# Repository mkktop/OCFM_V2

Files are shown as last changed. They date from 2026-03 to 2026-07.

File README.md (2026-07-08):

# OCFM_V2 - 明渠流量计

**Open Channel Flow Meter Firmware V2**

基于 STM32F407 的智能明渠流量计固件，通过超声波/雷达水位计测量水位，结合标准堰槽公式（巴歇尔槽、三角堰、矩形堰）计算瞬时流量和累计流量。适用于污水处理、水利灌溉、环保监测等场景。

## 功能特性

- **多堰槽类型支持** - 巴歇尔槽（25种：17种标准型 b=0.025~2.4m + 8种大型 b=3.05~12.19m，标准 CJ/T 3008.3）、三角堰（5种标准角度，ISO 1438）、矩形堰（4种标准宽度，ISO 1438）
- **传感器接口** - 支持雷达/超声波水位传感器，Modbus RTU 通信
- **实时数据采集** - 水位、瞬时流量、累计流量、温度实时监测
- **趋势图显示** - 双采样率折线图（10s / 5min），各30个数据点，Y轴自动缩放
- **历史数据记录** - 按日期分目录 CSV 存储，支持时间范围查询与聚合统计，默认保留 365 天（满足 HJ 15-2019 运行数据保存要求）
- **4-20mA 电流输出** - 可配置量程，PWM 驱动 V/I 转换，支持工厂校准
- **Modbus RTU 从机** - 标准保持寄存器映射，支持远程读写配置与数据采集
- **多级报警** - 上限/下限/上上限/下下限四组报警，带回差设置
- **4路继电器输出** - 可由报警或流量阈值驱动
- **数据持久化** - 累计流量双层保护（RTC备份寄存器 + EEPROM），断电不丢失
- **SD卡数据存储** - 历史数据、系统日志、用户日志、报警日志
- **LVGL 图形界面** - 2.8寸彩色 LCD，三级设置菜单，中英文切换，按键操作

## 硬件规格

| 项目 | 规格 |
|---|---|
| MCU | STM32F407VGTx (Cortex-M4, 168MHz, FPU) |
| LCD | 2.8寸 ST7789 (FSMC 8080并口) |
| 传感器接口 | UART1 RS485 (Modbus RTU 主机) |
| 通信接口 | UART2 RS485 (Modbus RTU 从机) + UART4 (4G模块 ML307, 未实现) |
| 无线 | LoRa (SX1278, SPI2, 未实现) |
| 存储 | EEPROM M24C02 (I2C2) + SD卡 (SDIO) |
| 温度 | CT1820 (1-Wire, PB0) |
| 按键 | 4路 (确认/上/下/位移) |
| 继电器 | 4路 |
| 蜂鸣器/背光 | TIM3 PWM |

## 软件架构

```
OCFM_V2/
├── Core/                    # STM32 HAL & CubeMX 生成代码
│   ├── Inc/global.h         # 全局配置、寄存器定义、SystemConfig_t
│   ├── Inc/rtc_time.h       # 统一 RTC 时间 API
│   └── Src/                 # 外设初始化 (main.c, freertos.c)
├── App/                     # 应用层
│   ├── ui/                  # LVGL UI (Tileview主屏、三级设置菜单、趋势图、历史查询、多语言)
│   ├── app_model.c/h        # 数据模型 (MVVM, Observer模式)
│   ├── app_config.c/h       # 系统配置 (EEPROM, getter/setter, 3秒延迟保存)
│   ├── app_flow_calc.c/h    # 流量计算 (堰槽公式, 累计流量双层持久化)
│   ├── app_sensor.c/h       # 传感器应用层 (Modbus主机封装, 首次上线自动同步)
│   ├── app_modbus_slave.c/h # Modbus从机 (寄存器映射, 写回调)
│   ├── app_alarm.c/h        # 报警滞回逻辑 (4级报警驱动4路继电器)
│   ├── app_current.c/h      # 4-20mA电流输出 (PWM → V/I转换, 工厂校准)
│   ├── app_button.c/h       # 按键处理 (按活动屏分发)
│   └── app_log.c/h          # 日志初始化与SD卡清除
├── Drivers/
│   ├── AT24C02/             # EEPROM 驱动
│   ├── Button/              # 按键驱动 (消抖/长按)
│   ├── CT1820/              # 温度传感器驱动
│   └── File/                # 文件系统抽象层
│       ├── file_driver.c/h  # FATFS 封装
│       ├── data_recorder.c/h# CSV 历史数据记录
│       └── log_manager.c/h  # 系统日志管理
├── Interface/
│   ├── modbus.c/h           # Modbus 协议栈
│   ├── modbus_master.c/h    # Modbus 主机
│   └── modbus_slave.c/h     # Modbus 从机
├── Middlewares/
│   ├── lvgl/                # LVGL 9.5.0
│   └── Third_Party/         # FreeRTOS, FatFs
└── Doc/                     # 硬件原理图 & 技术文档
```

## 技术栈

| 组件 | 版本 |
|---|---|
| RTOS | FreeRTOS 10.3.1 |
| GUI | LVGL 9.5.0 |
| 文件系统 | FatFs |
| HAL | STM32F4xx HAL |
| 构建工具 | Keil MDK-ARM (AC5) |

## FreeRTOS 任务架构

| 任务 | 栈 | 优先级 | 功能 |
|---|----|---|---|
| main_task | 8192 | Normal | LVGL 刷新 + 模块初始化 |
| log_task | 8192 | Low | 日志输出、EEPROM保存、数据记录、历史查询、RTC 更新 |
| button_scan_tas | 2048 | Low | 按键扫描 (10ms) |
| modbus_master_t | 1024 | Low | 传感器轮询 (10ms) |
| modbus_slave_ta | 1024 | Low | 从机通信 (10ms, 1s 数据同步) |

## 流量计算公式

- **巴歇尔槽 (Parshall Flume)** — Q = K × H^n（25种标准规格，标准 CJ/T 3008.3）
- **三角堰 (Triangular Weir)** — Q = K × (H+Kh)^2.5（90°/60°/45°/30°/22.5°，Kindsvater-Shen 方法，ISO 1438）
- **矩形堰 (Rectangular Weir)** — Q = K × b_eff × (H+Kh)^1.5（0.5/1.0/1.5/2.0m，Francis 公式 + 侧收缩修正，ISO 1438）

> 公式系数表、推导、标准出处与 HJ 15-2019 合规验证详见 [Doc/流量计算公式与标准说明.md](Doc/流量计算公式与标准说明.md)。

支持流量单位：L/s、L/min、L/h、m³/h、m³/s、m³/min、T/h、G/h

## Modbus RTU 寄存器映射 (部分)

| 地址 | 名称 | 类型 | 说明 |
|---|---|---|---|
| 0x0001 | REG_WUWEI | uint16 | 水位 |
| 0x0002 | REG_DISTANCE | uint16 | 距离 |
| 0x0003 | REG_TEMPERATURE | uint16 | 温度 |
| 0x0004-0x0005 | REG_INSTANT_FLOW | float | 瞬时流量 |
| 0x0006-0x0009 | REG_SUM_FLOW | double | 累计流量 |
| 0x000A-0x000D | 继电器状态 | uint16 x4 | 继电器 1-4 |
| 0x000E-0x0019 | 报警值 | float | 上限/下限/上上限/下下限及回差 (DH/DL) |
| 0x001A-0x001B | REG_TOTAL_TIME | uint32 | 累计计量时间 (秒)，与累计流量配对 |
| 0x0065-0x006F | 传感器参数 | uint16 | 量程、高度、滤波、地址、波特率等 |
| 0x0101-0x010D | 从机参数 | uint16/float | 渠道类型、流量单位、4-20mA量程、渠宽、堰高、水位上下限 |
| 0x1001-0x1006 | 工厂校准 | uint16 | 天线类型、距离偏移、4/20mA校准、恢复出厂、清除累计 |
| 0x0200-0x0206 | RTC 时间 | uint16 | 年月日时分秒星期 |

## 构建与烧录

1. 打开 Keil 工程文件 `MDK-ARM/OCFM_V2.uvprojx`
2. 编译: `Project -> Build Target` (F7)
3. 下载: `Flash -> Download` (F8)

> 硬件外设、引脚、时钟树配置通过 CubeMX 打开 `OCFM_V2.ioc` 修改后重新生成，请勿手动改动 HAL 初始化代码。

## 相关文档

| 文档 | 说明 |
|---|---|
| [CLAUDE.md](CLAUDE.md) | 项目开发指南（架构、规范、模块设计决策） |
| [Doc/流量计算公式与标准说明.md](Doc/流量计算公式与标准说明.md) | 堰槽公式系数表、推导、标准出处、HJ 15-2019 合规 |
| [Doc/数据记录CSV与报警标志说明.md](Doc/数据记录CSV与报警标志说明.md) | CSV 记录字段格式与报警标志位定义 |
| [Docs/Modbus寄存器表.md](Docs/Modbus寄存器表.md) | Modbus 寄存器完整映射表 |
| [Doc/](Doc/) | 硬件原理图 (.SchDoc)、PCB 文件、行业标准与技术规范 |

## UI 交互

- **主屏幕** — 垂直瓦片视图：详情页 / 趋势图页 / 累计流量页，上下键切换
- **设置菜单** — 三级结构：分类列表 -> 参数列表 -> 数值编辑，SHIFT键切换步进量级
- **历史查询** — 长按SHIFT进入，日期选择器 + 滑动窗口浏览
- **自动返回** — 设置页面 15 秒无操作自动返回主屏幕

## 许可证

本项目为私有项目，未经授权不得复制或分发。

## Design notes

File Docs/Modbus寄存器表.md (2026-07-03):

# OCFM_V2 Modbus RTU 寄存器表

**通信参数：** RS485 | Modbus RTU | 从机地址默认 1 | 波特率默认 9600 | 8N1

**寄存器类型：** 保持寄存器 (Function Code 03 读 / 06 写单寄存器 / 16 写多寄存器)

**数据格式：**
- `uint16` — 1 个寄存器（16 位无符号）
- `float` — 2 个连续寄存器（IEEE 754，大端序）
- `double` — 4 个连续寄存器（IEEE 754，大端序）

---

## 1. 实时数据区 (只读)

设备自动更新，用户只读。传感器离线时水位和距离不更新。

| 地址 | 名称 | 数据类型 | 单位 | 说明 |
|---|---|---|---|---|
| 0x0001 | 水位 (物位) | uint16 | mm | 水位 = 安装高度 - 传感器到水面距离 |
| 0x0002 | 距离 | uint16 | mm | 传感器到水面的距离 |
| 0x0003 | 温度 | uint16 | 0.1°C | 值 256 = 25.6°C |
| 0x0004~0x0005 | 瞬时流量 | float | 由单位寄存器决定 (默认 m³/h) | 当前瞬时流量值 |
| 0x0006~0x0009 | 累计流量 | double | m³ | 累计总量 |
| 0x000A | 继电器1状态 | uint16 | — | 0=断开, 1=吸合 (AH报警) |
| 0x000B | 继电器2状态 | uint16 | — | 0=断开, 1=吸合 (AL报警) |
| 0x000C | 继电器3状态 | uint16 | — | 0=断开, 1=吸合 (AAH报警) |
| 0x000D | 继电器4状态 | uint16 | — | 0=断开, 1=吸合 (AAL报警) |

> **注意：** 0x000A~0x000D 继电器状态寄存器只读，不允许写入。继电器由报警逻辑自动控制。

---

## 2. 报警参数区 (读写)

| 地址 | 名称 | 数据类型 | 单位 | 默认值 | 说明 |
|---|---|---|---|---|---|
| 0x000E~0x000F | 上限报警值 (AH) | float | m³/h | 19.44 | 流量 ≥ AH 触发，继电器1吸合 |
| 0x0010~0x0011 | 上限回差 (DH) | float | m³/h | 2.0 | 流量 < AH - DH 恢复 |
| 0x0012~0x0013 | 下限报警值 (AL) | float | m³/h | 0.0 | 流量 ≤ AL 触发，继电器2吸合 |
| 0x0014~0x0015 | 下限回差 (DL) | float | m³/h | 2.0 | 流量 > AL + DL 恢复 |
| 0x0016~0x0017 | 上上限报警值 (AAH) | float | m³/h | 100.0 | 流量 ≥ AAH 触发，继电器3吸合；恢复条件: 流量 < AAH - DH |
| 0x0018~0x0019 | 下下限报警值 (AAL) | float | m³/h | 0.0 | 流量 ≤ AAL 触发，继电器4吸合；恢复条件: 流量 > AAL + DL |

---

## 3. 传感器参数区 (读写)

> 写入后自动同步到传感器（传感器在线时）。参数在传感器首次上线时也会自动同步。

| 地址 | 名称 | 数据类型 | 单位 | 默认值 | 说明 |
|---|---|---|---|---|---|
| 0x0065 | 最大量程 | uint16 | mm | 5000 | 传感器量程上限 |
| 0x0066 | 安装高度 | uint16 | mm | 5000 | 传感器安装高度 |
| 0x0067 | 窗口宽度 (L1) | uint16 | — | 100 | 传感器窗口参数 |
| 0x0068 | 滤波次数 (L2) | uint16 | — | 2 | 传感器滤波参数 |
| 0x0069 | 延时时间 (L3) | uint16 | ms | 50 | 传感器采集延迟 |
| 0x006A | 盲区 (L4) | uint16 | mm | 50 | 测量盲区 |
| 0x006B | 窗口系数 (L5) | uint16 | — | 8 | W系数 |
| 0x006C | 测量系数 (L6) | uint16 | — | 3 | M系数 |
| 0x006D | 传感器地址 | uint16 | — | 1 | 传感器从机地址 (1~247) |
| 0x006E | 波特率 | uint16 | — | 2 | 1=4800, 2=9600, 3=14400, 4=19200, 5=38400, 6=56000, 7=57600, 8=115200 |
| 0x006F | 停止位/校验 | uint16 | — | 1 | 1=8N1, 2=8O1, 3=8N2, 4=8E1 |

---

## 4. 从机参数区 (读写)

| 地址 | 名称 | 数据类型 | 单位 | 默认值 | 说明 |
|---|---|---|---|---|---|
| 0x0101 | 渠道类型 | uint16 | — | 1 | 1=巴歇尔槽, 2=三角堰, 3=矩形堰 |
| 0x0102 | 水槽编号 | uint16 | — | 1 | 对应具体堰槽规格 (切换时自动填入默认水位上下限) |
| 0x0103 | 瞬时流量单位 | uint16 | — | 4 | 1=L/s, 2=L/min, 3=L/h, 4=m³/h, 5=m³/s, 6=m³/min, 7=T/h, 8=G/h |
| 0x0104 | 累计流量小数位 | uint16 | — | 1 | 累计流量显示的小数位数 |
| 0x0105~0x0106 | 4mA 量程 | float | m³/h | 0.0 | 4mA 对应的流量值 |
| 0x0107~0x0108 | 20mA 量程 | float | m³/h | 19.354 | 20mA 对应的流量值；不能超过当前槽型理论最大流量 × 1.2 |
| 0x0109 | 渠宽 | uint16 | mm | 0 | 矩形堰侧收缩修正用渠道宽度；0=全宽堰/未配置 |
| 0x010A | 堰高 | uint16 | mm | 0 | 矩形堰堰高 p (预留) |
| 0x010B~0x010C | 水位上限 | float | m | 见表 | 流量计算用的水位上限；切换渠道类型/水槽编号时自动填入默认值 |
| 0x010D~0x010E | 水位下限 | float | m | 见表 | 流量计算用的水位下限；切换渠道类型/水槽编号时自动填入默认值 |

---

## 5. 出厂校准区 (读写)

> **注意：** 4mA / 20mA 校准值写入后直接生效，请使用正确范围内数值。

| 地址 | 名称 | 数据类型 | 单位 | 默认值 | 说明 |
|---|---|---|---|---|---|
| 0x1001 | 天线类型 | uint16 | — | 1 | 传感器天线类型 |
| 0x1002 | 距离偏移 | uint16 | mm | 10 | 测量距离补偿值 |
| 0x1003 | 4mA 校准值 | uint16 | CCR | 1063 | TIM3 CH4 PWM 比较值；写入后立即驱动 PWM 输出 (Modbus 校准) |
| 0x1004 | 20mA 校准值 | uint16 | CCR | 5556 | TIM3 CH4 PWM 比较值；写入后立即驱动 PWM 输出 (Modbus 校准) |
| 0x1005 | 恢复出厂设置 | uint16 | — | 0 | 写入后触发恢复出厂，完成后自动复位为 0 (一次性触发) |
| 0x1006 | 清除累计量 | uint16 | — | — | 写 1 清除累计流量和累计时间 (一次性触发) |

---

## 6. RTC 时间区 (读写)

> 写入任意一个时间寄存器后，设备立即读取全部 7 个寄存器并更新 RTC。建议使用 FC16 一次性写入全部 7 个寄存器。

| 地址 | 名称 | 数据类型 | 范围 | 说明 |
|---|---|---|---|---|
| 0x0200 | 年 | uint16 | 2000~2099 | 如 2026 |
| 0x0201 | 月 | uint16 | 1~12 | — |
| 0x0202 | 日 | uint16 | 1~31 | 自动校验闰年 |
| 0x0203 | 时 | uint16 | 0~23 | — |
| 0x0204 | 分 | uint16 | 0~59 | — |
| 0x0205 | 秒 | uint16 | 0~59 | — |
| 0x0206 | 星期 | uint16 | 1~7 | 1=周一, 7=周日 |

---

## 附：测试要点

1. **读寄存器测试** — 用 FC03 从 0x0001 开始连续读取，验证实时数据是否正常更新（水位、距离、温度、流量）。
2. **写报警值测试** — 用 FC06 写入 AH 值，观察继电器状态变化；降低流量至恢复阈值，观察继电器释放。
3. **写配置测试** — 修改渠道类型 / 水槽编号 / 瞬时单位后，验证流量计算结果变化；断电重启后验证参数持久化。
4. **RTC 测试** — 用 FC16 一次写入 7 个时间寄存器 (0x0200~0x0206)，再读回验证。
5. **清除累计量** — 向 0x1006 写 1，读回 0x0006~0x0009 验证累计流量归零。
6. **恢复出厂** — 向 0x1005 写 1，断电重启后验证所有参数恢复默认值。
7. **传感器离线** — 断开传感器后约 15 秒判定离线，报警清除、继电器全部释放。

---

## 附：从机参数寄存器补充

| 地址 | 范围/默认值 | 说明 |
|---|---|---|
| 0x0109 渠宽 | 0~10000 mm；默认 0 | 0 表示未配置（按全宽堰计算） |
| 0x010A 堰高 | 0~10000 mm；默认 0 | 矩形堰堰高 p (预留) |
| 0x010B 水位上限 | 0~10 m；按槽型自动 | 详见 `flow_calc_formulas.md` 第 1 节 |
| 0x010D 水位下限 | 0~10 m；按槽型自动 | 详见 `flow_calc_formulas.md` 第 1 节 |

切换渠道类型 (0x0101) 或水槽编号 (0x0102) 时，0x010B/0x010D 会被自动覆盖为当前槽型的默认值，原有用户修改会丢失。

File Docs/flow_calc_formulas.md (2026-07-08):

# 明渠流量计算公式手册

> 源文件: [`App/app_flow_calc.c`](../App/app_flow_calc.c)（公式与系数） · [`App/app_sensor.c`](../App/app_sensor.c)（水位采集）
>
> 适用标准:
> - 巴歇尔槽 — **CJ/T 3008.3-1993**《城市排水流量堰槽测量标准 巴歇尔量水槽》（参照 ISO 9826:1991）
> - 薄壁堰 — **ISO 1438**（Kindsvater-Shen / Francis 方法）
> - 产品合规 — **HJ 15-2019**《超声波明渠污水流量计技术要求及检测方法》
>
> 内部计算基准单位: 瞬时流量 **Q = L/s**，水位 **H = m**。最终显示值经单位转换。

---

## 1. 计算总览

### 1.1 数据流

```
超声波/雷达传感器 ──RS485/Modbus──> 距离 (mm)
                                        │
                          水位 H = 安装高度 − 距离   (app_sensor.c)
                                        │
                        ┌───────────────┴───────────────┐
                        ▼                               ▼
              flow_calc_update() (每秒)         单位转换 (instant_unit)
                  ├─ 瞬时流量 Q (L/s)                   │
                  ├─ 累加累计流量 (double, m³)          ▼
                  └─ 累加累计时长 (uint32, s)      显示 / 4-20mA / Modbus
```

### 1.2 水位来源（不是直接读水位）

传感器（一次仪表）输出的是**探头到水面的距离**，二次仪表换算为水位（[app_sensor.c](../App/app_sensor.c)）：

```
distance_m  = 传感器读数(mm) / 1000
H (水位,m)  = height(安装高度,mm)/1000 − distance_m
若 H < 0 → H = 0      （距离大于安装高度，按 0 处理）
传感器离线 → H = 0，且累计时长不递增
```

- `height`（安装高度）通过 Modbus 寄存器 0x0066 / 设置菜单配置，默认 5000mm
- `range_max`（最大量程）默认 5000mm

### 1.3 水位上下限 H_min / H_max 的来源

`H_min` / `H_max` **不直接**用于计算，而是来自用户配置 `water_level_up` / `water_level_down`（Modbus 寄存器 0x010B/0x010D）：

- **首次切换渠道类型/水槽编号**时，系统从下文参数表读默认值，**自动填入**用户配置（`flow_calc_get_default_water_level()`）
- 之后用户可独立修改；**计算始终用用户配置值**，参数表里的 H_min/H_max 仅作初值
- 修改渠道类型或编号会**覆盖**当前用户配置的水位上下限

### 1.4 超量程钳位策略（三堰型通用）

```
H < H_min − 0.0001  →  Q = 0                  (低于下限，0.1mm 容差防浮点误判)
H > H_max           →  he = H_max + Kh        (钳位到上限计算)
                         Q = formula(he)        (堰用 Kh；巴歇尔槽无 Kh)
H_min ≤ H ≤ H_max   →  he = H + Kh
                         Q = formula(he)
```

---

## 2. 巴歇尔水槽 (Parshall Flume)

**标准**: CJ/T 3008.3-1993（参照 ISO 9826:1991） · 精度 2%~5%

### 2.1 公式

```
Q = K × H^n          (Q: L/s, H: m)
```

| 符号 | 含义 | 单位 |
|---|---|---|
| Q | 瞬时流量 | L/s |
| H | 测量水位 | m |
| K | 流量系数（含单位转换） | — |
| n | 指数 | — |

> 巴歇尔槽**不使用 Kh 水头修正**（区别于堰）。

### 2.2 参数表（25 种规格）

代码: [`s_channel_tbl[25]`](../App/app_flow_calc.c)，分三类：

#### 小型（1-5 号，喉宽 ≤ 0.228m）

| # | 喉宽 (m) | K | n | H_min | H_max | Q_min~Q_max (L/s) |
|:---:|:---:|:---:|:---:|:---:|:---:|:---:|
| 1 | 0.025 | 60.4 | 1.550 | 0.015 | 0.21 | 0.09 ~ 5.4 |
| 2 | 0.051 | 120.7 | 1.550 | 0.015 | 0.24 | 0.18 ~ 13.2 |
| 3 | 0.076 | 177.1 | 1.550 | 0.030 | 0.33 | 0.77 ~ 32.1 |
| **4** | **0.152** | **381.2** | **1.540** | 0.030 | 0.45 | 1.50 ~ 111.0 |
| 5 | 0.228 | 535.4 | 1.530 | 0.030 | 0.60 | 2.50 ~ 251.0 |

> 粗体 **4 号**（喉宽 0.152m，6 英寸）= HJ 15-2019 §6.3.2 流量测量误差检测所用槽型。

#### 标准型（6-17 号，喉宽 0.25 ~ 2.40m）

| # | 喉宽 (m) | K | n | H_min | H_max | Q_min~Q_max (L/s) |
|:---:|:---:|:---:|:---:|:---:|:---:|:---:|
| 6 | 0.250 | 561.0 | 1.513 | 0.030 | 0.60 | 3.00 ~ 250.0 |
| 7 | 0.300 | 679.0 | 1.521 | 0.030 | 0.75 | 3.50 ~ 400.0 |
| 8 | 0.450 | 1038.0 | 1.537 | 0.030 | 0.75 | 4.50 ~ 630.0 |
| 9 | 0.600 | 1403.0 | 1.548 | 0.050 | 0.75 | 12.50 ~ 850.0 |
| 10 | 0.750 | 1772.0 | 1.557 | 0.060 | 0.75 | 25.00 ~ 1100.0 |
| 11 | 0.900 | 2147.0 | 1.565 | 0.060 | 0.75 | 30.00 ~ 1250.0 |
| 12 | 1.000 | 2397.0 | 1.569 | 0.060 | 0.80 | 30.00 ~ 1500.0 |
| 13 | 1.200 | 2904.0 | 1.577 | 0.060 | 0.80 | 35.00 ~ 2000.0 |
| 14 | 1.500 | 3668.0 | 1.586 | 0.060 | 0.80 | 45.00 ~ 2500.0 |
| 15 | 1.800 | 4440.0 | 1.593 | 0.080 | 0.80 | 80.00 ~ 3000.0 |
| 16 | 2.100 | 5222.0 | 1.599 | 0.080 | 0.80 | 95.00 ~ 3600.0 |
| 17 | 2.400 | 6004.0 | 1.605 | 0.080 | 0.80 | 100.00 ~ 4000.0 |

> 1-17 号 K/n 取自 CJ/T 3008.3-1993 表 3。**17 号（2.40m）为标准型最大喉宽**，K/n 由序列趋势外推（n 从 1.513 单调递增至 1.605）。

#### 大型型（18-25 号，喉宽 3.05 ~ 15.24m）

| # | 喉宽 (m) | 对应 | K | n | H_min | H_max | Q_min~Q_max (L/s) |
|:---:|:---:|:---:|:---:|:---:|:---:|:---:|:---:|
| 18 | 3.050 | 10 ft | 7463 | 1.600 | 0.09 | 1.07 | 160 ~ 8280 |
| 19 | 3.660 | 12 ft | 8859 | 1.600 | 0.09 | 1.37 | 190 ~ 14680 |
| 20 | 4.570 | 15 ft | 10960 | 1.600 | 0.09 | 1.67 | 230 ~ 25040 |
| 21 | 6.100 | 20 ft | 14450 | 1.600 | 0.09 | 1.83 | 310 ~ 37970 |
| 22 | 7.620 | 25 ft | 17940 | 1.600 | 0.09 | 1.83 | 380 ~ 47160 |
| 23 | 9.140 | 30 ft | 21440 | 1.600 | 0.09 | 1.83 | 460 ~ 56330 |
| 24 | 12.190 | 40 ft | 28430 | 1.600 | 0.09 | 1.83 | 600 ~ 74700 |
| 25 | 15.240 | 50 ft | 35410 | 1.600 | 0.09 | 1.83 | 750 ~ 93040 |

> 18-25 号大型巴歇尔槽，**指数 n 固定 = 1.6**（ISO 9826 特征）。K 取自 CJ/T 3008.3-1993 表 4，与 ISO 9826 线性关系 `K ≈ 698.9·W(ft) + 474` 吻合（8 个规格偏差 < 0.04%）。

### 2.3 计算验证

4 号巴歇尔槽（0.152m），HJ 15 §6.3.2 检测点（H_max=0.45m 的 20%/50%/80%）：

```
H = 0.090m (20%):  Q = 381.2 × 0.090^1.540 = 9.35  L/s
H = 0.225m (50%):  Q = 381.2 × 0.225^1.540 = 38.33 L/s
H = 0.360m (80%):  Q = 381.2 × 0.360^1.540 = 79.04 L/s
```

---

## 3. 三角堰 (V-Notch Weir)

**标准**: ISO 1438, Kindsvater-Shen 方法

### 3.1 公式

```
Q = K × (H + Kh)^2.5                              (Q: L/s, H: m)
K = Ce × (8/15) × √(2g) × tan(θ/2) × 1000
```

| 符号 | 含义 | 单位 |
|---|---|---|
| Q | 瞬时流量 | L/s |
| H | 测量水位 | m |
| Kh | 水头修正（表面张力/粘滞效应） | m |
| Ce | 有效流量系数 | 无量纲 |
| g | 重力加速度 9.80665 | m/s² |
| θ | 堰口角度 | ° |

### 3.2 Ce 与 Kh 的确定

Ce 与 Kh 由 Kindsvater-Shen 方法对 ISO 1438 / USBR 图表的曲线拟合得到：

```
Ce      = 0.607165052 − 0.000874467×θ + 6.103933×10⁻⁶×θ²
Kh(ft)  = 0.01449 − 0.0003396×θ + 3.298×10⁻⁶×θ² − 1.062×10⁻⁸×θ³
Kh(m)   = Kh(ft) × 0.3048        ← 必须乘 0.3048 换算
```

> 有效范围: θ = 20° ~ 100°（USBR 推荐 25° ~ 100°）

### 3.3 各角度参数表

代码: [`s_triangular_weir_tbl[5]`](../App/app_flow_calc.c)

| # | θ | Ce | K (L/s) | **Kh (m)** | H_min | H_max | Q_min~Q_max (L/s) |
|:---:|:---:|:---:|:---:|:---:|:---:|:---:|:---:|
| 1 | 90° | 0.5779 | 1365.0 | **0.00085** | 0.05 | 0.40 | 0.88 ~ 140.7 |
| 2 | 60° | 0.5767 | 786.4 | **0.00113** | 0.05 | 0.35 | 0.48 ~ 57.7 |
| 3 | 45° | 0.5802 | 567.8 | **0.00150** | 0.05 | 0.30 | 0.35 ~ 28.4 |
| 4 | 30° | 0.5864 | 371.1 | **0.00213** | 0.05 | 0.25 | 0.23 ~ 11.9 |
| 5 | 22.5° | 0.5906 | 277.5 | **0.00256** | 0.05 | 0.25 | 0.18 ~ 8.90 |

> 90° 三角堰 Kh = 0.00085m 即 ISO 1438-1 标准值 **0.85mm**。

### 3.4 计算验证

90° 三角堰，H = 0.10m：

```
he = 0.10 + 0.00085 = 0.10085 m
Q  = 1365.0 × 0.10085^2.5
   = 1365.0 × 0.003230
   = 4.41 L/s
```

90° 三角堰，H = 0.05m（最低水头）：

```
he = 0.05 + 0.00085 = 0.05085 m
Q  = 1365.0 × 0.05085^2.5
   = 1365.0 × 0.000583
   = 0.80 L/s
```

---

## 4. 矩形堰 (Rectangular Weir)

**标准**: ISO 1438-1, **Kindsvater-Carter 方法**（主）+ Francis 公式（回退）

代码采用双路径：满足 ISO 适用条件时用更高精度的 Kindsvater-Carter 动态系数，否则回退到 Francis 固定系数，保证向后兼容与边界安全。

### 4.1 主公式（Kindsvater-Carter）

```
Q = Ce × (2/3) × √(2g) × be × he^1.5            (Q: L/s, H: m)

he = H + Kh          (有效水头, Kh = 0.001 m)
be = b + Kb          (有效宽度, 收缩堰 Kb>0, 全宽堰 Kb=0)
base = (2/3)·√(2g)·1000 ≈ 2952.46   (L/s 系数, Ce 无量纲)
```

| 符号 | 含义 | 单位 |
|---|---|---|
| Q | 瞬时流量 | L/s |
| H | 测量水位（水头） | m |
| P | 堰高（用户配置 `weir_height`，Modbus 0x010A） | m |
| b | 堰宽（参数表给定） | m |
| be | 有效宽度（含 Kb 修正） | m |
| B | 渠宽（用户配置 `channel_width`，Modbus 0x0109） | m |
| Ce | 有效流量系数（随 h/P、b/B 动态变化） | 无量纲 |
| Kh | 水头修正 0.001m | m |
| Kb | 宽度修正（ISO Figure 6，仅收缩堰） | m |

### 4.2 Ce 流量系数（ISO 1438-1）

**全宽堰**（B = 0 或 B ≤ b，无侧收缩）—— 解析公式：

```
Ce = 0.602 + 0.083 × (H/P)
```

**收缩堰**（B > b）—— 按 b/B 和 h/P 双线性插值查表（ISO 1438-1 Figure 5）：

| b/B ╲ h/P | 0.1 | 0.2 | 0.3 | 0.4 | 0.5 | 0.6 | 0.8 | 1.0 |
|:---:|:---:|:---:|:---:|:---:|:---:|:---:|:---:|:---:|
| 1.0 | 0.610 | 0.619 | 0.627 | 0.636 | 0.644 | 0.652 | 0.669 | 0.685 |
| 0.9 | 0.609 | 0.617 | 0.626 | 0.634 | 0.642 | 0.651 | 0.668 | 0.684 |
| 0.8 | 0.608 | 0.616 | 0.624 | 0.633 | 0.641 | 0.649 | 0.666 | 0.682 |
| 0.7 | 0.606 | 0.614 | 0.623 | 0.631 | 0.639 | 0.648 | 0.664 | 0.680 |
| 0.6 | 0.603 | 0.612 | 0.620 | 0.629 | 0.637 | 0.646 | 0.662 | 0.678 |
| 0.5 | 0.600 | 0.609 | 0.617 | 0.626 | 0.634 | 0.643 | 0.659 | 0.675 |
| 0.4 | 0.596 | 0.605 | 0.613 | 0.622 | 0.630 | 0.639 | 0.655 | 0.671 |
| 0.3 | 0.590 | 0.599 | 0.608 | 0.616 | 0.625 | 0.633 | 0.650 | 0.666 |
| 0.2 | 0.583 | 0.592 | 0.601 | 0.609 | 0.618 | 0.626 | 0.643 | 0.659 |

> 不确定度（95% 置信）：h/P < 1.0 时 ≤ 1.5%，h/P 1.0~1.5 时 ≤ 2.0%。

### 4.3 Kb 宽度修正（ISO 1438-1 Figure 6，收缩堰）

| b/B | 1.0 | 0.9 | 0.8 | 0.7 | 0.6 | 0.5 | 0.4 | 0.3 | 0.2 |
|:---:|:---:|:---:|:---:|:---:|:---:|:---:|:---:|:---:|:---:|
| Kb (m) | 0.0000 | 0.0018 | 0.0022 | 0.0024 | 0.0026 | 0.0028 | 0.0030 | 0.0032 | 0.0034 |

> 全宽堰 Kb = 0。

### 4.4 KC 法启用条件与 Francis 回退

**KC 法启用**需同时满足（ISO 1438-1 适用范围）：

```
堰高 P 已配置 (P > 0)        ← weir_height 寄存器 0x010A
且 h/P ≤ 1.0                 ← 水头不超过堰高
```

**回退到 Francis** 的情形（保证安全、避免外推失真）：

| 条件 | 原因 | 使用公式 |
|---|---|---|
| P = 0（未配置堰高） | 向后兼容，老配置不受影响 | Francis（固定 Cd=0.622） |
| h/P > 1.0（水头超堰高） | 超出 ISO KC 适用范围，外推不可信 | Francis |

Francis 回退公式（与旧实现一致）：

```
Q = 1838 × be × (H + 0.001)^1.5

全宽堰: be = b
收缩堰: be = b − 0.2×H     (若 be < 0 则 be = 0)
```

### 4.5 参数表

代码: [`s_rectangular_weir_tbl[4]`](../App/app_flow_calc.c)

| # | 堰宽 b (m) | Kh (m) | H_min | H_max |
|:---:|:---:|:---:|:---:|:---:|
| 1 | 0.50 | 0.001 | 0.05 | 0.50 |
| 2 | 1.00 | 0.001 | 0.05 | 0.60 |
| 3 | 1.50 | 0.001 | 0.05 | 0.70 |
| 4 | 2.00 | 0.001 | 0.05 | 0.80 |

> KC 法的 Ce 不在表中（运行时按 h/P、b/B 动态计算）。表里 Kh=0.001 两种方法都用。

### 4.6 计算验证

**HJ 15 §6.3.2 检测配置**：b=0.5m（1 号）、B=1.0m、P=0.25m → 收缩堰，b/B=0.5

H = 0.125m（50% 检测点，h/P=0.5）→ 走 KC 法：

```
Ce = 0.634        (b/B=0.5, h/P=0.5 查表)
Kb = 0.0028 m
be = 0.5 + 0.0028 = 0.5028 m
he = 0.125 + 0.001 = 0.126 m
Q  = 0.634 × 2952.46 × 0.5028 × 0.126^1.5 = 42.1 L/s
```

**全宽堰（B = 0）**，P = 0.30m、1.0m 堰宽、H = 0.10m（h/P=0.33）→ 走 KC 全宽分支：

```
Ce = 0.602 + 0.083 × 0.33 = 0.6294
Q  = 0.6294 × 2952.46 × 1.0 × 0.101^1.5 = 59.7 L/s
```

**P = 0（未配置）** → 回退 Francis，H = 0.30m、1.0m 堰宽：

```
he = 0.301 m, be = 1.0 (全宽)
Q  = 1838.0 × 1.0 × 0.301^1.5 = 303.5 L/s
```

---

## 5. 累计流量与累计时长

代码: [`app_flow_calc.c`](../App/app_flow_calc.c) `flow_calc_update()` / `flow_calc_load_total()`

### 5.1 累计算法（每秒）

```
瞬时流量 (L/s) ──×1s──> 累计流量增量 (L) ──÷1000──> 累加到 s_total_flow_m3 (double)
                                           s_total_time_sec ++ (uint32, 秒)
```

- 累计流量用 **double** 精度累加，避免 float 长期累加丢精度
- **传感器离线时**累计时长不递增（`H ≤ 0` 直接返回）
- 累计流量合法范围 [0, 1e12) m³，超限钳位 999999999999

### 5.2 双层持久化（防掉电丢数据）

| 层 | 周期 | 介质 | 内容 |
|---|---|---|---|
| **RTC 备份寄存器** | 每 **2 秒** | DR1/DR2/DR3/DR4 | total_flow(double 8B) + magic(0x5A5A5A5A) + total_time(uint32) |
| **EEPROM (M24C02)** | 每 **5 分钟** | 地址 232，24 字节 | `TotalFlowStorage_t {magic, total_flow, total_time, reserved}` |

- 备份寄存器：快速、非阻塞，依赖 VBAT 供电
- EEPROM：实际写入延迟到 `flow_calc_process()`（log_task 上下文），避免在定时器中阻塞 I²C
- 写 EEPROM 与 config 模块**共享互斥锁**（`app_config_eeprom_lock()`）

### 5.3 加载与校验

启动时 `flow_calc_load_total()` 按优先级加载：

```
1. 备份寄存器 magic == 0x5A5A5A5A ?  → 用备份寄存器值（最新）
2. 否则 EEPROM magic 匹配 ?          → 用 EEPROM 值，并同步回备份寄存器
3. 都无效                            → 默认 0
```

校验：total_flow ∈ [0, 1e12)，total_time < 0x80000000。

---

## 6. 精度与不确定度

### 6.1 系数来源

| 堰型 | 系数 | 来源 |
|---|---|---|
| 巴歇尔槽 1-17 号 | K/n | CJ/T 3008.3-1993 表 3 |
| 巴歇尔槽 18-25 号 | K | CJ/T 3008.3-1993 表 4 / ISO 9826 |
| 三角堰 | Ce, Kh | Kindsvater-Shen 拟合（ISO 1438 / USBR / Kulin & Compton 1975） |
| 矩形堰 | Ce 动态（KC）/ K=1838（Francis 回退），Kh=0.001 | ISO 1438-1 Kindsvater-Carter / Francis |

### 6.2 精度限制

| 因素 | 影响量 |
|---|---|
| 三角堰 Ce/Kh 曲线拟合误差 | ±0.5% |
| ISO 1438 方法固有不确定度 | ±1~2% |
| float 单精度（~7 位有效数字） | <0.01% |
| 22.5° 超出 USBR 推荐 25°~100° 范围 | 需现场标定验证 |
| 矩形堰 KC 法（h/P≤1） | ≤1.5%（ISO 不确定度） |
| 矩形堰 Francis 回退（P=0 或 h/P>1） | ±1~3%（固定 Cd） |
| 巴歇尔槽 17 号 K/n 外推值 | 待 CJ/T 3008.3 原文核实 |

### 6.3 改进方向

- 三角堰 22.5°：建议现场标定修正 Ce
- 17 号巴歇尔槽（2.40m）：建议用 CJ/T 3008.3-1993 表 3 原文值核实外推 K/n

---

## 7. 单位转换

计算结果 Q 固定以 L/s 输出，再按 `instant_unit` 配置转换（[`flow_convert_instant()`](../App/app_flow_calc.c)）：

| 单位 | 转换 | 枚举值 |
|---|---|---|
| L/s | Q × 1 | FLOW_UNIT_L_S |
| L/min | Q × 60 | FLOW_UNIT_L_MIN |
| L/h | Q × 3600 | FLOW_UNIT_L_H |
| m³/h | Q × 3.6 | FLOW_UNIT_M3_H |
| m³/s | Q / 1000 | FLOW_UNIT_M3_S |
| m³/min | Q / 1000 × 60 | FLOW_UNIT_M3_MIN |
| T/h | Q × 3.6（同 m³/h） | FLOW_UNIT_T_H |
| G/h（加仑/时） | Q × 3600 / 3.785411784 | FLOW_UNIT_G_H |

---

## 8. HJ 15-2019 合规对应

| HJ 15-2019 要求 | 本项目实现 |
|---|---|
| §6.3.2 流量测量误差检测：90° 三角堰 | 三角堰 1 号（90°，Kh 已修正） |
| §6.3.2 流量测量误差检测：矩形堰（b=0.5m, B=1.0m, p=0.25m） | 矩形堰 1 号 + 渠宽配置 + 侧收缩（KC 法，h/P≤1） |
| §6.3.2 流量测量误差检测：4 号巴歇尔槽 | 巴歇尔槽 4 号（0.152m） |
| §6.3.3-4 精密度检测：4 号巴歇尔槽（400mm 水位） | 巴歇尔槽 4 号 |
| §5 流量测量误差 ≤2% | 三角堰 Kh 修复后满足；矩形堰 KC 法满足；巴歇尔公式精度满足 |

---

## 9. 参考资料

1. **HJ 15-2019** — 《超声波明渠污水流量计技术要求及检测方法》（产品合规标准）
2. **CJ/T 3008.3-1993** — 《城市排水流量堰槽测量标准 巴歇尔量水槽》（参照 ISO 9826:1991）
3. **ISO 1438:2017** — Hydrometry — Open channel flow measurement using thin-plate weirs（薄壁堰）
4. **ISO 9826:1991** — 明渠水流测量 巴歇尔水槽和孙奈利水槽（大型巴歇尔槽）
5. **USBR Water Measurement Manual**, 3rd ed. (1997), Ch.7 — https://www.usbr.gov/tsc/techreferences/mands/wmm/
6. Kulin, G. & Compton, P.R. (1975). *Discharge Characteristics of Triangular-notch Thin-plate Weirs*. USGS Water Supply Paper 1617-B
7. LMNO Engineering — V-Notch Weir Calculator (Kindsvater-Shen 曲线拟合) — https://www.lmnoeng.com/Weirs/vweir.php
8. Francis, J.B. — *Lowell Hydraulic Experiments*（矩形堰经典公式）
9. Kindsvater, C.E. & Carter, R.W. (1959). *Discharge Characteristics of Rectangular Thin-Plate Weirs*. ASCE — 矩形堰 KC 方法原始论文

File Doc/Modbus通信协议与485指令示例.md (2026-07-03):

# Modbus 通信协议说明与 485 指令示例

> 适用固件：OCFM_V2（STM32F407 明渠流量计）
> 通信接口：UART2 / RS485，Modbus RTU 从机
> 本文档描述寄存器映射、连写规则及完整 485 指令示例（含 CRC）。

---

## 一、通信接口与默认参数

| 项目 | 默认值 | 说明 |
|---|---|---|
| 物理层 | RS485（半双工） | UART2 |
| 协议 | Modbus RTU | 8 数据位 |
| 从机地址 | **1** | 范围 1–247，写 0x006D 修改 |
| 波特率 | **9600** | 索引 2，写 0x006E 修改 |
| 停止位/校验 | **无校验 + 1 停止位** | 索引 1，写 0x006F 修改 |

> 修改通信参数（地址/波特率/停止位）后，设备会在下一周期重配 UART2。**主站必须同步切换自己的参数**才能继续通信。修改后约 3 秒落盘 EEPROM。

---

## 二、支持的功能码

| 功能码 | 名称 | 说明 |
|---|---|---|
| 0x03 | 读保持寄存器 | 一次最多读 125 个 |
| 0x06 | 写单个寄存器 | — |
| **0x10** | **写多个寄存器** | **一次最多写 123 个，支持连写** |

不支持的功能码（如 0x04、0x17）返回异常码 01（非法功能）。

---

## 三、寄存器地址总表

### 1. 实时数据区 0x0001–0x000D（只读，累计流量除外）

| 地址 | 名称 | 类型 | 单位/说明 | 读写 |
|---|---|---|---|---|
| 0x0001 | 水位 | uint16 | mm | 只读 |
| 0x0002 | 距离 | uint16 | mm | 只读 |
| 0x0003 | 温度 | uint16 | ×10 ℃（256 → 25.6℃） | 只读 |
| 0x0004–0x0005 | 瞬时流量 | float | m³/h 等（由单位设置决定） | 只读 |
| 0x0006–0x0009 | 累计流量 | double | m³ | **可写**（设基准值） |
| 0x000A | 继电器1状态 | uint16 | AH 报警 | 只读 |
| 0x000B | 继电器2状态 | uint16 | AL 报警 | 只读 |
| 0x000C | 继电器3状态 | uint16 | AAH 报警 | 只读 |
| 0x000D | 继电器4状态 | uint16 | AAL 报警 | 只读 |

### 2. 报警值区 0x000E–0x0019（float，可写）

| 地址 | 名称 | 类型 | 说明 |
|---|---|---|---|
| 0x000E–0x000F | AH | float | 上限报警值 |
| 0x0010–0x0011 | DH | float | 上限回差（AH 与 AAH 共用） |
| 0x0012–0x0013 | AL | float | 下限报警值 |
| 0x0014–0x0015 | DL | float | 下限回差（AL 与 AAL 共用） |
| 0x0016–0x0017 | AAH | float | 上上限报警值 |
| 0x0018–0x0019 | AAL | float | 下下限报警值 |

### 3. 累计计量时间 0x001A–0x001B（只读 uint32，秒）

### 4. 传感器参数区 0x0065–0x006F（uint16，可写，自动下发到传感器）

| 地址 | 名称 | 说明 |
|---|---|---|
| 0x0065 | RANGE_MAX | 最大量程 mm |
| 0x0066 | HEIGHT | 安装高度 mm |
| 0x0067 | L1 | 窗口宽度 |
| 0x0068 | L2 | 滤波次数 |
| 0x0069 | L3 | 延时时间 |
| 0x006A | L4 | 盲区 mm |
| 0x006B | L5 | W 系数 |
| 0x006C | L6 | M 系数 |
| 0x006D | ADDRESS | 从机地址（1–247） |
| 0x006E | BAUDE_RATE | 波特率索引（见下表） |
| 0x006F | STOP_BITS | 停止位/校验索引（见下表） |

### 5. 从机参数区 0x0101–0x010E（可写）

| 地址 | 名称 | 类型 | 说明 |
|---|---|---|---|
| 0x0101 | CANALS_TYPE | uint16 | 槽型：1=巴歇尔槽 2=三角堰 3=矩形堰 |
| 0x0102 | CHANNEL_ID | uint16 | 通道编号 |
| 0x0103 | INSTANT_UNIT | uint16 | 瞬时流量单位索引 |
| 0x0104 | SUM_POINT | uint16 | 累计流量小数位数 |
| 0x0105–0x0106 | RANGE_4MA | float | 4mA 对应流量 |
| 0x0107–0x0108 | RANGE_20MA | float | 20mA 对应流量 |
| 0x0109 | CHANNEL_WIDTH | uint16 | 渠宽 mm（矩形堰侧收缩修正） |
| 0x010A | WEIR_HEIGHT | uint16 | 堰高 mm |
| 0x010B–0x010C | WATER_LEVEL_UP | float | 水位上限 |
| 0x010D–0x010E | WATER_LEVEL_DOWN | float | 水位下限 |

### 6. RTC 时间区 0x0200–0x0206（uint16，可写，**整组校验**）

| 地址 | 名称 | 范围 |
|---|---|---|
| 0x0200 | 年 | 2000–2099 |
| 0x0201 | 月 | 1–12 |
| 0x0202 | 日 | 1–31 |
| 0x0203 | 时 | 0–23 |
| 0x0204 | 分 | 0–59 |
| 0x0205 | 秒 | 0–59 |
| 0x0206 | 星期 | 1–7 |

### 7. 出厂校准区 0x1001–0x1006（uint16，可写）

| 地址 | 名称 | 说明 |
|---|---|---|
| 0x1001 | ANTENNA_TYPE | 天线类型 |
| 0x1002 | DIS_OFFSET | 距离偏移 |
| 0x1003 | CALIBRATION_4MA | 4mA 校准值（联动电流输出） |
| 0x1004 | CALIBRATION_20MA | 20mA 校准值（联动电流输出） |
| 0x1005 | FACTORY_SETTING | 写 1 触发恢复出厂（一次性） |
| 0x1006 | CLEAR_TOTAL | 写 1 清零累计流量+时间（一次性） |

### 小结：分区地址区间总览

| 区 | 地址范围 | 寄存器数 | 读写 | 说明 |
|----|---|---|---|---|
| 1 实时数据 | 0x0001–0x000D | 13 | 只读 | 水位/距离/温度/瞬时流量/继电器（累计流量 0x0006–0x0009 例外可写）|
| ↳ 累计流量 | 0x0006–0x0009 | 4 | **可写** | double，主站可设基准值 |
| 2 报警值 | 0x000E–0x0019 | 12 | 可写 | 6 个 float（AH/DH/AL/DL/AAH/AAL）|
| 3 累计时间 | 0x001A–0x001B | 2 | 只读 | uint32 秒 |
| 4 传感器参数 | 0x0065–0x006F | 11 | 可写 | uint16（量程/高度/L1–L6/通信参数），自动下发传感器 |
| 5 从机参数 | 0x0101–0x010E | 14 | 可写 | 6 uint16 + 4 float |
| 6 RTC | 0x0200–0x0206 | 7 | 可写 | 整组校验 |
| 7 出厂校准 | 0x1001–0x1006 | 6 | 可写 | uint16（含 2 个一次性动作）|

> **区间之间有地址间隙（未映射）**：0x001C–0x0064、0x0070–0x0100、0x010F–0x01FF、0x0207–0x1000。
> 跨间隙或跨只读段的连写会被整体拒绝（见第五章）。

---

## 四、数据类型与字节序

设备采用 **Modbus 大端字顺序（ABCD / Big-endian）**：多字寄存器的高字存在低地址。

### float（占 2 个寄存器，IEEE 754）

示例：float `10.0` = 0x41200000
- 寄存器 N（低地址）= 0x4120（高字）
- 寄存器 N+1 = 0x0000（低字）

### double（占 4 个寄存器，IEEE 754）

示例：double `1234.5` = 0x40934A0000000000
- 寄存器 N = 0x4093，N+1 = 0x4A00，N+2 = 0x0000，N+3 = 0x0000

### uint32（占 2 个寄存器，大端）

高字在前。

> 在 Modbus Poll 等工具中，float/double 字节序选择 **Big-endian** 或 **ABCD (byte swap = none)**。

---

## 五、连写规则（重要）

本设备已实现标准 Modbus 连写（0x10），遵循以下规则：

### ✅ 区内连写：正常生效

一次 0x10 写**同一功能区**内连续的参数，全部生效。例如：
- 连写 6 个报警值（0x000E–0x0019，12 寄存器）
- 连写多个传感器参数（0x0065–0x006C）
- 连写 4mA+20mA 量程（0x0105–0x0108）

### ❌ 跨区连写 / 含只读地址：整体拒绝

若一次 0x10 的地址范围出现以下任一情况，设备返回异常 `ILLEGAL_DATA_ADDR (0x02)`，**不做任何写入（原子拒绝）**：
- 跨越两个功能区（中间有未映射地址间隙）
- 范围内含只读寄存器（水位/距离/温度/瞬时流量/继电器状态/累计时间）

### 写只读寄存器（0x06 / 0x10）：返回异常

写只读寄存器返回 `ILLEGAL_DATA_ADDR (0x02)`。

### 持久化

- 普通参数：3 秒去抖后合并写入 EEPROM（一次连写只产生 1 次写操作）。
- 一次性动作（工厂复位 / 清零）：立即执行。
- 累计流量写入（0x0006–0x0009）：立即更新，走独立持久化。

---

## 六、通信参数索引表

### 波特率索引（0x006E）

| 索引 | 波特率 | | 索引 | 波特率 |
|---|---|-|---|---|
| 1 | 4800 | | 5 | 38400 |
| 2 | **9600（默认）** | | 6 | 56000 |
| 3 | 14400 | | 7 | 57600 |
| 4 | 19200 | | 8 | 115200 |

### 停止位/校验索引（0x006F）

| 索引 | 配置 |
|---|---|
| 1 | **无校验 + 1 停止位（默认）** |
| 2 | 奇校验 + 1 停止位 |
| 3 | 无校验 + 2 停止位 |
| 4 | 偶校验 + 1 停止位 |

> Modbus RTU 在使用校验位（奇/偶）时为 8 数据位；无校验时通常配 8-N-1 或 8-N-2。

---

## 七、485 指令示例（从机地址 01，已含 CRC）

> CRC 为 Modbus CRC-16，**低字节在前、高字节在后**。

### 1. 读操作（0x03）

**读水位（0x0001，单个）**
```
请求: 01 03 00 01 00 01 D5 CA
响应: 01 03 02 09 C4 BF 87        // 水位 = 0x09C4 = 2500 mm
```

**连读实时数据（0x0001 起 13 个：水位到继电器4）**
```
请求: 01 03 00 01 00 0D D5 CF
响应: 01 03 1A [26字节数据] [CRC]  // 含水位/距离/温度/瞬时流量/累计流量/继电器
```

**连读报警值（0x000E 起 12 个 = 6 个 float）**
```
请求: 01 03 00 0E 00 0C 24 0C
```

**读累计流量（0x0006 起 4 个 = double）**
```
请求: 01 03 00 06 00 04 A4 08
响应示例: 01 03 08 40 93 4A 00 00 00 00 00 3C 84   // = 1234.5 m³
```

**读 RTC（0x0200 起 7 个）**
```
请求: 01 03 02 00 00 07 05 B0
```

### 2. 写单个寄存器（0x06）

**写量程 RANGE_MAX = 5000（0x0065）**
```
请求/响应: 01 06 00 65 13 88 94 83
```

**写从机地址 = 2（0x006D）** → 改后需用新地址通信
```
01 06 00 6D 00 02 99 D6
```

**写波特率 = 9600（0x006E，索引 2）** → 改后主站也要切到 9600
```
01 06 00 6E 00 02 69 D6
```

**清零累计流量（0x1006 写 1，一次性）**
```
01 06 10 06 00 01 AC CB
```

**恢复出厂设置（0x1005 写 1，一次性）**
```
01 06 10 05 00 01 5C CB
```

### 3. 连写（0x10）

**连写 AH + DH（0x000E 起 4 个：AH=10.0, DH=0.5）**
```
请求: 01 10 00 0E 00 04 08 41 20 00 00 3F 00 00 00 B7 87
响应: 01 10 00 0E 00 04 A0 09
```
> `41 20 00 00`=10.0，`3F 00 00 00`=0.5（float 大端）

**连写传感器量程 + 高度（0x0065 起 2 个：5000, 3000）**
```
请求: 01 10 00 65 00 02 04 13 88 0B B8 B6 54
响应: 01 10 00 65 00 02 [CRC]
```
> 同时会自动下发到超声波传感器。

**连写 4mA + 20mA 量程（0x0105 起 4 个：0.0, 100.0）**
```
请求: 01 10 01 05 00 04 08 00 00 00 00 42 C8 00 00 2D 71
响应: 01 10 01 05 00 04 [CRC]
```

**连写累计流量 SUM_FLOW = 12345.678（0x0006 起 4 个 double）**
```
请求: 01 10 00 06 00 04 08 40 C8 1C D6 C8 B4 39 58 D5 EC
响应: 01 10 00 06 00 04 [CRC]
```

**连写 6 个报警值（0x000E 起 12 个）**
```
请求: 01 10 00 0E 00 0C 18
      41 20 00 00  (AH=10.0)
      3F 00 00 00  (DH=0.5)
      40 00 00 00  (AL=2.0)
      3E 4C CC CD  (DL=0.2)
      41 70 00 00  (AAH=15.0)
      3F 80 00 00  (AAL=1.0)
      E8 A9        (CRC)
```

**写 RTC（0x0200 起 7 个：2026-06-22 15:30:00 星期一）**
```
请求: 01 10 02 00 00 07 0E 07 EA 06 16 0F 1E 00 01 8B C8
      年=0x07EA(2026) 月=06 日=22 时=0F(15) 分=1E(30) 秒=00 周=01
响应: 01 10 02 00 00 07 [CRC]
```
> RTC 整组校验，日期非法则丢弃不更新。

### 3-1. 每个可写区域"全部连写"示例

下面给出**每个可写区域整区一次性连写**的完整指令。每条都是把该区所有寄存器一次写满，可直接复制使用（从机地址 01，已含 CRC）。

**① 累计流量区 0x0006–0x0009（4 reg, double）= 0（清零基准）**
```
请求: 01 10 00 06 00 04 08 00 00 00 00 00 00 00 00 BE 72
响应: 01 10 00 06 00 04 21 CB
```

**② 报警值区 0x000E–0x0019（12 reg = 6 float）全写**
```
请求: 01 10 00 0E 00 0C 18
      41 20 00 00  (AH  = 10.0)
      3F 00 00 00  (DH  = 0.5)
      40 00 00 00  (AL  = 2.0)
      3E 4C CC CD  (DL  = 0.2)
      41 70 00 00  (AAH = 15.0)
      3F 80 00 00  (AAL = 1.0)
      E8 A9        (CRC)
响应: 01 10 00 0E 00 0C A1 CF
```

**③ 传感器参数区 0x0065–0x006F（11 reg, uint16）全写**
```
请求: 01 10 00 65 00 0B 16
      13 88  (RANGE_MAX = 5000)
      0B B8  (HEIGHT    = 3000)
      00 64  (L1        = 100)
      00 05  (L2        = 5)
      00 14  (L3        = 20)
      00 C8  (L4        = 200)
      00 00  (L5        = 0)
      00 00  (L6        = 0)
      00 01  (ADDRESS   = 1)
      00 02  (BAUD      = 2 → 9600)
      00 01  (STOP      = 1 → 无校验1停止位)
      42 DF  (CRC)
响应: 01 10 00 65 00 0B 91 D1
```
> ⚠️ 含 ADDRESS/BAUD/STOP，写入后设备重配 UART2，主站须同步切换参数。
> 这些传感器参数会自动经 UART1 下发到超声波传感器。

**④ 从机参数区 0x0101–0x010E（14 reg = 6 uint16 + 4 float）全写**
```
请求: 01 10 01 01 00 0E 1C
      00 01        (CANALS_TYPE      = 1 巴歇尔槽)
      00 01        (CHANNEL_ID       = 1)
      00 04        (INSTANT_UNIT     = 4 m³/h)
      00 03        (SUM_POINT        = 3 小数位)
      00 00 00 00  (RANGE_4MA        = 0.0)
      42 C8 00 00  (RANGE_20MA       = 100.0)
      01 F4        (CHANNEL_WIDTH    = 500)
      01 2C        (WEIR_HEIGHT      = 300)
      40 00 00 00  (WATER_LEVEL_UP   = 2.0)
      3E 4C CC CD  (WATER_LEVEL_DOWN = 0.2)
      8A 9B        (CRC)
响应: 01 10 01 01 00 0E 11 F1
```

**⑤ RTC 区 0x0200–0x0206（7 reg）全写**（见上方"写 RTC"示例）
```
请求: 01 10 02 00 00 07 0E 07 EA 06 16 0F 1E 00 01 8B C8
响应: 01 10 02 00 00 07 80 73
```

**⑥ 出厂校准区 0x1001–0x1006（6 reg, uint16）全写**
```
请求: 01 10 10 01 00 06 0C
      00 01  (ANTENNA_TYPE     = 1)
      00 00  (DIS_OFFSET       = 0)
      04 27  (CALIBRATION_4MA  = 1063)
      15 B4  (CALIBRATION_20MA = 5556)
      00 00  (FACTORY_SETTING  = 0, 不触发)
      00 00  (CLEAR_TOTAL      = 0, 不触发)
      26 50  (CRC)
响应: 01 10 10 01 00 06 15 0B
```
> 一次性动作寄存器（FACTORY_SETTING/CLEAR_TOTAL）写 0 不触发；要触发单写 0x06 写 1。

> 只读区（实时数据 0x0001–0x000D 除累计流量、累计时间 0x001A–0x001B）整区连写会被拒绝，无连写示例。

### 4. 异常响应示例

**写只读寄存器（0x0001 水位）→ 异常 02**
```
请求: 01 06 00 01 00 00 ...
响应: 01 86 02 C3 A1        // 0x86=0x06|0x80, 0x02=ILLEGAL_DATA_ADDR
```

**跨区连写（如报警区跨到传感器参数区）→ 异常 02**
```
请求: 01 10 00 0E ... （跨过未映射间隙）
响应: 01 90 02 CD C1        // 0x90=0x10|0x80, 0x02=ILLEGAL_DATA_ADDR
```

### 异常码速查

| 异常码 | 含义 | 触发场景 |
|---|---|---|
| 01 | 非法功能 | 不支持的功能码 |
| 02 | 非法数据地址 | 写只读 / 跨区连写 / 地址未映射 |
| 03 | 非法数据值 | 数量超范围（0x03>125, 0x10>123）等 |

---

## 八、集成注意事项

1. **一次连写只写同一功能区**。要配置多个区的参数，分多次 0x10 下发。
2. **改通信参数后立即同步主站**：写 0x006D/0x006E/0x006F 后设备重配 UART2，主站要在下一帧前切换匹配的地址/波特率/校验。
3. **写传感器参数会自动下发**：0x0065–0x006C、0x1001–0x1002 变更后经 UART1 异步写入超声波传感器（需传感器在线）。
4. **float/double 字节序**：Big-endian（高字在前），工具里选 ABCD。
5. **一次性动作寄存器**：写 1 触发后设备自动清零，无需主站回写 0。
6. **累计流量可写**：用于校准/设基准值，写 0x0006–0x0009（4 个寄存器，double）。
7. **CRC**：低字节在前。

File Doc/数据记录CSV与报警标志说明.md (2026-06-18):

# SD 卡数据记录 CSV 字段与报警标志说明

> 本文档说明 OCFM_V2 明渠流量计固件写入 SD 卡的 CSV 数据记录格式、各字段含义，以及最后一列 `alarm_flags`（报警标志位）的取值规则，供设备运维人员、数据监管人员查阅，亦供工程溯源。
>
> 实现代码：[Drivers/File/data_recorder.c](../Drivers/File/data_recorder.c)（记录器）、[Core/Src/freertos.c](../Core/Src/freertos.c)（定时记录与标志位组装）、[App/app_alarm.c](../App/app_alarm.c)（报警判定）
>
> 最后修订：2026-06-16

---

## 目录

1. [概述](#1-概述)
2. [CSV 字段说明](#2-csv-字段说明)
3. [alarm_flags 报警标志位定义](#3-alarm_flags-报警标志位定义)
4. [数值速查表](#4-数值速查表)
5. [报警触发与恢复阈值](#5-报警触发与恢复阈值)
6. [读取示例与解读](#6-读取示例与解读)
7. [常见问题（FAQ）](#7-常见问题faq)
8. [修订记录](#8-修订记录)

---

## 1. 概述

设备按固定周期将一组工况数据以 CSV（逗号分隔）格式追加写入 SD 卡，用于历史追溯、数据导出与监管留档。满足 HJ 15-2019《超声波明渠污水流量计技术要求及检测方法》对运行数据长期保存的要求。

| 项目 | 说明 |
|---|---|
| **存储路径** | `/data/YYYY/MM/DD.csv`（按日期分文件） |
| **记录周期** | 默认 60 秒一条（`DATA_RECORD_INTERVAL_MS`） |
| **保留期限** | 配置默认声明 365 天（`retention_days = 365`），但清理函数当前**未接入，实际不会自动清理**，数据持续写入直至 SD 卡写满 |
| **文件编码** | ASCII，行尾 `\r\n`（Windows 换行），UTF-8 友好 |
| **首行** | CSV 表头，定义各列字段名 |

CSV 表头（首行）固定为：

```
timestamp,water_level,instant_flow,total_flow,total_time,temperature,alarm_flags
```

---

## 2. CSV 字段说明

| 列序 | 字段名 | 单位 | 格式 | 含义 |
|:---:|---|---|---|---|
| 1 | `timestamp` | — | `YYYY-MM-DD HH:MM:SS` | 记录时刻（设备 RTC 时间） |
| 2 | `water_level` | m | 3 位小数 | 实测水位（安装高度 − 测距）；传感器离线时为 `0` |
| 3 | `instant_flow` | m³/h | 6 位小数 | 瞬时流量（内部 L/s × 3.6 换算） |
| 4 | `total_flow` | m³ | 6 位小数 | 开机以来的累计流量（double 精度） |
| 5 | `total_time` | 秒 | 整数 | 累计计量时间 |
| 6 | `temperature` | °C | 1 位小数 | 介质/环境温度；传感器无温度时为 `0` |
| 7 | `alarm_flags` | — | 整数 | 报警标志位（位掩码，详见第 3 节） |

> **注：** 报警判定基于**瞬时流量（m³/h）**与设定的报警阈值比较，即第 3 列与第 7 列同源。

---

## 3. alarm_flags 报警标志位定义

`alarm_flags` 是一个 **位掩码（bitmask）**，共 4 个有效位，每 1 位对应 1 路报警是否处于**触发中**状态。该位在记录数据时由 `log_task` 实时读取各报警状态组装而成（[Core/Src/freertos.c:276-281](../Core/Src/freertos.c#L276-L281)）：

```c
uint16_t flags = 0;
if (app_alarm_get_state(ALARM_TYPE_AH)  == ALARM_STATE_ACTIVE) flags |= 0x0001;
if (app_alarm_get_state(ALARM_TYPE_AL)  == ALARM_STATE_ACTIVE) flags |= 0x0002;
if (app_alarm_get_state(ALARM_TYPE_AAH) == ALARM_STATE_ACTIVE) flags |= 0x0004;
if (app_alarm_get_state(ALARM_TYPE_AAL) == ALARM_STATE_ACTIVE) flags |= 0x0008;
```

| 位 | 掩码 | 报警类型 | 通俗含义 | 对应继电器 |
|:---:|:---:|:---:|---|---|
| bit0 | `0x0001`（十进制 **1**） | AH  | 流量偏高（超过上限） | relay1 / PA4 |
| bit1 | `0x0002`（十进制 **2**） | AL  | 流量偏低（低于下限） | relay2 / PA5 |
| bit2 | `0x0004`（十进制 **4**） | AAH | 流量严重偏高（超过上上限） | relay3 / PA6 |
| bit3 | `0x0008`（十进制 **8**） | AAL | 流量严重偏低（低于下下限） | relay4 / PA7 |

- bit4 ~ bit15 目前**未使用**，预留扩展。
- 值为 `0` 表示该时刻**没有任何报警**处于触发状态。
- 同一时刻可能多个报警同时触发，故 `alarm_flags` 的值是若干掩码之和。

> 该标志位不仅用于写入，历史查询时还可用 `filter_alarm_only` + `flags_mask` 筛选“仅含报警的记录”（[data_recorder.c:341](../Drivers/File/data_recorder.c#L341)）。

---

## 4. 数值速查表

无需理解位运算，直接按下表对照即可。日常最常见的是 **0（正常）** 与 **5（高报叠加）**。

| 数值 | 二进制 | 含义 |
|:---:|:---:|---|
| **0** | `0000` | 一切正常，无报警 |
| **1** | `0001` | 流量偏高（上限 AH） |
| **5** | `0101` | 流量偏高且严重偏高（AH + AAH，最常见的高报叠加） |
| **2** | `0010` | 流量偏低（下限 AL） |
| **10** | `1010` | 流量偏低且严重偏低（AL + AAL，低报叠加） |
| 4 | `0100` | 仅严重偏高（理论上短暂出现，AAH 触发但 AH 已恢复） |
| 8 | `1000` | 仅严重偏低（理论上短暂出现，AAL 触发但 AL 已恢复） |
| 15 | `1111` | 四路报警全部触发（极端情况） |

> **说明：** AH 与 AAH 同属“高报侧”，AL 与 AAL 同属“低报侧”，阈值存在包含关系（详见第 5 节）。因此正常运行只会出现 `0 / 1 / 5 / 2 / 10` 等几种组合，**不会出现 `3`（同时偏高又偏低）这类矛盾值**。偶发的 `4` 或 `8` 出现在报警恢复过渡瞬间（高报先恢复上限、再恢复上上限的间隔周期内）。

---

## 5. 报警触发与恢复阈值

报警判定由 [app_alarm_update()](../App/app_alarm.c) 每秒执行一次，基于**瞬时流量（m³/h）**与设定阈值比较。为避免流量在阈值附近抖动导致继电器频繁吸合/断开，每路报警均设有**滞回（回差）**：

| 报警类型 | 触发条件 | 恢复条件 | 回差来源 |
|---|---|---|---|
| AH（上限） | 流量 ≥ AH | 流量 < AH − DH | 独立 DH |
| AAH（上上限） | 流量 ≥ AAH  | 流量 < AAH − DH  | **与 AH 共用 DH** |
| AL（下限） | 流量 ≤ AL | 流量 > AL + DL | 独立 DL |
| AAL（下下限） | 流量 ≤ AAL  | 流量 > AAL + DL  | **与 AL 共用 DL** |

> **关键：** AAH / AAL 没有独立的回差值，分别与 AH / AL 共用 DH / DL。
>
> **离线保护：** 传感器离线时，所有报警立即解除、继电器全部断开，`alarm_flags` 归 `0`。

**参数含义：**

| 参数 | 说明 |
|---|---|
| `AH` / `AAH` | 上限 / 上上限报警阈值（m³/h），AAH > AH |
| `AL` / `AAL` | 下限 / 下下限报警阈值（m³/h），AAL < AL |
| `DH` | 高报侧回差（m³/h），AH 与 AAH 共用 |
| `DL` | 低报侧回差（m³/h），AL 与 AAL 共用 |

以上阈值与回差均可通过设置菜单或 Modbus 寄存器（报警值分组 `0x000E ~ 0x0019`）配置。

---

## 6. 读取示例与解读

### 示例 1：正常工况

```
timestamp,water_level,instant_flow,total_flow,total_time,temperature,alarm_flags
...
2026-06-16 14:30:00,0.523,12.450000,384.120000,3600,24.5,0
```

解读：14:30:00 时刻，水位 0.523 m，瞬时流量 12.45 m³/h，累计流量 384.120 m³，累计计量 3600 秒，温度 24.5 ℃，`alarm_flags = 0` → **无报警，工况正常**。

### 示例 2：高报叠加

```
2026-06-16 14:31:00,0.812,28.600000,392.050000,3660,24.6,5
```

解读：`alarm_flags = 5 = 1 (AH) + 4 (AAH)` → **瞬时流量 28.6 m³/h 已超过上限，并进一步超过上上限，AH 与 AAH 两路高报继电器同时动作**。

### 示例 3：低报叠加

```
2026-06-16 14:32:00,0.105,1.200000,392.380000,3720,24.6,10
```

解读：`alarm_flags = 10 = 2 (AL) + 8 (AAL)` → **瞬时流量 1.2 m³/h 已低于下限，并进一步低于下下限，AL 与 AAL 两路低报继电器同时动作**。

---

## 7. 常见问题（FAQ）

**Q1：为什么报警值是 5 而不是 1？**
A：流量是连续变化的，持续上升时会先过 AH（此时记 `1`），再过 AAH，两个报警同时处于触发态，标志位即变为 `5`。流量回落时则会先退出 AAH 变回 `1`，再退出 AH 变回 `0`。

**Q2：alarm_flags 和继电器输出有什么关系？**
A：一一对应。标志位中有 `1`（bit0）即上限继电器吸合；为 `5` 即上限、上上限两路继电器均动作。现场接线与继电器对应的受控设备（如阀门、泵、声光报警器）据此联动。

**Q3：屏幕上显示文字，CSV 里为什么是数字？**
A：现场屏幕以“正常 / 偏高 / 偏低”等文字直观展示；CSV 采用位掩码数字是为了节省存储空间、便于程序批量解析与历史报警筛选，也满足长期保存（≥1 年）的监管要求。

**Q4：如果一直显示 0 是否正常？**
A：正常，说明这段时间瞬时流量始终处于设定的上下限区间内。若怀疑阈值设置不当导致“从不报警”，可在设置菜单中检查 AH / AL / AAH / AAL 及回差 DH / DL 是否合理。

**Q5：传感器离线时 alarm_flags 会怎样？**
A：传感器离线时所有报警立即解除、继电器断开，`alarm_flags = 0`，同时水位列可能记为 `0`，需结合瞬时流量列综合判断是否为真实停流还是传感器掉线。

**Q6：怎么从 CSV 中筛出所有发生过报警的记录？**
A：筛选 `alarm_flags` 列 **不为 0** 的所有行即可；如需精确到某一路报警（如仅上上限 AAH），筛选 `alarm_flags & 0x0004 != 0`（即该列数值按位与 4 不为 0）的行。

---

## 8. 修订记录

| 日期 | 版本 | 内容 |
|---|---|---|
| 2026-06-16 | v1.0 | 初始版本：CSV 字段、alarm_flags 位定义、数值速查、报警阈值、示例与 FAQ |

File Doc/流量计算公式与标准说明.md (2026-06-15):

# 明渠流量计算公式与标准说明

> 本文档说明 OCFM_V2 明渠流量计固件中三种标准量水堰槽的流量计算公式、系数取值、标准出处，用于工程校核与 HJ 15-2019《超声波明渠污水流量计技术要求及检测方法》型式检测合规验证。
>
> 实现代码：[App/app_flow_calc.c](../App/app_flow_calc.c)
>
> 最后修订：2026-06-14（修正三角堰 Kh 单位混淆错误）

---

## 目录

1. [计算基础](#1-计算基础)
2. [巴歇尔槽（Parshall Flume）](#2-巴歇尔槽parshall-flume)
3. [三角堰（V 型薄壁堰）](#3-三角堰v-型薄壁堰)
4. [矩形堰（矩形薄壁堰）](#4-矩形堰矩形薄壁堰)
5. [HJ 15-2019 合规验证](#5-hj-15-2019-合规验证)
6. [修订记录](#6-修订记录)
7. [标准文档清单与获取](#7-标准文档清单与获取)

---

## 1. 计算基础

| 项目 | 说明 |
|---|---|
| **水位测量** | 超声波/雷达传感器测距，水位 `H = 安装高度 − 距离`（单位 m） |
| **流量基准单位** | 内部计算统一使用 **L/s**，显示按 `instant_unit` 配置转换 |
| **累计流量** | 使用 `double` 精度累加（防精度丢失），单位 m³ |
| **重力加速度** | `g = 9.80665 m/s²`（标准重力） |
| **堰型选择** | `canals_type`（1=巴歇尔槽 / 2=三角堰 / 3=矩形堰），`channel_id` 选具体规格 |
| **水位钳位** | `H > water_level_up` → 按 `water_level_up` 计算；`H < water_level_down` → 流量归零 |

---

## 2. 巴歇尔槽（Parshall Flume）

### 2.1 公式

```
Q = K · H^n    （Q 单位 L/s，H 单位 m）
```

- 巴歇尔槽为**短喉道量水槽**，**不使用水头修正 Kh**（区别于薄壁堰）
- 仅适用于**自由流**条件（下游淹没度低于临界值，通常 `H₂/H₁ < 0.6~0.7`）

### 2.2 标准出处

| 标准 | 说明 |
|---|---|
| **CJ/T 3008.3-1993** | 《城市排水流量堰槽测量标准 巴歇尔量水槽》（本项目系数来源） |
| ISO 9826:1991 | 《明渠水流测量——巴歇尔水槽和孙奈利水槽》（CJ/T 参照） |
| ASTM D1941 | 美国材料试验协会巴歇尔槽标准 |

> 测量精度：2%~5%（依据 CJ/T 3008.3-1993）

### 2.3 系数表（25 种规格：1-17 标准型 + 18-25 大型，对应代码 [s_channel_tbl](../App/app_flow_calc.c)）

| 编号 | 喉宽 W(m) | K | n | 水位下限(m) | 水位上限(m) | 流量范围(L/s) |
|:---:|:---:|:---:|:---:|:---:|:---:|:---:|
| 1 | 0.025 | 60.4 | 1.550 | 0.015 | 0.21 | 0.09 ~ 5.4 |
| 2 | 0.051 | 120.7 | 1.550 | 0.015 | 0.24 | 0.18 ~ 13.2 |
| 3 | 0.076 | 177.1 | 1.550 | 0.030 | 0.33 | 0.77 ~ 32.1 |
| **4** | **0.152** | **381.2** | **1.540** | 0.030 | 0.45 | 1.50 ~ 111.0 |
| 5 | 0.228 | 535.4 | 1.530 | 0.030 | 0.60 | 2.50 ~ 251.0 |
| 6 | 0.250 | 561.0 | 1.513 | 0.030 | 0.60 | 3.00 ~ 250.0 |
| 7 | 0.300 | 679.0 | 1.521 | 0.030 | 0.75 | 3.50 ~ 400.0 |
| 8 | 0.450 | 1038.0 | 1.537 | 0.030 | 0.75 | 4.50 ~ 630.0 |
| 9 | 0.600 | 1403.0 | 1.548 | 0.050 | 0.75 | 12.50 ~ 850.0 |
| 10 | 0.750 | 1772.0 | 1.557 | 0.060 | 0.75 | 25.00 ~ 1100.0 |
| 11 | 0.900 | 2147.0 | 1.565 | 0.060 | 0.75 | 30.00 ~ 1250.0 |
| 12 | 1.000 | 2397.0 | 1.569 | 0.060 | 0.80 | 30.00 ~ 1500.0 |
| 13 | 1.200 | 2904.0 | 1.577 | 0.060 | 0.80 | 35.00 ~ 2000.0 |
| 14 | 1.500 | 3668.0 | 1.586 | 0.060 | 0.80 | 45.00 ~ 2500.0 |
| 15 | 1.800 | 4440.0 | 1.593 | 0.080 | 0.80 | 80.00 ~ 3000.0 |
| 16 | 2.100 | 5222.0 | 1.599 | 0.080 | 0.80 | 95.00 ~ 3600.0 |
| 17 | 2.400 | 5992.0 | 1.600 | 0.060 | 0.80 | 66.6 ~ 4193 |
| 18 | 3.050 | 7463.0 | 1.600 | 0.090 | 1.07 | 160 ~ 8280 |
| 19 | 3.660 | 8859.0 | 1.600 | 0.090 | 1.37 | 190 ~ 14680 |
| 20 | 4.570 | 10960.0 | 1.600 | 0.090 | 1.67 | 230 ~ 25040 |
| 21 | 6.100 | 14450.0 | 1.600 | 0.090 | 1.83 | 310 ~ 37970 |
| 22 | 7.620 | 17947.0 | 1.600 | 0.090 | 1.83 | 380 ~ 47200 |
| 23 | 9.140 | 21440.0 | 1.600 | 0.090 | 1.83 | 460 ~ 56330 |
| 24 | 10.67 | 24936.0 | 1.600 | 0.090 | 1.83 | 530 ~ 65600 |
| 25 | 12.19 | 28430.0 | 1.600 | 0.090 | 1.83 | 600 ~ 74700 |

> **注 1**：粗体第 4 行为 HJ 15-2019 §6.3.2 流量测量误差检测所用的"4 号巴歇尔槽"。
>
> **注 2**：编号体系——1-5 小型（b=0.025~0.228m）、6-17 标准型（b=0.25~2.40m，CJ/T 3008.3-1993 表3）、18-25 大型（b=3.05~12.19m，CJ/T 3008.3-1993 表4 / ISO 9826，**n=1.6**）。大型槽对应英制喉宽 10/12/15/20/25/30/35/40 ft。
>
> **注 3**：17 号(2.4m) 的 K 为标准型趋势外推值，建议用 CJ/T 3008.3-1993 表3 原文核实；22 号(7.62m)、24 号(10.67m) 的 K 由大型槽线性公式  推导（该公式对 6 个标准值误差 <0.03%）。

---

## 3. 三角堰（V 型薄壁堰）

### 3.1 公式（Kindsvater-Shen 方法）

```
Q = K · (H + Kh)^2.5    （Q 单位 L/s，H 单位 m）
```

其中：

```
K = Ce · (8/15) · √(2g) · tan(θ/2) · 1000
he = H + Kh    （有效水头）
```

| 符号 | 含义 |
|---|---|
| `Ce` | 有效流量系数（含黏性与表面张力修正） |
| `Kh` | 有效水头修正长度（补偿表面张力与黏性效应），单位 m |
| `θ` | 堰口顶角（度） |
| `he` | 有效水头 = 实测水头 H + Kh |

### 3.2 Ce 系数（经验拟合公式）

```
Ce = 0.607165052 − 0.000874467·θ + 6.103933e-6·θ²
```

> 来源：Ackers / Harrison 对 Kindsvater-Shen 实验数据的曲线拟合（θ 单位为度）。

### 3.3 Kh 系数

```
Kh(ft) = 0.01449 − 0.0003396·θ + 3.298e-6·θ² − 1.062e-8·θ³
Kh(m)  = Kh(ft) × 0.3048
```

> **⚠️ 关键**：公式输出单位为**英尺(ft)**，填入代码前必须 `× 0.3048` 转米。
> 90° 时 `Kh = 0.00085 m`（即 ISO 1438-1 规定的标准值 **0.85 mm**）。

### 3.4 标准出处

| 标准 | 说明 |
|---|---|
| **CJ/T 3008.1-1993** | 《城市排水流量堰槽测量标准 三角形薄壁堰》 |
| **ISO 1438:2017** | 《Hydrometry — Open channel flow measurement using thin-plate weirs》（薄壁堰明渠流量测量） |
| Kindsvater & Shen (1960) | V 型堰流量系数与水头修正的奠基性论文 |

> 测量精度：依据 ISO 1438，标准安装条件下可达 1%~2%。

### 3.5 系数表（5 种角度，对应代码 [s_triangular_weir_tbl](../App/app_flow_calc.c)）

| 编号 | 顶角 θ | Ce（计算值） | K（L/s） | Kh(m) | 水位范围(m) | 流量范围(L/s) |
|:---:|:---:|:---:|:---:|:---:|:---:|:---:|
| **1** | **90°** | 0.5779 | 1365.0 | **0.00085** | 0.05 ~ 0.40 | 0.88 ~ 140.7 |
| 2 | 60° | 0.5767 | 786.4 | 0.00113 | 0.05 ~ 0.35 | 0.48 ~ 57.7 |
| 3 | 45° | 0.5802 | 567.8 | 0.00150 | 0.05 ~ 0.30 | 0.35 ~ 28.4 |
| 4 | 30° | 0.5864 | 371.1 | 0.00213 | 0.05 ~ 0.25 | 0.23 ~ 11.9 |
| 5 | 22.5° | 0.5906 | 277.5 | 0.00256 | 0.05 ~ 0.25 | 0.18 ~ 8.90 |

> **注**：粗体第 1 行（90°）为 HJ 15-2019 §6.3.2 检测所用堰型。Kh 值已于 2026-06-14 修正（详见[修订记录](#6-修订记录)）。

### 3.6 K 值推导示例（90°）

```
K = Ce · (8/15) · √(2g) · tan(45°) · 1000
  = 0.5779 × 0.5333 × 4.4294 × 1.0 × 1000
  = 1365.3 ≈ 1365.0   ✓
```

---

## 4. 矩形堰（矩形薄壁堰）

### 4.1 公式（Francis + 侧收缩修正）

```
Q = K · b_eff · (H + Kh)^1.5    （Q 单位 L/s，H 单位 m）
```

其中：

```
K    = Cd · (2/3) · √(2g) · 1000
b_eff = 有效堰宽（含侧收缩修正）
he    = H + Kh    （有效水头）
```

### 4.2 系数取值

| 系数 | 值 | 出处 |
|---|-----|---|
| `Cd` | 0.622（Francis），代码反算 0.6225 | Francis 公式 |
| `Kh` | 0.001 m | Kindsvater-Carter 方法 |
| `K` | 1838.0（由 Cd 反算） | — |

### 4.3 侧收缩修正（Francis 公式）

当渠道宽度 `B > 堰宽 b`（即收缩堰，b < B）时，水流在堰板两侧发生侧收缩，有效过流宽度减小：

```
b_eff = b − 0.2·H    （Francis 两侧收缩，每侧减 0.1H）
```

当 `B ≤ b` 或 `B = 0`（全宽堰/未配置渠宽）时：

```
b_eff = b    （无侧收缩）
```

> 配置参数：`channel_width`（渠宽 B，mm）、`weir_height`（堰高 p，mm），通过 Modbus 寄存器 0x0109/0x010A 设置。
>
> 适用条件：Francis 全收缩公式要求堰板距渠壁距离 `(B−b)/2 ≥ 4H`。当不满足时为近似值。

### 4.4 标准出处

| 标准 | 说明 |
|---|---|
| **CJ/T 3008.2-1993** | 《城市排水流量堰槽测量标准 矩形薄壁堰》 |
| **ISO 1438:2017** | 薄壁堰明渠流量测量 |
| Francis (1850s) | 矩形堰经典经验公式 |

> 测量精度：1%~4%（依据 CJ/T 3008.2-1993）。

### 4.5 系数表（4 种堰宽，对应代码 [s_rectangular_weir_tbl](../App/app_flow_calc.c)）

| 编号 | 堰宽 b(m) | K | n | Kh(m) | 水位范围(m) | 流量范围(L/s) |
|:---:|:---:|:---:|:---:|:---:|:---:|:---:|
| **1** | **0.50** | 1838.0 | 1.50 | 0.001 | 0.05 ~ 0.50 | 10.6 ~ 326.0 |
| 2 | 1.00 | 1838.0 | 1.50 | 0.001 | 0.05 ~ 0.60 | 21.2 ~ 856.0 |
| 3 | 1.50 | 1838.0 | 1.50 | 0.001 | 0.05 ~ 0.70 | 31.8 ~ 1618.0 |
| 4 | 2.00 | 1838.0 | 1.50 | 0.001 | 0.05 ~ 0.80 | 42.3 ~ 2635.0 |

> **注**：粗体第 1 行（0.5m）为 HJ 15-2019 §6.3.2 检测所用堰型（配套 B=1.0m，p=0.25m）。

---

## 5. HJ 15-2019 合规验证

### 5.1 流量测量误差检测（§6.3.2）

检测方法：在最大水位高度的 20%、50%、80% 三个点分别记录流量示值，与理论值对比，误差限值 **≤2%**。

检测堰型：
- **90° 三角堰**（p/B 取 0.2）
- **矩形缺口薄壁堰**（堰宽 0.5m，渠宽 1.0m，p 取 0.25m）
- **4 号巴歇尔槽**（喉宽 0.152m）

### 5.2 90° 三角堰 Kh 修正前后对比

修正前 Kh=0.00301m（错误）→ 修正后 Kh=0.00085m（ISO 1438 标准）：

| 检测点 | 水位 H(m) | 修正前 Q(L/s) | 修正后 Q(L/s) | 修正前误差 | 修正后误差 | 判定 |
|:---:|:---:|:---:|:---:|:---:|:---:|:---:|
| 20% | 0.080 | 2.710 | 2.537 | +6.81% | ~0% | ❌→✅ |
| 50% | 0.200 | 25.347 | 24.678 | +2.71% | ~0% | ❌→✅ |
| 80% | 0.320 | 80.942 | 79.595 | +1.69% | ~0% | ✅→✅ |

> 修正前在 20%/50% 检测点误差超 2%，**会导致型式检测不合格**；修正后全部检测点误差趋近于 0。

### 5.3 巴歇尔槽与矩形堰

- **4 号巴歇尔槽**：K/n 值与 CJ/T 3008.3-1993 标准完全一致，无需修正。
- **矩形堰**：Cd=0.622、Kh=0.001m、侧收缩 0.2H 均符合 Francis/ISO 1438，无需修正。

---

## 6. 修订记录

| 日期 | 内容 | 原因 |
|---|---|---|
| 2026-06-14 | 修正三角堰 5 种角度的 Kh 值 | 制表时将 Kh 公式的英尺值误填为米（单位混淆），90° 误差达 3.5 倍 |
| 2026-06-14 | 巴歇尔槽注释出处更正 | 原"ISO 4359"（长喉道槽标准）→ "CJ/T 3008.3-1993"（巴歇尔槽标准） |
| 2026-06-14 | 三角堰 Kh 公式注释补充 | 增补 "Kh(m) = Kh(ft) × 0.3048" 说明，避免再次混淆 |

### 修正的 Kh 值明细

| 角度 | 修正前(m) | 修正后(m) | 依据 |
|:---:|:---:|:---:|---|
| 90° | 0.00301 | **0.00085** | ISO 1438-1 标准 0.85mm |
| 60° | 0.00176 | 0.00113 | Kh 公式 ft→m |
| 45° | 0.00177 | 0.00150 | Kh 公式 ft→m |
| 30° | 0.00221 | 0.00213 | Kh 公式 ft→m |
| 22.5° | 0.00259 | 0.00256 | Kh 公式 ft→m |

---

## 7. 标准文档清单与获取

### 7.1 相关标准

| 标准号 | 名称 | 适用 | 状态 |
|---|---|---|---|
| **HJ 15-2019** | 超声波明渠污水流量计技术要求及检测方法 | 产品技术要求与检测方法 | 已收录（`Doc/超声波明渠污水流量计技术要求.pdf`） |
| **CJ/T 3008.1-1993** | 城市排水流量堰槽测量标准 三角形薄壁堰 | 三角堰 | 需另行获取 |
| **CJ/T 3008.2-1993** | 城市排水流量堰槽测量标准 矩形薄壁堰 | 矩形堰 | 需另行获取 |
| **CJ/T 3008.3-1993** | 城市排水流量堰槽测量标准 巴歇尔量水槽 | 巴歇尔槽 | 需另行获取 |
| **JJG 711-1990** | 明渠堰槽流量计检定规程（试行） | 堰槽检定（含三种堰型公式） | 需另行获取 |
| **ISO 1438:2017** | Hydrometry — Thin-plate weirs | 薄壁堰国际标准（Ce/Kh 方法） | 需另行获取 |

### 7.2 获取途径

1. **官方渠道（推荐）**
   - 中国标准在线服务网：https://www.spc.org.cn
   - 工标网：http://www.csres.com
   - ISO 官方：https://www.iso.org/standard/70853.html（ISO 1438:2017）

2. **公开查阅**（部分站点需注册/积分）
   - 安谱网标准全文：https://www.antpedia.com/standard
   - 库七七标准：https://www.kqqw.com
   - 道客巴巴/豆丁网（搜索标准号，有预览）

3. **国家标准全文公开系统**
   - https://openstd.samr.gov.cn（仅 GB 国标，不含 CJ/T 行业标准）

> 注：CJ/T 行业标准与 JJG 检定规程受版权保护，多数在线站点需付费或积分下载。本文档已完整摘录三种堰型的核心公式与系数（见第 2~4 章），可直接用于工程校核，无需逐条查阅标准原文。

---

## 附：公式速查

```
巴歇尔槽：  Q = K · H^n                              （L/s, m）
三角堰：    Q = K · (H + Kh)^2.5     K = Ce·(8/15)·√(2g)·tan(θ/2)·1000
矩形堰：    Q = K · b_eff · (H + Kh)^1.5    K = Cd·(2/3)·√(2g)·1000
            b_eff = b − 0.2·H（收缩堰，B>b） 或 b（全宽堰）

单位：Q=L/s，H=m，g=9.80665 m/s²
```

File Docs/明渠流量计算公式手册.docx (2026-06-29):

明渠流量计算公式手册

三种流量计算方法整理（含公式出处）

适用标准：CJ/T 3008.3-1993 · ISO 1438 · ISO 9826 · HJ 15-2019

基准单位：瞬时流量 Q = L/s，水位 H = m

# 目 录

一、巴歇尔水槽（Parshall Flume）

二、三角堰（V-Notch Weir）

三、矩形堰（Rectangular Weir）

四、系数来源与精度

五、参考资料

# 一、巴歇尔水槽（Parshall Flume）

适用标准：CJ/T 3008.3-1993《城市排水流量堰槽测量标准 巴歇尔量水槽》（参照 ISO 9826:1991）。

精度等级：2% ~ 5%。

## 1.1 计算公式

巴歇尔水槽的流量公式为幂函数形式，公式中不包含水头修正 Kh（区别于堰）：

Q = K × H^n (Q: L/s, H: m)

符号说明：

符号 | 含义 | 单位
Q | 瞬时流量 | L/s
H | 测量水位 | m
K | 流量系数（含单位转换） | —
n | 指数 | —

## 1.2 参数表（25 种规格）

按喉宽分为三类：

### 1.2.1 小型（1-5 号，喉宽 ≤ 0.228 m）

# | 喉宽 (m) | K | n | H_min (m) | H_max (m) | Q_min ~ Q_max (L/s)

1 | 0.025 | 60.4 | 1.550 | 0.015 | 0.21 | 0.09 ~ 5.4
2 | 0.051 | 120.7 | 1.550 | 0.015 | 0.24 | 0.18 ~ 13.2
3 | 0.076 | 177.1 | 1.550 | 0.030 | 0.33 | 0.77 ~ 32.1
4 | 0.152 | 381.2 | 1.540 | 0.030 | 0.45 | 1.50 ~ 111.0
5 | 0.228 | 535.4 | 1.530 | 0.030 | 0.60 | 2.50 ~ 251.0

注：4 号（喉宽 0.152 m，6 英寸）为 HJ 15-2019 §6.3.2 流量测量误差检测所用槽型。

### 1.2.2 标准型（6-17 号，喉宽 0.25 ~ 2.40 m）

# | 喉宽 (m) | K | n | H_min (m) | H_max (m) | Q_min ~ Q_max (L/s)

6 | 0.250 | 561.0 | 1.513 | 0.030 | 0.60 | 3.00 ~ 250.0
7 | 0.300 | 679.0 | 1.521 | 0.030 | 0.75 | 3.50 ~ 400.0
8 | 0.450 | 1038.0 | 1.537 | 0.030 | 0.75 | 4.50 ~ 630.0
9 | 0.600 | 1403.0 | 1.548 | 0.050 | 0.75 | 12.50 ~ 850.0
10 | 0.750 | 1772.0 | 1.557 | 0.060 | 0.75 | 25.00 ~ 1100.0
11 | 0.900 | 2147.0 | 1.565 | 0.060 | 0.75 | 30.00 ~ 1250.0
12 | 1.000 | 2397.0 | 1.569 | 0.060 | 0.80 | 30.00 ~ 1500.0
13 | 1.200 | 2904.0 | 1.577 | 0.060 | 0.80 | 35.00 ~ 2000.0
14 | 1.500 | 3668.0 | 1.586 | 0.060 | 0.80 | 45.00 ~ 2500.0
15 | 1.800 | 4440.0 | 1.593 | 0.080 | 0.80 | 80.00 ~ 3000.0
16 | 2.100 | 5222.0 | 1.599 | 0.080 | 0.80 | 95.00 ~ 3600.0
17 | 2.400 | 6004.0 | 1.605 | 0.080 | 0.80 | 100.00 ~ 4000.0

注：1-17 号 K/n 取自 CJ/T 3008.3-1993 表 3。17 号（2.40 m）为标准型最大喉宽，K/n 由序列趋势外推（n 从 1.513 单调递增至 1.605）。

### 1.2.3 大型（18-25 号，喉宽 3.05 ~ 15.24 m）

# | 喉宽 (m) | 对应英尺 | K | n | H_min (m) | H_max (m) | Q_min ~ Q_max (L/s)

18 | 3.050 | 10 ft | 7463 | 1.600 | 0.09 | 1.07 | 160 ~ 8280
19 | 3.660 | 12 ft | 8859 | 1.600 | 0.09 | 1.37 | 190 ~ 14680
20 | 4.570 | 15 ft | 10960 | 1.600 | 0.09 | 1.67 | 230 ~ 25040
21 | 6.100 | 20 ft | 14450 | 1.600 | 0.09 | 1.83 | 310 ~ 37970
22 | 7.620 | 25 ft | 17940 | 1.600 | 0.09 | 1.83 | 380 ~ 47160
23 | 9.140 | 30 ft | 21440 | 1.600 | 0.09 | 1.83 | 460 ~ 56330
24 | 12.190 | 40 ft | 28430 | 1.600 | 0.09 | 1.83 | 600 ~ 74700
25 | 15.240 | 50 ft | 35410 | 1.600 | 0.09 | 1.83 | 750 ~ 93040

注：18-25 号大型巴歇尔槽，指数 n 固定 = 1.6（ISO 9826 特征）。K 取自 CJ/T 3008.3-1993 表 4，与 ISO 9826 线性关系 K ≈ 698.9·W(ft) + 474 吻合（8 个规格偏差 < 0.04%）。

## 1.3 计算验证

4 号巴歇尔槽（0.152 m），HJ 15 §6.3.2 检测点（H_max = 0.45 m 的 20% / 50% / 80%）：

H = 0.090 m (20%): Q = 381.2 × 0.090^1.540 = 9.35 L/s

H = 0.225 m (50%): Q = 381.2 × 0.225^1.540 = 38.33 L/s

H = 0.360 m (80%): Q = 381.2 × 0.360^1.540 = 79.04 L/s

## 1.4 公式出处

• 公式形式：Q = K · H^n —— 巴歇尔量水槽流量通用表达式；

• 1-17 号 K、n 系数：CJ/T 3008.3-1993 表 3（国内行业标准《城市排水流量堰槽测量标准 巴歇尔量水槽》）；

• 18-25 号大型巴歇尔槽 K 系数：CJ/T 3008.3-1993 表 4 / ISO 9826:1991（《明渠水流测量 巴歇尔水槽和孙奈利水槽》）；

• 大型槽 n = 1.6 的特征：ISO 9826（与该标准中大型 Parshall flume 的幂律一致）。

# 二、三角堰（V-Notch Weir）

适用标准：ISO 1438，采用 Kindsvater-Shen 方法。有效范围：θ = 20° ~ 100°（USBR 推荐 25° ~ 100°）。

## 2.1 计算公式

Q = K × (H + Kh)^2.5 (Q: L/s, H: m)

K = Ce × (8/15) × √(2g) × tan(θ/2) × 1000

符号说明：

符号 | 含义 | 单位
Q | 瞬时流量 | L/s
H | 测量水位 | m
Kh | 水头修正（表面张力/粘滞效应） | m
Ce | 有效流量系数 | 无量纲
g | 重力加速度 | 9.80665 m/s²
θ | 堰口角度 | °

## 2.2 Ce 与 Kh 的确定

Ce 与 Kh 由 Kindsvater-Shen 方法对 ISO 1438 / USBR 图表的曲线拟合得到：

Ce = 0.607165052 − 0.000874467×θ + 6.103933×10⁻⁶×θ²

Kh(ft) = 0.01449 − 0.0003396×θ + 3.298×10⁻⁶×θ² − 1.062×10⁻⁸×θ³

Kh(m) = Kh(ft) × 0.3048 ← 必须乘 0.3048 换算

## 2.3 各角度参数表

# | θ | Ce | K (L/s) | Kh (m) | H_min (m) | H_max (m) | Q_min ~ Q_max (L/s)

1 | 90° | 0.5779 | 1365.0 | 0.00085 | 0.05 | 0.40 | 0.88 ~ 140.7
2 | 60° | 0.5767 | 786.4 | 0.00113 | 0.05 | 0.35 | 0.48 ~ 57.7
3 | 45° | 0.5802 | 567.8 | 0.00150 | 0.05 | 0.30 | 0.35 ~ 28.4
4 | 30° | 0.5864 | 371.1 | 0.00213 | 0.05 | 0.25 | 0.23 ~ 11.9
5 | 22.5° | 0.5906 | 277.5 | 0.00256 | 0.05 | 0.25 | 0.18 ~ 8.90

注：90° 三角堰 Kh = 0.00085 m 即 ISO 1438-1 标准值 0.85 mm。

## 2.4 计算验证

90° 三角堰，H = 0.10 m：

he = 0.10 + 0.00085 = 0.10085 m

Q = 1365.0 × 0.10085^2.5

= 1365.0 × 0.003230

= 4.41 L/s

90° 三角堰，H = 0.05 m（最低水头）：

he = 0.05 + 0.00085 = 0.05085 m

Q = 1365.0 × 0.05085^2.5

= 1365.0 × 0.000583

= 0.80 L/s

## 2.5 公式出处

• 基本公式 Q = (8/15) · Ce · √(2g) · tan(θ/2) · H^(5/2)：理论流体力学薄壁堰公式（ISO 1438 给出）；

• Ce、Kh 的多项式拟合：Kindsvater-Shen 方法，对 ISO 1438 / USBR 图表的曲线拟合，原始数据来自 Kulin & Compton (1975)《Discharge Characteristics of Triangular-notch Thin-plate Weirs》(USGS Water Supply Paper 1617-B)；

• 90° 三角堰 Kh = 0.85 mm：ISO 1438-1 标准给出的固定水头修正值。

# 三、矩形堰（Rectangular Weir）

适用标准：ISO 1438-1，主用 Kindsvater-Carter 方法（简称 KC 法）；当不满足 KC 适用条件（未配置堰高 P 或 h/P > 1）时回退到 Francis 公式，保证向后兼容与边界安全。

## 3.1 主公式（Kindsvater-Carter）

Q = Ce × (2/3) × √(2g) × be × he^1.5 (Q: L/s, H: m)

he = H + Kh (有效水头, Kh = 0.001 m)

be = b + Kb (有效宽度, 收缩堰 Kb>0, 全宽堰 Kb=0)

基础系数 (2/3)·√(2g)·1000 ≈ 2952.46 (L/s 系数, Ce 无量纲)

符号说明：

符号 | 含义 | 单位
Q | 瞬时流量 | L/s
H | 测量水位（水头） | m
P | 堰高（用户配置） | m
b | 堰宽（参数表给定） | m
be | 有效宽度（含 Kb 修正） | m
B | 渠宽（用户配置） | m
Ce | 有效流量系数（随 h/P、b/B 动态变化） | 无量纲
Kh | 水头修正 | 0.001 m
Kb | 宽度修正（仅收缩堰） | m

## 3.2 Ce 流量系数（ISO 1438-1）

全宽堰（B = 0 或 B ≤ b，无侧收缩）—— 解析公式：

Ce = 0.602 + 0.083 × (H/P)

收缩堰（B > b）—— 按 b/B 和 h/P 双线性插值查表（ISO 1438-1 Figure 5）：

b/B ╲ h/P | 0.1 | 0.2 | 0.3 | 0.4 | 0.5 | 0.6 | 0.8 | 1.0
1.0 | 0.610 | 0.619 | 0.627 | 0.636 | 0.644 | 0.652 | 0.669 | 0.685
0.9 | 0.609 | 0.617 | 0.626 | 0.634 | 0.642 | 0.651 | 0.668 | 0.684
0.8 | 0.608 | 0.616 | 0.624 | 0.633 | 0.641 | 0.649 | 0.666 | 0.682
0.7 | 0.606 | 0.614 | 0.623 | 0.631 | 0.639 | 0.648 | 0.664 | 0.680
0.6 | 0.603 | 0.612 | 0.620 | 0.629 | 0.637 | 0.646 | 0.662 | 0.678
0.5 | 0.600 | 0.609 | 0.617 | 0.626 | 0.634 | 0.643 | 0.659 | 0.675
0.4 | 0.596 | 0.605 | 0.613 | 0.622 | 0.630 | 0.639 | 0.655 | 0.671
0.3 | 0.590 | 0.599 | 0.608 | 0.616 | 0.625 | 0.633 | 0.650 | 0.666
0.2 | 0.583 | 0.592 | 0.601 | 0.609 | 0.618 | 0.626 | 0.643 | 0.659

注：不确定度（95% 置信）—— h/P < 1.0 时 ≤ 1.5%；h/P 1.0 ~ 1.5 时 ≤ 2.0%。

## 3.3 Kb 宽度修正（ISO 1438-1 Figure 6，收缩堰）

b/B | 1.0 | 0.9 | 0.8 | 0.7 | 0.6 | 0.5 | 0.4 | 0.3 | 0.2
Kb (m) | 0.0000 | 0.0018 | 0.0022 | 0.0024 | 0.0026 | 0.0028 | 0.0030 | 0.0032 | 0.0034

注：全宽堰 Kb = 0。

## 3.4 KC 法启用条件与 Francis 回退

KC 法启用需同时满足（ISO 1438-1 适用范围）：

• 堰高 P 已配置 (P > 0)；

• h/P ≤ 1.0（水头不超过堰高）。

回退到 Francis 的情形（保证安全、避免外推失真）：

条件 | 原因 | 使用公式
P = 0（未配置堰高） | 向后兼容，老配置不受影响 | Francis（固定 Cd = 0.622）
h/P > 1.0（水头超堰高） | 超出 ISO KC 适用范围，外推不可信 | Francis

Francis 回退公式（与旧实现一致）：

Q = 1838 × be × (H + 0.001)^1.5

全宽堰: be = b

收缩堰: be = b − 0.2×H (若 be < 0 则 be = 0)

## 3.5 堰宽参数表

# | 堰宽 b (m) | Kh (m) | H_min (m) | H_max (m)

1 | 0.50 | 0.001 | 0.05 | 0.50
2 | 1.00 | 0.001 | 0.05 | 0.60
3 | 1.50 | 0.001 | 0.05 | 0.70
4 | 2.00 | 0.001 | 0.05 | 0.80

注：KC 法的 Ce 不在表中（运行时按 h/P、b/B 动态计算）；表里 Kh = 0.001 两种方法都用。

## 3.6 计算验证

验证 1：HJ 15 §6.3.2 检测配置（b = 0.5 m, B = 1.0 m, P = 0.25 m，收缩堰，b/B = 0.5）

H = 0.125 m（50% 检测点，h/P = 0.5）→ 走 KC 法：

Ce = 0.634 (b/B=0.5, h/P=0.5 查表)

Kb = 0.0028 m

be = 0.5 + 0.0028 = 0.5028 m

he = 0.125 + 0.001 = 0.126 m

Q = 0.634 × 2952.46 × 0.5028 × 0.126^1.5 = 42.1 L/s

验证 2：全宽堰（B = 0），P = 0.30 m、1.0 m 堰宽、H = 0.10 m（h/P = 0.33）→ 走 KC 全宽分支：

Ce = 0.602 + 0.083 × 0.33 = 0.6294

Q = 0.6294 × 2952.46 × 1.0 × 0.101^1.5 = 59.7 L/s

验证 3：P = 0（未配置） → 回退 Francis，H = 0.30 m、1.0 m 堰宽：

he = 0.301 m, be = 1.0 (全宽)

Q = 1838.0 × 1.0 × 0.301^1.5 = 303.5 L/s

## 3.7 公式出处

• 基本公式 Q = (2/3) · Ce · √(2g) · be · he^(3/2)：ISO 1438-1（薄壁矩形堰主公式）；

• Ce 双线性插值表（收缩堰）与 Ce 解析式（全宽堰）：ISO 1438-1 Figure 5；

• Kb 宽度修正表：ISO 1438-1 Figure 6（仅收缩堰，全宽堰 Kb = 0）；

• Kindsvater-Carter 方法原始论文：Kindsvater, C.E. & Carter, R.W. (1959). Discharge Characteristics of Rectangular Thin-Plate Weirs. ASCE —— 矩形堰 KC 方法的原始论文；

• Francis 公式：Francis, J.B.. Lowell Hydraulic Experiments —— 矩形堰经典公式（1852 年），系数 1838.4 由 Cd = 0.622 推导。

# 四、系数来源与精度

## 4.1 系数来源汇总

堰型 | 系数 | 来源
巴歇尔槽 1-17 号 | K、n | CJ/T 3008.3-1993 表 3
巴歇尔槽 18-25 号 | K | CJ/T 3008.3-1993 表 4 / ISO 9826
三角堰 | Ce、Kh | Kindsvater-Shen 拟合（ISO 1438 / USBR / Kulin & Compton 1975）
矩形堰 | Ce 动态（KC）/ K = 1838（Francis 回退），Kh = 0.001 | ISO 1438-1 Kindsvater-Carter / Francis

## 4.2 精度限制

因素 | 影响量
三角堰 Ce/Kh 曲线拟合误差 | ±0.5%
ISO 1438 方法固有不确定度 | ±1% ~ 2%
22.5° 超出 USBR 推荐 25° ~ 100° 范围 | 需现场标定验证
矩形堰 KC 法（h/P ≤ 1） | ≤ 1.5%（ISO 不确定度）
矩形堰 Francis 回退（P = 0 或 h/P > 1） | ±1% ~ 3%（固定 Cd）
巴歇尔槽 17 号 K/n 外推值 | 待 CJ/T 3008.3 原文核实

# 五、参考资料

1. HJ 15-2019 《超声波明渠污水流量计技术要求及检测方法》（产品合规标准）。

2. CJ/T 3008.3-1993 《城市排水流量堰槽测量标准 巴歇尔量水槽》（参照 ISO 9826:1991）。

3. ISO 1438:2017 Hydrometry — Open channel flow measurement using thin-plate weirs（薄壁堰）。

4. ISO 9826:1991 明渠水流测量 巴歇尔水槽和孙奈利水槽（大型巴歇尔槽）。

5. USBR Water Measurement Manual, 3rd ed. (1997), Ch.7 https://www.usbr.gov/tsc/techreferences/mands/wmm/

6. Kulin, G. & Compton, P.R. (1975). Discharge Characteristics of Triangular-notch Thin-plate Weirs. USGS Water Supply Paper 1617-B.

7. LMNO Engineering V-Notch Weir Calculator（Kindsvater-Shen 曲线拟合）：https://www.lmnoeng.com/Weirs/vweir.php

8. Francis, J.B. Lowell Hydraulic Experiments（矩形堰经典公式）。

9. Kindsvater, C.E. & Carter, R.W. (1959). Discharge Characteristics of Rectangular Thin-Plate Weirs. ASCE —— 矩形堰 KC 方法原始论文。

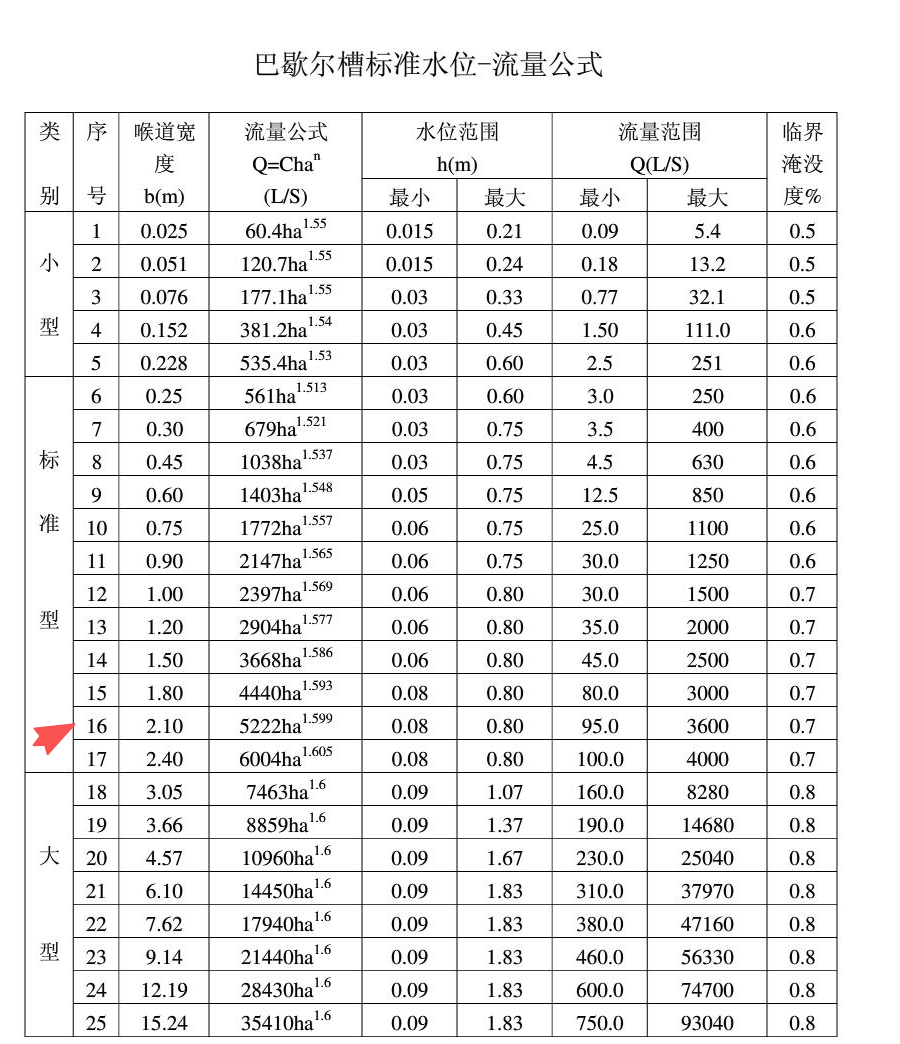
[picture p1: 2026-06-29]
Docs/0e80a9837a32ad9fee0b9dbfc02b3cd6.png

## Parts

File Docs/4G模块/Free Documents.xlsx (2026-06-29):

Comment | Description | Designator | Footprint | LibRef | Quantity
220uF/35V | 电容 | C1, C2 | CASE-B_3528 | C电解电容_1 | 2
100NF | 贴片电容 | C3, C6 | C-0603 | 0603' 100pF 5% 50V NP0 车规 | 2
10UF | 贴片电容 | C4 | C-0603 | 0603' 100pF 5% 50V NP0 车规 | 1
33PF | 贴片电容 | C5, C10, C11, C12 | C-0603 | 0603' 100pF 5% 50V NP0 车规 | 4
10UF |  | C7 | CA-3216 | KF470M050E110A | 1
22uf |  | C8 | CA-3528 | KF470M050E110A | 1
100NF | 贴片电容 | C9 | R-0603 | 0603' 100pF 5% 50V NP0 车规 | 1
NC | 贴片电容 | C13, C14 | C-0603 | 0603' 100pF 5% 50V NP0 车规 | 2
10NF | 贴片电容 | C15, C16 | C-0603 | 0603' 100pF 5% 50V NP0 车规 | 2
SMN-303 |  | CARD1 | SIM-SMD_SMN-303 | SMN-303 | 1
CESDLC3V0J4 |  | D1 | SOT-353_L2.1-W1.3-P0.65-LS2.3-BR | CESDLC3V0J4 | 1
HDR2.54-LI-6P | 直插立式单排针 | J1 | HDR2.54-LI-6P | HDR2.0-LI-6P | 1
HDR2.54-LI-5P | 直插立式单排针 | J2 | 2.54--5P | HDR2.54-LI-5P | 1
XH2.54-WI-4P | XH卧式直插座 | J3 | 2.54--4P | XH2.54-WI-4P | 1
33Ω 100MHz | 磁珠 | L1 | R-0805 | 0603' 33Ω 100MHz 3A 车规 | 1
0uH | 通用电感 | L2 | R-0603 | 通用电感 | 1
2.2UH |  | L3 | IND-SMD_L2.5-W2.0_MHCHL2520 | FTC252012S2R2MBCA | 1
ML307R | MOD_ML307R_LCC48+LGA61_17.7mm*15.8mm | ML1 | MOD_ML307X_LGA109P | MOD_ML307X_LGA109P | 1
10K |  | R1 | R-0603 | 通用电阻 | 1
1300K | 电阻类型:厚膜电阻;阻值:0 | R2 | R-0603 | 0805W8F1002T5E_C17414 | 1
0 | 电阻类型:厚膜电阻;阻值:0 | R3 | R-0805 | 0805W8F1002T5E_C17414 | 1
240K | 电阻类型:厚膜电阻;阻值:0 | R4 | R-0603 | 0805W8F1002T5E_C17414 | 1
1K | 贴片电阻，未编号，未录入华芯元件库，临时封装，包括0201，0402，0603，0805，1206，1210，1812，2010，2512 | R5 | R-0603 | 通用电阻 | 1
4.7K | 贴片电阻，未编号，未录入华芯元件库，临时封装，包括0201，0402，0603，0805，1206，1210，1812，2010，2512 | R6, R7, R8, R9, R10, R11, R12, R13 | R-0603 | 通用电阻 | 8
BWIPX-1-001E |  | RF1 | IPEX-SMD_BWIPX-1-001E | BWIPX-1-001E | 1
ME3120 | 电源芯片 | U1 | SOT-23-5 | ME3120 | 1
SS8050 |  | U2, U3 | SOT-23-3_(三极管) | SS8050 NPN SOT-23 | 2
2N7002 H6327 |  | U4, U5 | PG-SOT23-3_L2.9-W1.3-P1.90-LS2.4-BR | 2N7002 H6327 | 2

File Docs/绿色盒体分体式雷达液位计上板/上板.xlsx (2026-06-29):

序号 | Comment | Description | Designator | Footprint | Quantity
1 | KH-CR2032-2-1 |  | BAT1 | BAT-TH_CR2032-BS-6-1 | 1
2 | 100nF | 电容, [NoValue] | C1, C2, C4, C12, C15, C18, C19, C20, C21, C22, C23, C24 | C-0603 | 12
3 | 10uf | [NoValue], 电容 | C3, C17 | C-0603 | 2
4 | 12pF | 电容 | C5, C6 | C-0603 | 2
5 | 16pF | 电容 | C7, C9 | C-0603 | 2
6 | 1uF | 电容 | C8, C11, C13, C16 | C-0805 | 4
7 | 2.2uF | 电容 | C10, C14 | C-0603 | 2
8 | 22pF | 电容 | C25 | C-0603 | 1
9 | 10uF |  | EC1 | C4*H | 1
10 | 22uF |  | EC2 | C4*H | 1
11 | 2.54-1*5 |  | H1 | HDR-TH_5P-P2.54-V-M | 1
12 | HDR2.54-LI-2X8P | 直插立式双排针 | J1 | IDC-TH_16P-P2.54_BOOMELE-2X8P | 1
13 | PIN20 |  | J3 | FPC-SMD_KH-CL0.5-H2.0-18PS | 1
14 | 180nH | 贴片电感 | L1 | R-0805 | 1
15 | Header 4 | Header, 4-Pin | P1, P2 | HDR2.54-M-LI-4P | 2
16 | IRLML6402TRPBF |  | Q1 | SOT-23-3_L2.9-W1.6-P1.90-LS2.8-BR | 1
17 | 0 | 贴片电阻 | R1 | R-0805 | 1
18 | 10K | 贴片电阻 | R2, R5, R10 | R-0603 | 3
19 | TPM2S103P110R |  | R3, R4, R6, R7, R8, R9, R20 | R-0603 | 7
20 | 10K | 电阻 | R11, R14, R18, R19 | R-0805 | 4
21 | 0Ω | 0603 | R12 | R-0805 | 1
22 | 55Ω | 0603 | R13 | R-0805 | 1
23 | 10K | 电阻 | R15 | C-0603 | 1
24 | 100kΩ | 电阻类型 | R16, R17 | r0805 | 2
25 | Key |  | SW1, SW2, SW3, SW4 | 12X12轻触按键 | 4
26 | TF-012 |  | TF1 | TF-SMD_TF-012 | 1
27 | AT24C02 |  | U1 | SOIC-8 | 1
28 | Ra-02 |  | U2 | WIRELM-SMD_RA-02-BL | 1
29 | AMS1117-2.85 | AMS 800mA LOW DROPOUT VOLTAGE REGULATOR | U3 | SOT-223-4 | 1
30 | STM32F407VGT6 |  | U4 | LQFP-100_L14.0-W14.0-P0.50-LS16.0-BL | 1
31 | 32768 |  | U5 | CRYSTAL-SMD_L3.2-W1.5 | 1
32 | 2N7002H6327 |  | U6 | PG-SOT23-3_L2.9-W1.3-P1.90-LS2.4-BR | 1
33 | CT1720KR |  | U7 | SOT-23-3 | 1
34 | U8 |  | U8 | 4G | 1
35 | 8MHz |  | X1 | CRYSTAL-SMD_4P-L3.2-W2.5-BL | 1

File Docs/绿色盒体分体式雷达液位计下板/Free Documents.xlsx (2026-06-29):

序号 | 参数/值 | 名称 | 位号 | 封装 | 数量
1 | BRIDGE1 | 整流桥 | B1 | DB107S | 1
2 | 470uF | 电解电容 | C3 | CAP-TH_BD10.0-P5.00-D1.0-FD | 1
3 | 47UF | 贴片电容 | C4 | C-1206 | 1
4 | 10UF | 电解电容 | C5, C6 | CAP-TH_BD5.0-P2.00-D0.8-FD | 2
5 | 100nF/250V | 安规电容 | C7 | #104K/275VAC | 1
6 | 100uF/35V | 电解电容 | C8 | CAP-TH_BD8.0-P3.50-D0.6-FD | 1
7 | 100nF/50V | 贴片电容 | C9, C10, C12, C14, C34, C40 | C-0805 | 6
8 | 220uF/35V | 电解电容 | C11 | CAP-TH_BD8.0-P3.50-D0.6-FD | 1
9 | 35V/220uF | 电解电容 | C13 | CAP-TH_BD8.0-P3.50-D0.6-FD | 1
10 | 10uF | 贴片电容 | C35 | C-0805 | 1
11 | 100nF | 贴片电容 | C36, C39 | C-0805 | 2
12 | 470nF | 贴片电容 | C37, C38 | C-0805 | 2
13 | SS34 | 二极管 | D1, D2 | DO-214AC | 2
14 | 1N4148 | 二极管 | D3 | LL-34 | 1
15 | 1N4732 | 稳压二极管 | D4 | DO-214AC | 1
16 | M7 | 二极管 | D5, D6, D7, D8 | DO-214AC | 4
17 | SM712 | TVS管 | D9 | SOT-23-3 | 1
18 | Fuse | 保险管 | F1 | FUSE-SMD_2410 | 1
19 | HDR2.54-LI-2X8P | 牛角座 | J1 | IDC-TH_16P-P2.54_BOOMELE-2X8P | 1
20 | 8050 |  | JQ1, JQ2, JQ3, JQ4 | SOT-23-3_(三极管) | 4
21 | HK4100F-DC5V-SHG | 继电器 | K1, K2, K3, K4 | HK4100F | 4
22 | 22uH | 功率电感 | L1 | L-CD75-2 | 1
23 | 三脚电阻选择接通焊盘 | 选通焊盘 | NC | 三脚电阻选择接通焊盘 | 1 | 不贴，位置备选贴0欧姆电阻用
24 | WJ500V-5.08-2P | 连接器 | P1, P3, P4, P5, P6, P7, P8, P9, P10 | KF128-2P DG128 | 9
25 | P1X2 | 排针 | P2 | KF128-2P DG128 | 1
26 | PCA817 | 光耦继电器 | PH1 | SMD-4_L6.5-W4.6-P2.54-LS10.3-TL | 1
27 | BD238 | 三极管 | Q2 | TO-126 | 1
28 | PMBT3906 | 三极管 | Q3 | SOT-23-3 | 1
29 | 10D561K_C113236 | 压敏电阻 | R8 | 10D561K | 1
30 | 10K | 贴片电阻 | R9 | R-0805 | 1
31 | 1.2K/1% | 贴片电阻 | R10 | R-0805 | 1
32 | 2K/1% | 贴片电阻 | R11 | R-0805 | 1
33 | 120 | 贴片电阻 | R19, R29 | R-0805 | 2
34 | 2k | 贴片电阻 | R20, R21, R23, R30, R31 | R-0805 | 5
35 | 5k1/1% | 贴片电阻 | R22 | R-0805 | 1
36 | 100R/1% | 贴片电阻 | R24 | R-0805 | 1
37 | 5k/1% | 贴片电阻 | R25 | R-0805 | 1
38 | 100k/1% | 贴片电阻 | R26, R27 | R-0805 | 2
39 | 10k/1% | 贴片电阻 | R28 | R-0805 | 1
40 | 1k | 贴片电阻 | R32, R33, R34, R35 | R-0805 | 4
41 | AC/DC (220V转24V) | A888(具体型号问保定高工) | U3 | a888 | 1
42 | LM1117 | 芯片 | U4 | SOT-223-3_L6.5-W3.4-P2.30-LS7.0-BR | 1
43 | TPS5430 | 芯片 | U5 | ESOP-8 | 1
44 | SN75LBC176DR | 芯片 | U8, U12 | SOP-8 | 2
45 | LM385-2.5V | 电压基准芯片 | U9 | TO-92 | 1
46 | 74LVC1G04 | 逻辑门芯片 | U10 | SOT-23-5 | 1
47 | TL074 | 运放芯片 | U11 | SO-14 | 1

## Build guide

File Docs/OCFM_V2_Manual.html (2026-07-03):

# OCFM_V2 明渠流量计

用户手册 — 设置参数 / 流量参考 / Modbus 通信

固件 v1.00 基于 ISO 4359 / ISO 1438

## #快速开始

#### 开箱流程

1. 上电，等待 3 秒初始化完成（屏幕显示主界面）
2. 长按 OK 进入设置菜单
3. 按 UP/DOWN 选 水渠，进入后设置 渠道类型、水槽编号
4. 进入 测量参数，根据传感器规格设置 窗口宽度、滤波次数 等
5. 长按 SHIFT 进入 历史查询，确认传感器数据
6. 主屏 短按 UP/DOWN 切换瓦片页查看详情 / 趋势 / 累计

#### 首次使用提醒

- 渠道类型/水槽编号改变后，水位上下限会被自动覆盖为新槽型默认值
- 4-20mA 校准值范围 0~7999，超出有效范围的值可能导致电流输出不准确
- 出厂默认 4mA 校准值 1063，20mA 校准值 5556，一般无需重新校准

## #按键操作

按键 | 主屏 (详情/趋势/累计) | 设置菜单 (3 级) | 编辑参数
OK | 长按 = 进入设置 (启用密码时先验证) | 进入下一级 / 保存并返回上级 | 保存当前值
UP | 短按 = 切换到上一瓦片页 | 选择上一项 | 增加当前值 (按当前步进)
DOWN | 短按 = 切换到下一瓦片页 | 选择下一项 | 减少当前值 (按当前步进)
SHIFT | 长按 = 进入历史查询 | 返回上一级 | 短按 = 切换步进 (1/10/100/...)，长按 = 取消编辑

#### 步进切换 (SHIFT 短按)

进入编辑页后短按 SHIFT，步进在 1 → 10 → 100 → 1000 → 10000 之间循环。 当前步进位会高亮显示，方便快速定位要修改的位数。 累计流量编辑器支持更宽的步进范围。

## #菜单结构

主屏
 ├─ 短按 UP/DOWN        切换 详情 / 趋势 / 累计 (3 个瓦片页循环)
 ├─ 长按 SHIFT          → 历史查询
 └─ 长按 OK             → 设置
                            │
                            ├─ 基本参数      (3 项)
                            ├─ Modbus 设置   (3 项)
                            ├─ 报警参数      (6 项)
                            ├─ 水渠/堰槽     (9 项)
                            ├─ 测量参数      (6 项)
                            ├─ 显示设置      (4 项)
                            ├─ 高级设置      (8 项)
                            └─ 时间设置      (7 项)

历史查询
 ├─ 日期选择 (UP/DOWN 调值，SHIFT 切年/月/日/时)
 └─ 数据浏览 (左右 21 条缓存)

15 秒无操作自动返回主屏。在设置菜单任一层级停留超过 15 秒将自动退出，避免意外耗电或挡操作。

## #基本参数

与传感器直接交互的基础测量参数，以及 4-20mA 输出量程。

显示名 | 范围 | 步进 | 默认值 | 说明
安装高度 (Height) | 0 ~ 最大量程 | 0.001 m | 5000 mm (5.000 m) | 传感器到渠底的距离 (mm)，水位 = 安装高度 - 测量距离。 限制：不能超过最大量程。
4mA 量程 | 0 ~ 99999 m³/h | 0.001 | 0.0 m³/h | 对应电流输出 4mA 时的流量值。设为 0 时电流钳位到 4mA。
20mA 量程 | 0 ~ 槽型上限×1.2 | 0.001 | 19.354 m³/h | 对应电流输出 20mA 时的流量值。 范围受限于当前槽型理论最大流量 × 1.2 倍裕量。 修改渠道类型/水槽编号时会自动填入新槽型的理论最大值。

## #Modbus 设置

本机通信口的参数。修改波特率/停止位后会立即生效，影响所有上位机通信。

显示名 | 范围 | 默认值 | 说明
从机地址 (Slave Addr) | 1 ~ 247 | 1 | Modbus 从机地址 1~247，0 为广播地址 (一般不用)。
波特率 (Baud Rate) | 1 ~ 8 | 2 (9600) | 循环切换：1=4800 / 2=9600 / 3=14400 / 4=19200 / 5=38400 / 6=56000 / 7=57600 / 8=115200。
停止位 (Stop Bits) | 1 ~ 4 | 1 (8N1) | 1=8N1 (None+1Stop) / 2=8O1 (Odd+1Stop) / 3=8N2 (None+2Stop) / 4=8E1 (Even+1Stop)。 注意：8O1/8E1 时数据位为 9，校验位会占用第 9 位。

## #报警参数

四路继电器对应的报警阈值与回差。瞬时流量与各阈值实时比较，超出触发吸合。

显示名 | 继电器 | 范围 | 默认值 | 说明
上限报警 (Alarm High) | 继电器 1 | 0 ~ 99999 | 19.44 m³/h | 流量 ≥ AH 触发吸合；流量 < AH - DH 恢复释放。
下限报警 (Alarm Low) | 继电器 2 | 0 ~ 99999 | 0.0 m³/h | 流量 ≤ AL 触发吸合；流量 > AL + DL 恢复释放。
上上限报警 (Alarm HH) | 继电器 3 | ≥ AH | 100.0 m³/h | 流量 ≥ AAH 触发吸合；流量 < AAH - DH 恢复释放。回差与 AH 共用 DH。
下下限报警 (Alarm LL) | 继电器 4 | ≤ AL | 0.0 m³/h | 流量 ≤ AAL 触发吸合；流量 > AAL + DL 恢复释放。回差与 AL 共用 DL。
上限回差 (Alarm High DB) | — | 0 ~ 99999 | 2.0 m³/h | AH 与 AAH 共用的回差。流量必须低于 (阈值 - DH) 才解除。
下限回差 (Alarm Low DB) | — | 0 ~ 99999 | 2.0 m³/h | AL 与 AAL 共用的回差。流量必须高于 (阈值 + DL) 才解除。

#### 关联校验

设置 AAH 时不能小于 AH；设置 AAL 时不能大于 AL。 违反时系统会提示参数冲突。

## #水渠/堰槽

渠道类型、水槽规格、累计流量显示和清零操作。修改渠道类型/水槽编号会重新计算并覆盖水位上下限。

显示名 | 范围 | 默认值 | 说明
渠道类型 (Canal Type) | 1 ~ 3 | 1 (巴歇尔槽) | 1=巴歇尔槽 / 2=三角堰 / 3=矩形堰。
水槽编号 (Channel ID) | 1 ~ (依槽型) | 1 | 巴歇尔槽: 1~16；三角堰: 1~5；矩形堰: 1~4。 切换时会按当前类型重新限制最大值。
渠宽 (Ch Width) | 0 ~ 10000 mm | 0 | 矩形堰渠道宽度。0 = 全宽堰，不做收缩修正；>0 且 > 堰宽时按收缩堰计算。
堰高 (Weir Ht) | 0 ~ 10000 mm | 0 | 矩形堰堰高 p (预留参数)。
水位上限 (WL Upper) | 0 ~ 10 m | 按槽型自动 | 流量计算的水位上限。 切换渠道类型/水槽编号时会自动填入新槽型的默认值。
水位下限 (WL Lower) | 0 ~ 10 m | 按槽型自动 | 流量计算的水位下限。低于此值瞬时流量返回 0。同样在切换槽型时被自动覆盖。
累计流量 (Total Flow) | 0 ~ 999999999999 m³ | 0.0 | 累计流量。可手动设定初始值。断电后自动恢复。
累计小数位 (Sum Decimal) | 0 ~ 3 | 1 | 累计流量显示的小数位数。
清零累计 (Clear Total) | 0 / 1 | 0 | 设为 1 并按 OK 清除累计流量和累计时长 (不可撤销)。

## #测量参数

传感器端的高级参数。一般情况下使用传感器出厂默认即可，仅在信号质量差或特殊工况下调整。

显示名 | 范围 | 默认值 | 说明
窗口宽度 (Filter Width) | 0 ~ 1000 | 100 | 滑动平均窗口的样本数。越大输出越平滑，但响应越慢。
滤波次数 (Filter Count) | 0 ~ 50 | 2 | 中值/均值滤波的迭代次数。
采样延迟 (Sample Rate) | 0 ~ 1000 ms | 50 ms | 传感器两次采样之间的间隔。值越大功耗越低，但响应越慢。
盲区 (Blind Area) | 0 ~ 1000 mm | 50 mm | 传感器正下方的测量盲区。距离 < 盲区 时数据无效。
加权平均 (Wgt Average) | 0 ~ 10 | 8 | 传感器加权平均系数 W。
阻尼 (Damping) | 0 ~ 10 | 3 | 传感器测量系数 M，影响阻尼强度。

## #显示设置

显示名 | 范围/选项 | 默认值 | 说明
语言 (Language) | 0=English / 1=中文 | 1 (中文) | 切换语言会重新加载菜单字串。
小数位数 (Decimal) | 0 ~ 3 | 3 | 瞬时流量显示的小数位数。大数值会自动缩减小数位以保持可读性。
流量单位 (Flow Unit) | 1 ~ 8 | 4 (m³/h) | 1=L/s / 2=L/min / 3=L/h / 4=m³/h / 5=m³/s / 6=m³/min / 7=T/h / 8=G/h (美制加仑/小时)。
显示报警 (Show Alarm) | 0 / 1 | 1 (显示) | 主屏是否显示报警指示。关闭后主屏不再显示报警图标，但仍正常触发继电器。

## #高级设置

出厂校准与系统维护操作。普通用户无需修改。

显示名 | 范围 | 默认值 | 说明
最大量程 (Range Max) | 0 ~ 20000 mm | 5000 | 传感器量程上限 (mm)。 修改时同步把"高度"也设为相同值。
天线类型 (Antenna Type) | 0 ~ 10 | 1 | 根据实际传感器类型设置 (具体值参考传感器手册)。
4mA 校准 (4mA Cal) | 0 ~ 7999 | 1063 | 4mA 对应的校准输出值。 进入编辑会立即输出对应电流 (实时校准)，校准完成后按 OK 保存。
20mA 校准 (20mA Cal) | 0 ~ 7999 | 5556 | 20mA 对应的校准输出值。
距离偏移 (Dist Offset) | 0 ~ 99999 mm | 10 | 距离补偿值，用于修正传感器安装偏差。
密码锁 (Password Lock) | 0 / 1 | 0 (关闭) | 启用后进入设置菜单需先输入密码 (固定 1234)。
恢复出厂 (Factory Reset) | 0 / 1 | 0 | 设为 1 并按 OK 恢复所有参数为出厂默认值 (校准值会保留)。
清除存储数据 (Clear SD Data) | 0 / 1 | 0 | 设为 1 并按 OK 清除 SD 卡上所有日志和历史记录。屏幕显示进度条 (0~100%)，完成后自动返回。

#### 校准警告

修改 4mA/20mA 校准值会立即改变电流输出。校准过程中请用万用表监测 4-20mA 回路电流， 防止电流过载损坏外部设备。校准完成后必须按 OK 保存，否则退出编辑页会恢复原值。

## #时间设置

设备时钟。断电后由备用电池维持。

显示名 | 范围 | 说明
年 (Year) | 2000 ~ 2099 | 4 位年份。
月 (Month) | 1 ~ 12 | —
日 (Day) | 1 ~ 31 | —
时 (Hour) | 0 ~ 23 | 24 小时制。
分 (Minute) | 0 ~ 59 | —
秒 (Second) | 0 ~ 59 | —
星期 (Weekday) | 1 ~ 7 | 1=周一 / 7=周日。

## #计算逻辑

设备通过传感器测量水位，再根据所选堰槽公式计算瞬时流量：

水位范围 | 计算结果
低于水位下限 | 瞬时流量 = 0
在水位上下限之间 | 按堰槽公式正常计算
高于水位上限 | 按上限值计算（提示溢出）

水位上下限来源： 首次切换渠道类型/水槽编号时，设备自动填入当前槽型的默认水位范围。用户可在设置菜单中独立修改。再次切换槽型会覆盖用户修改。

## #巴歇尔槽 (Parshall Flume)

标准： ISO 4359

公式： Q = K × H^n，不使用 Kh 水头修正。

# | 喉道宽度 (m) | K | n | H_min (m) | H_max (m) | Q_min (L/s) | Q_max (L/s)

1 | 0.025 | 60.4 | 1.550 | 0.015 | 0.21 | 0.09 | 5.4
2 | 0.051 | 120.7 | 1.550 | 0.015 | 0.24 | 0.18 | 13.2
3 | 0.076 | 177.1 | 1.550 | 0.030 | 0.33 | 0.77 | 32.1
4 | 0.152 | 381.2 | 1.540 | 0.030 | 0.45 | 1.50 | 111.0
5 | 0.228 | 535.4 | 1.530 | 0.030 | 0.60 | 2.50 | 251.0
6 | 0.250 | 561.0 | 1.513 | 0.030 | 0.60 | 3.00 | 250.0
7 | 0.300 | 679.0 | 1.521 | 0.030 | 0.75 | 3.50 | 400.0
8 | 0.450 | 1038.0 | 1.537 | 0.030 | 0.75 | 4.50 | 630.0
9 | 0.600 | 1403.0 | 1.548 | 0.050 | 0.75 | 12.50 | 850.0
10 | 0.750 | 1772.0 | 1.557 | 0.060 | 0.75 | 25.00 | 1100.0
11 | 0.900 | 2147.0 | 1.565 | 0.060 | 0.75 | 30.00 | 1250.0
12 | 1.000 | 2397.0 | 1.569 | 0.060 | 0.80 | 30.00 | 1500.0
13 | 1.200 | 2904.0 | 1.577 | 0.060 | 0.80 | 35.00 | 2000.0
14 | 1.500 | 3668.0 | 1.586 | 0.060 | 0.80 | 45.00 | 2500.0
15 | 1.800 | 4440.0 | 1.593 | 0.080 | 0.80 | 80.00 | 3000.0
16 | 2.100 | 5222.0 | 1.599 | 0.080 | 0.80 | 95.00 | 3600.0

## #三角堰 (V-Notch Weir)

标准： ISO 1438, Kindsvater-Shen 方法

公式： Q = K × (H + Kh)².⁵

有效范围： θ = 20° ~ 100° (USBR 推荐 25° ~ 100°)

# | 角度 θ | Ce | K (L/s) | Kh (m) | H_min (m) | H_max (m) | Q_min (L/s) | Q_max (L/s)

1 | 90° | 0.5779 | 1365.0 | 0.00301 | 0.05 | 0.40 | 0.88 | 140.7
2 | 60° | 0.5767 | 786.4 | 0.00176 | 0.05 | 0.35 | 0.48 | 57.7
3 | 45° | 0.5802 | 567.8 | 0.00177 | 0.05 | 0.30 | 0.35 | 28.4
4 | 30° | 0.5864 | 371.1 | 0.00221 | 0.05 | 0.25 | 0.23 | 11.9
5 | 22.5° | 0.5906 | 277.5 | 0.00259 | 0.05 | 0.25 | 0.18 | 8.90

系数拟合公式

Ce   = 0.607165052 - 0.000874467×θ + 6.103933×10⁻⁶×θ²
Kh(ft) = 0.01449 - 0.0003396×θ + 3.298×10⁻⁶×θ² - 1.062×10⁻⁸×θ³
Kh(m)  = Kh(ft) × 0.3048

## #矩形堰 (Rectangular Weir)

标准： ISO 1438, Francis 公式 + Kh 修正

公式： Q = K × be × (H + Kh)¹.⁵，其中 K = 1838 (Francis Cd=0.622)，Kh = 0.001 m

# | 堰宽 b (m) | K | Kh (m) | H_min (m) | H_max (m) | Q_min (L/s) | Q_max (L/s)

1 | 0.5 | 1838.0 | 0.001 | 0.05 | 0.50 | 10.6 | 326.0
2 | 1.0 | 1838.0 | 0.001 | 0.05 | 0.60 | 21.2 | 856.0
3 | 1.5 | 1838.0 | 0.001 | 0.05 | 0.70 | 31.8 | 1618.0
4 | 2.0 | 1838.0 | 0.001 | 0.05 | 0.80 | 42.3 | 2635.0

### 侧收缩修正

当 渠宽 B > 0 且 B > b 时按收缩堰处理：

b_e = b - 0.2 × H
若 b_e < 0 → b_e = 0
- B = 0 → 全宽堰，b_e = b
- B > 0 且 B ≤ b → 不收缩，b_e = b
- B > b → 按上式修正 b_e

示例：全宽堰 vs 收缩堰 (1.0m 堰宽, H=0.3m)

全宽堰 (B = 0):
  b_e = 1.0
  Q = 1838.0 × 1.0 × 0.301^1.5 = 303.5 L/s

收缩堰 (B = 2.0m):
  b_e = 1.0 - 0.2 × 0.30 = 0.94
  Q = 1838.0 × 0.94 × 0.301^1.5 = 285.3 L/s

## #单位换算

计算结果根据流量单位设置自动转换：

单位 | 转换公式 | 设置值
L/s | Q × 1 | 1
L/min | Q × 60 | 2
L/h | Q × 3600 | 3
m³/h | Q × 3.6 | 4
m³/s | Q / 1000 | 5
m³/min | Q / 1000 × 60 | 6
T/h | Q × 3.6 (同 m³/h) | 7
G/h (美制加仑/时) | Q × 3600 / 3.785411784 | 8

## #常见问题

### Q: 主屏一直显示 "L:error" ？

传感器离线。检查：

1. 传感器电源/线缆是否松动
2. 传感器地址是否与本机配置一致
3. 传感器波特率/停止位是否与本机一致
4. 查看设备日志中是否有传感器离线记录

### Q: 修改了 4-20mA 量程后电流没变化？

检查当前瞬时流量是否在 4mA 和 20mA 量程范围内。若瞬时流量 < 4mA 量程则电流钳位到 4mA；若 > 20mA 量程则钳位到 20mA。

### Q: 累计流量断电后丢了一部分？

设备每 2 秒自动保存累计数据，断电后最大丢失 2 秒数据。如果备用电池耗尽，可能丢失更多数据，建议定期更换电池。

### Q: 修改渠道类型后水量上下限变了？

这是正常行为。渠道类型 / 水槽编号变更时会自动覆盖水位上下限为新槽型默认值，如需自定义请在切换后重新调整。

### Q: 20mA 量程无法设置到很大？

20mA 量程上限被限制为"当前槽型理论最大流量 × 1.2 倍裕量"。这是为了保证输出电流有合理的分辨率。如需更大的量程，请更换支持更大流量的水槽规格。

### Q: 继电器不动作？

1. 检查传感器是否离线 (离线时所有报警清除)
2. 检查报警阈值设置 (AAH ≥ AH, AAL ≤ AL)
3. 检查主屏 显示报警 选项是否关闭 (仅影响 UI 指示，不影响继电器)

## #附录：Modbus 寄存器表

#### 通信参数

RS485 | Modbus RTU | 从机地址默认 1 | 波特率默认 9600 | 8N1
功能码： 03 读保持寄存器 / 06 写单寄存器 / 16 写多寄存器

### 1. 实时数据区 (只读)

地址 | 名称 | 类型 | 单位 | 说明
0x0001 | 水位 (物位) | R uint16 | mm | 水位 = 安装高度 - 距离
0x0002 | 距离 | R uint16 | mm | 传感器到水面距离
0x0003 | 温度 | R uint16 | 0.1°C | 值 256 = 25.6°C
0x0004~05 | 瞬时流量 | R float | 由 0x0103 决定 | 当前瞬时流量
0x0006~09 | 累计流量 | R double | m³ | 累计总量
0x000A | 继电器1状态 | R uint16 | — | 0=断开 (AH)
0x000B | 继电器2状态 | R uint16 | — | 0=断开 (AL)
0x000C | 继电器3状态 | R uint16 | — | 0=断开 (AAH)
0x000D | 继电器4状态 | R uint16 | — | 0=断开 (AAL)

0x000A~0x000D 继电器状态只读，不允许写入。继电器由报警逻辑自动控制。

### 2. 报警参数区 (读写)

地址 | 名称 | 类型 | 单位 | 默认 | 说明
0x000E~0F | 上限报警值 (AH) | RW float | m³/h | 19.44 | 流量 ≥ AH 触发
0x0010~11 | 上限回差 (DH) | RW float | m³/h | 2.0 | 流量 < AH - DH 恢复
0x0012~13 | 下限报警值 (AL) | RW float | m³/h | 0.0 | 流量 ≤ AL 触发
0x0014~15 | 下限回差 (DL) | RW float | m³/h | 2.0 | 流量 > AL + DL 恢复
0x0016~17 | 上上限报警值 (AAH) | RW float | m³/h | 100.0 | 流量 ≥ AAH 触发；恢复: 流量 < AAH - DH
0x0018~19 | 下下限报警值 (AAL) | RW float | m³/h | 0.0 | 流量 ≤ AAL 触发；恢复: 流量 > AAL + DL

### 3. 传感器参数区 (读写)

写入后自动同步到传感器（在线时）；传感器首次上线也会自动同步所有参数。

地址 | 名称 | 类型 | 单位 | 默认 | 说明
0x0065 | 最大量程 | RW uint16 | mm | 5000 | 传感器量程上限
0x0066 | 安装高度 | RW uint16 | mm | 5000 | 水位 = 高度 - 距离
0x0067 | 窗口宽度 (L1) | RW uint16 | — | 100 | 滑动平均窗口
0x0068 | 滤波次数 (L2) | RW uint16 | — | 2 | —
0x0069 | 采样延迟 (L3) | RW uint16 | ms | 50 | —
0x006A | 盲区 (L4) | RW uint16 | mm | 50 | —
0x006B | W 系数 (L5) | RW uint16 | — | 8 | —
0x006C | M 系数 (L6) | RW uint16 | — | 3 | —
0x006D | 从机地址 | RW uint16 | — | 1 | 本机地址 1~247
0x006E | 波特率 | RW uint16 | — | 2 (9600) | 1=4800 / 2=9600 / 3=14400 / 4=19200 / 5=38400 / 6=56000 / 7=57600 / 8=115200
0x006F | 停止位 | RW uint16 | — | 1 (8N1) | 1=8N1 / 2=8O1 / 3=8N2 / 4=8E1

### 4. 从机参数区 (读写)

地址 | 名称 | 类型 | 单位 | 默认 | 说明
0x0101 | 渠道类型 | RW uint16 | — | 1 | 1=巴歇尔槽 / 2=三角堰 / 3=矩形堰
0x0102 | 水槽编号 | RW uint16 | — | 1 | 切换时自动填入默认水位上下限
0x0103 | 瞬时流量单位 | RW uint16 | — | 4 | 1=L/s / 2=L/min / 3=L/h / 4=m³/h / 5=m³/s / 6=m³/min / 7=T/h / 8=G/h
0x0104 | 累计小数位 | RW uint16 | — | 1 | —
0x0105~06 | 4mA 量程 | RW float | m³/h | 0.0 | —
0x0107~08 | 20mA 量程 | RW float | m³/h | 19.354 | 不超过槽型最大流量 × 1.2
0x0109 | 渠宽 | RW uint16 | mm | 0 | 0=全宽堰
0x010A | 堰高 | RW uint16 | mm | 0 | 预留
0x010B~0C | 水位上限 | RW float | m | 按槽型 | 切换渠道/水槽时自动覆盖
0x010D~0E | 水位下限 | RW float | m | 按槽型 | 切换渠道/水槽时自动覆盖

### 5. 出厂校准区 (读写)

地址 | 名称 | 类型 | 单位 | 默认 | 说明
0x1001 | 天线类型 | RW uint16 | — | 1 | —
0x1002 | 距离偏移 | RW uint16 | mm | 10 | —
0x1003 | 4mA 校准 | RW uint16 | 校准值 | 1063 | 写入后立即生效
0x1004 | 20mA 校准 | RW uint16 | 校准值 | 5556 | 写入后立即生效
0x1005 | 恢复出厂设置 | W uint16 | — | 0 | 写 1 触发，完成后自动复位为 0
0x1006 | 清除累计 | W uint16 | — | 0 | 写 1 清除累计流量和累计时间

一次性动作寄存器： 0x1005 / 0x1006 写入 1 触发操作后会自动复位为 0，请使用 FC06 写入。

### 6. RTC 时间区 (读写)

写入任一寄存器立即读取全部 7 个并更新 RTC。建议用 FC16 一次性写入。

地址 | 名称 | 范围 | 说明
0x0200 | 年 | 2000~2099 | —
0x0201 | 月 | 1~12 | —
0x0202 | 日 | 1~31 | 自动校验闰年
0x0203 | 时 | 0~23 | —
0x0204 | 分 | 0~59 | —
0x0205 | 秒 | 0~59 | —
0x0206 | 星期 | 1~7 | 1=周一 / 7=周日

OCFM_V2 明渠流量计

标准: ISO 4359 (Parshall Flume), ISO 1438 (Weirs)

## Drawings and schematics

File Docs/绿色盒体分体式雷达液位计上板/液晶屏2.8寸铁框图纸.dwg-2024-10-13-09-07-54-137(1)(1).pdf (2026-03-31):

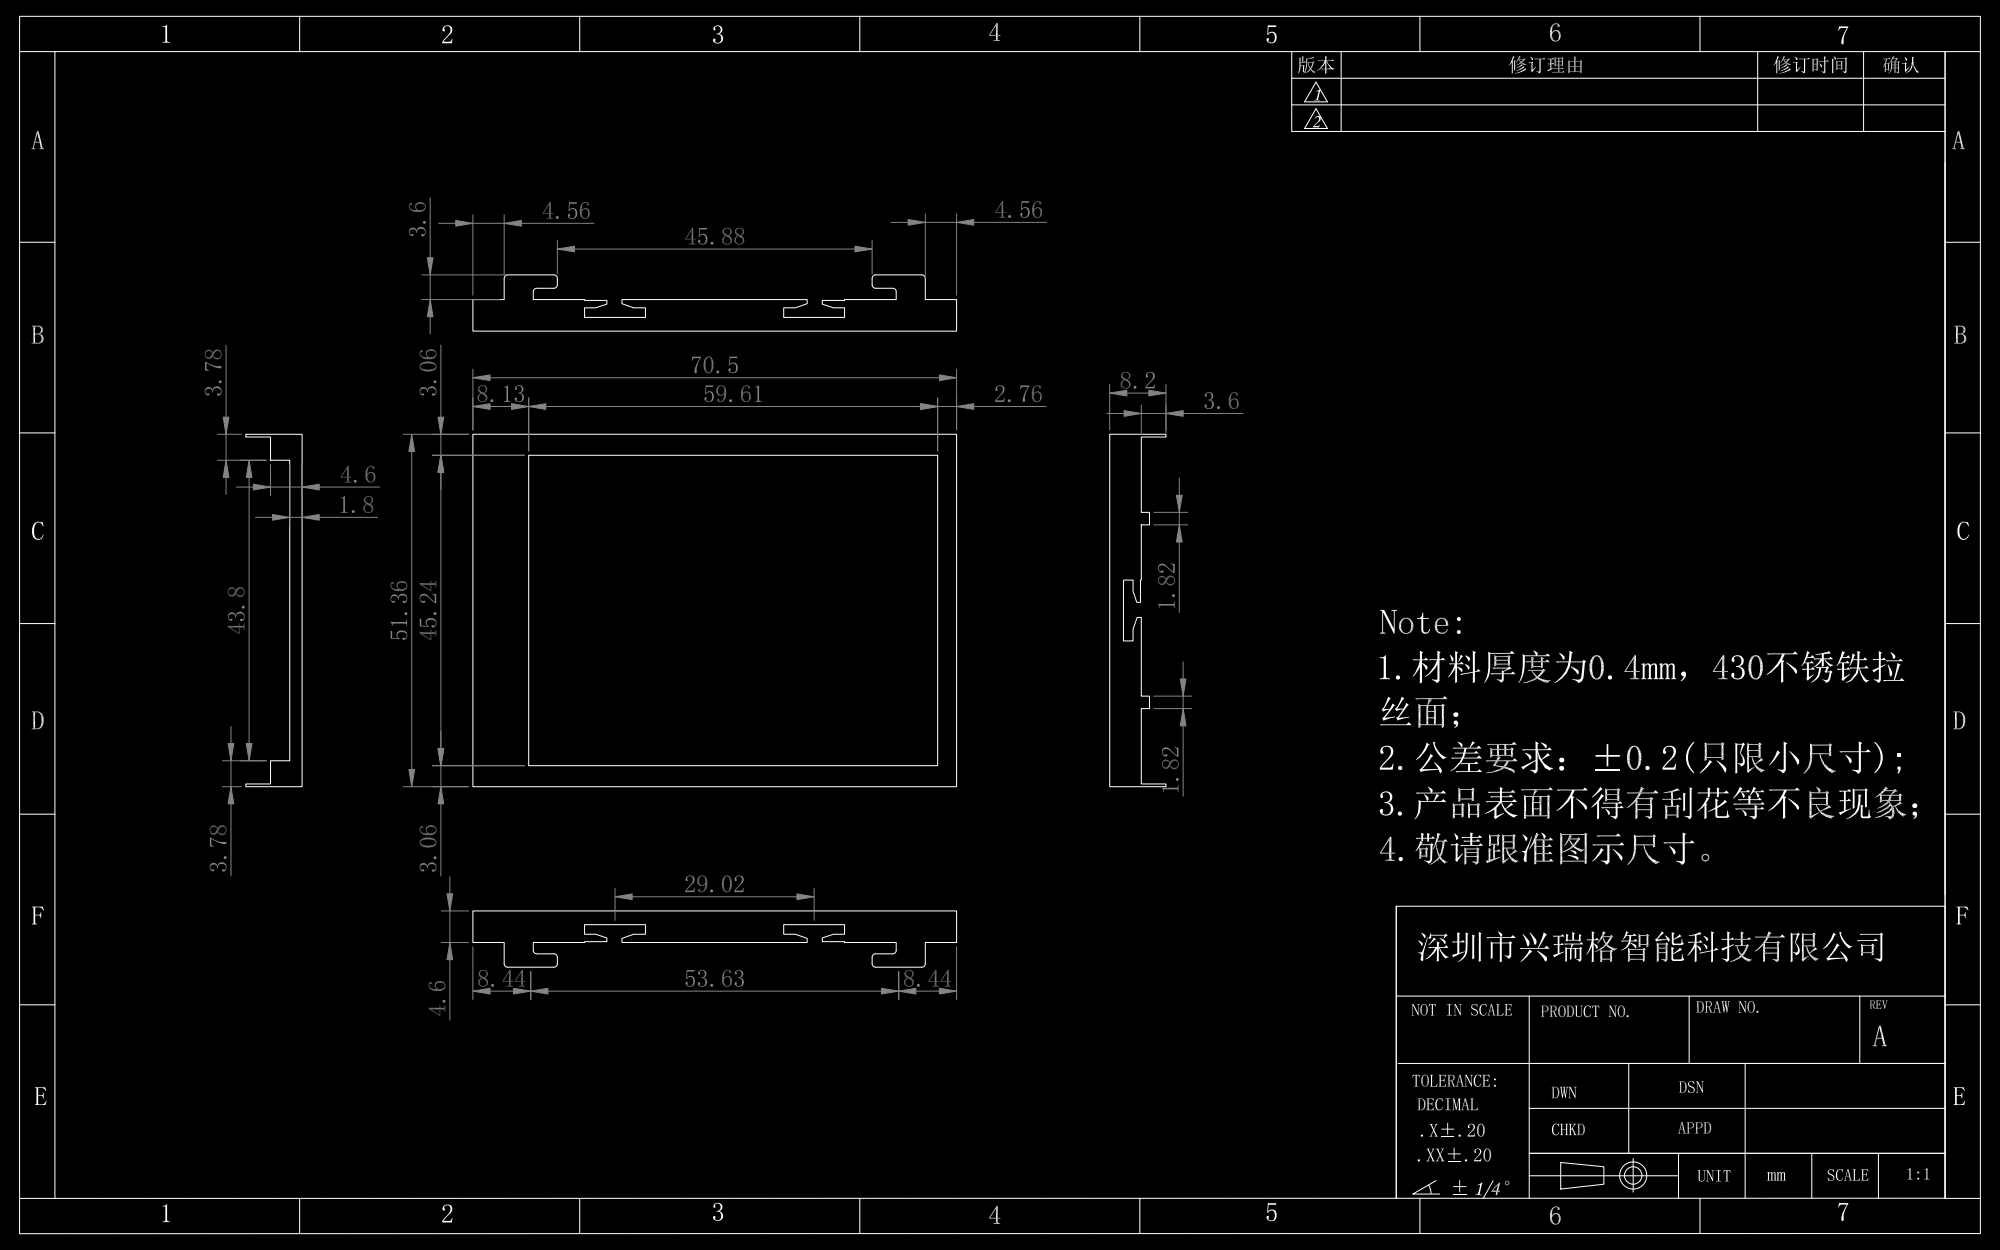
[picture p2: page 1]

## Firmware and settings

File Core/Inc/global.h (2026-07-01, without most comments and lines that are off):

#define __GLOBAL_H
#include "main.h"
#include "usart.h"
#include "gpio.h"
#include "at24c02.h"
#include "fsmc_st7789.h"
#include "fatfs.h"
#include "file_driver.h"
#include "data_recorder.h"
#include "log_manager.h"
#include "rtc_time.h"
#include "ui/ui.h"
#define FIRMWARE_VERSION        0x0100
#define HOLDING_REG_SIZE        128
#define MODBUS_SLAVE_BUF_SIZE   256
#define MODBUS_SLAVE_ID         1
#define MODBUS_MASTER_TIMEOUT_MS    500
#define MODBUS_MAX_SLAVE_COUNT      2
#define MODBUS_MAX_RETRY            10
#define REG_WUWEI               0x0001
#define REG_DISTANCE            0x0002
#define REG_TEMPERATURE         0x0003
#define REG_INSTANT_FLOW        0x0004
#define REG_SUM_FLOW            0x0006
#define REG_RELAY1_STATUS       0x000A
#define REG_RELAY2_STATUS       0x000B
#define REG_RELAY3_STATUS       0x000C
#define REG_RELAY4_STATUS       0x000D
#define REG_AH                  0x000E
#define REG_DH                  0x0010
#define REG_AL                  0x0012
#define REG_DL                  0x0014
#define REG_AAH                 0x0016
#define REG_AAL                 0x0018
#define REG_TOTAL_TIME          0x001A
#define REG_RANGE_MAX           0x0065
#define REG_HEIGHT              0x0066
#define REG_L1                  0x0067
#define REG_L2                  0x0068
#define REG_L3                  0x0069
#define REG_L4                  0x006A
#define REG_L5                  0x006B
#define REG_L6                  0x006C
#define REG_ADDRESS             0x006D
#define REG_BAUDE_RATE          0x006E
#define REG_STOP_BITS           0x006F
#define REG_CANALS__TYPE        0x0101
#define REG_CHANNEL_ID          0x0102
#define REG_INSTANT_UNIT        0x0103
#define REG_SUM_POINT           0x0104
#define REG_RANGE_4MA           0x0105
#define REG_RANGE_20MA          0x0107
#define REG_CHANNEL_WIDTH       0x0109
#define REG_WEIR_HEIGHT         0x010A
#define REG_WATER_LEVEL_UP      0x010B
#define REG_WATER_LEVEL_DOWN    0x010D
#define REG_ANTENNA_TYPE        0x1001
#define REG_DIS_OFFSET          0x1002
#define REG_CALIBRATION_4MA     0x1003
#define REG_CALIBRATION_20MA    0x1004
#define REG_FACTORY_SETTING     0x1005
#define REG_CLEAR_TOTAL         0x1006
#define REG_RTC_YEAR            0x0200
#define REG_RTC_MONTH           0x0201
#define REG_RTC_DAY             0x0202
#define REG_RTC_HOUR            0x0203
#define REG_RTC_MINUTE          0x0204
#define REG_RTC_SECOND          0x0205
#define REG_RTC_WEEKDAY         0x0206
#define SENSOR_ADDR_1           1
#define SENSOR_REG_DISTANCE     0x0005
#define SENSOR_REG_QUANTITY     1
#define SENSOR_COM_GAODU        0x0066
#define SENSOR_COM_L1           0x0067
#define SENSOR_COM_L2           0x0068
#define SENSOR_COM_L3           0x0069
#define SENSOR_COM_L4           0x006A
#define SENSOR_COM_L5           0x006B
#define SENSOR_COM_L6           0x006C
#define SENSOR_COM_FACTORY_LC   0x1000
#define SENSOR_COM_DEAD_ZONE    0x1001
#define SENSOR_COM_DIS_OFFSET  0x1002
#define DATA_RECORD_INTERVAL_MS   60000
#define ERROR_NONE              0
#define ERROR_SENSOR_TIMEOUT    1
#define ERROR_SENSOR_CRC        2
#define CONFIG_MAGIC_NUMBER    0xA5A5A5A5U
#define CONFIG_EEPROM_ADDR     0
#define TOTAL_FLOW_EEPROM_ADDR     232
#define TOTAL_FLOW_MAGIC_NUMBER    0x5A5A5A5AU
typedef struct
{
    uint32_t magic_number;
    uint32_t range_max;
    uint32_t height;
    uint32_t calibration_4ma;
    uint32_t calibration_20ma;
    float range_4ma;
    float range_20ma;
    uint32_t point_num;
    uint32_t window_width;
    uint32_t filter_count;
    uint32_t delay_time;
    uint32_t antenna_type;
    uint32_t blind_area;
    uint32_t w_coeff;
    uint32_t m_coeff;
    uint32_t modbusAddr;
    uint32_t modbusBaudRate;
    uint32_t modbusStopBits;
    float alarm_ah;
    float alarm_al;
    float alarm_dh;
    float alarm_dl;
    float alarm_aah;
    float alarm_aal;
    uint32_t factory_settings;
    uint32_t dis_offset;
    uint32_t canals_type;
    uint32_t channel_id;
    uint32_t channel_width;
    uint32_t weir_height;
    float water_level_up;
    float water_level_down;
    uint32_t instant_unit;
    uint32_t sum_point;
    uint32_t language;
    uint32_t show_alarm;
    uint32_t password_enable;
} SystemConfig_t;
typedef enum
{
    FLOW_UNIT_L_S = 1,
    FLOW_UNIT_L_MIN,
    FLOW_UNIT_L_H,
    FLOW_UNIT_M3_H,
    FLOW_UNIT_M3_S,
    FLOW_UNIT_M3_MIN,
    FLOW_UNIT_T_H,
    FLOW_UNIT_G_H,
} flow_unit_t;
typedef enum
{
    PARSHALL_FLUME = 1,
    TRIANGULAR_WEIR,
    RECTANGULAR_WEIR,
} canals_type_t;
#define CONFIG_FACTORY_RESET    0
#define DEFAULT_RANGE_MAX        5000
#define DEFAULT_HEIGHT           5000
#define DEFAULT_CALIBRATION_4MA  1063
#define DEFAULT_CALIBRATION_20MA 5556
#define DEFAULT_RANGE_4MA        0.0f
#define DEFAULT_RANGE_20MA       19.354f
#define DEFAULT_POINT_NUM        3
#define DEFAULT_WINDOW_WIDTH     100
#define DEFAULT_FILTER_COUNT     2
#define DEFAULT_DELAY_TIME       50
#define DEFAULT_ANTENNA_TYPE     1
#define DEFAULT_BLIND_AREA       50
#define DEFAULT_W_COEFF          8
#define DEFAULT_M_COEFF          3
#define DEFAULT_MODBUS_ADDR      1
#define DEFAULT_MODBUS_BAUD      2
#define DEFAULT_MODBUS_STOP      1
#define DEFAULT_ALARM_AH         19.44f
#define DEFAULT_ALARM_AL         0.0f
#define DEFAULT_ALARM_DH         2.0f
#define DEFAULT_ALARM_DL         2.0f
#define DEFAULT_ALARM_AAH        100.0f
#define DEFAULT_ALARM_AAL        0.0f
#define DEFAULT_FACTORY_SETTINGS 0
#define DEFAULT_DIS_OFFSET       10
#define DEFAULT_CANALS_TYPE      1
#define DEFAULT_CHANNEL_ID       1
#define DEFAULT_CHANNEL_WIDTH    0
#define DEFAULT_WEIR_HEIGHT      0
#define DEFAULT_WATER_LEVEL_UP   0.21f
#define DEFAULT_WATER_LEVEL_DOWN 0.015f
#define DEFAULT_INSTANT_UNIT     4
#define DEFAULT_SUM_POINT        3
#define DEFAULT_LANGUAGE         1
#define DEFAULT_SHOW_ALARM       1
#define DEFAULT_PASSWORD_ENABLE  0

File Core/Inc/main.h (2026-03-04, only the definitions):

#define LCD_RS_Pin GPIO_PIN_6
#define LCD_RS_GPIO_Port GPIOE
#define UART4_TX_Pin GPIO_PIN_0
#define UART4_TX_GPIO_Port GPIOA
#define UART4_RX_Pin GPIO_PIN_1
#define UART4_RX_GPIO_Port GPIOA
#define UART2_TX_Pin GPIO_PIN_2
#define UART2_TX_GPIO_Port GPIOA
#define UART2_RX_Pin GPIO_PIN_3
#define UART2_RX_GPIO_Port GPIOA
#define RELAY1_CTRL_Pin GPIO_PIN_4
#define RELAY1_CTRL_GPIO_Port GPIOA
#define RELAY2_CTRL_Pin GPIO_PIN_5
#define RELAY2_CTRL_GPIO_Port GPIOA
#define RELAY3_CTRL_Pin GPIO_PIN_6
#define RELAY3_CTRL_GPIO_Port GPIOA
#define RELAY4_CTRL_Pin GPIO_PIN_7
#define RELAY4_CTRL_GPIO_Port GPIOA
#define CT1820_Pin GPIO_PIN_0
#define CT1820_GPIO_Port GPIOB
#define PWM01_Pin GPIO_PIN_1
#define PWM01_GPIO_Port GPIOB
#define LCD_D4_Pin GPIO_PIN_7
#define LCD_D4_GPIO_Port GPIOE
#define LCD_D5_Pin GPIO_PIN_8
#define LCD_D5_GPIO_Port GPIOE
#define LCD_D6_Pin GPIO_PIN_9
#define LCD_D6_GPIO_Port GPIOE
#define LCD_D7_Pin GPIO_PIN_10
#define LCD_D7_GPIO_Port GPIOE
#define LCD_RESET_Pin GPIO_PIN_14
#define LCD_RESET_GPIO_Port GPIOE
#define EEPROM_SCL_Pin GPIO_PIN_10
#define EEPROM_SCL_GPIO_Port GPIOB
#define EEPROM_SDA_Pin GPIO_PIN_11
#define EEPROM_SDA_GPIO_Port GPIOB
#define LORA_NSS_Pin GPIO_PIN_12
#define LORA_NSS_GPIO_Port GPIOB
#define LORA_SCK_Pin GPIO_PIN_13
#define LORA_SCK_GPIO_Port GPIOB
#define LORA_MISO_Pin GPIO_PIN_14
#define LORA_MISO_GPIO_Port GPIOB
#define LORA_MOSI_Pin GPIO_PIN_15
#define LORA_MOSI_GPIO_Port GPIOB
#define ML307_TX_Pin GPIO_PIN_8
#define ML307_TX_GPIO_Port GPIOD
#define ML307_RX_Pin GPIO_PIN_9
#define ML307_RX_GPIO_Port GPIOD
#define LORA_DIO1_Pin GPIO_PIN_10
#define LORA_DIO1_GPIO_Port GPIOD
#define LOAR_DIO0_Pin GPIO_PIN_11
#define LOAR_DIO0_GPIO_Port GPIOD
#define LORA_RESET_Pin GPIO_PIN_12
#define LORA_RESET_GPIO_Port GPIOD
#define LCD_BLK_Pin GPIO_PIN_13
#define LCD_BLK_GPIO_Port GPIOD
#define LCD_D0_Pin GPIO_PIN_14
#define LCD_D0_GPIO_Port GPIOD
#define LCD_D1_Pin GPIO_PIN_15
#define LCD_D1_GPIO_Port GPIOD
#define KEY_4_Pin GPIO_PIN_6
#define KEY_4_GPIO_Port GPIOC
#define ML307_EN_Pin GPIO_PIN_7
#define ML307_EN_GPIO_Port GPIOC
#define KEY_3_Pin GPIO_PIN_8
#define KEY_3_GPIO_Port GPIOA
#define UART1_TX_Pin GPIO_PIN_9
#define UART1_TX_GPIO_Port GPIOA
#define UART1_RX_Pin GPIO_PIN_10
#define UART1_RX_GPIO_Port GPIOA
#define UART1_CTRL_Pin GPIO_PIN_11
#define UART1_CTRL_GPIO_Port GPIOA
#define KEY_2_Pin GPIO_PIN_12
#define KEY_2_GPIO_Port GPIOA
#define KEY_1_Pin GPIO_PIN_15
#define KEY_1_GPIO_Port GPIOA
#define LCD_D2_Pin GPIO_PIN_0
#define LCD_D2_GPIO_Port GPIOD
#define LCD_D3_Pin GPIO_PIN_1
#define LCD_D3_GPIO_Port GPIOD
#define SDIO_WP_Pin GPIO_PIN_3
#define SDIO_WP_GPIO_Port GPIOD
#define LCD_RD_Pin GPIO_PIN_4
#define LCD_RD_GPIO_Port GPIOD
#define LCD_WR_Pin GPIO_PIN_5
#define LCD_WR_GPIO_Port GPIOD
#define UART2_CTRL_Pin GPIO_PIN_6
#define UART2_CTRL_GPIO_Port GPIOD
#define LCD_CS_Pin GPIO_PIN_7
#define LCD_CS_GPIO_Port GPIOD

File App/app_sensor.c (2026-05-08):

/**
 * @file    app_sensor.c
 * @brief   传感器应用层实现 - 封装Modbus主机操作
 * @details 通过UART1(RS485)与水位传感器通信，读取距离数据
 *
 *          使用方法：
 *          1. 在系统初始化时调用 app_sensor_init()
 *          2. 创建FreeRTOS任务，每10ms调用一次 app_sensor_poll()
 *          3. 使用 app_sensor_get_distance() 获取距离值
 *          4. 使用 app_sensor_is_online() 检查传感器在线状态
 */

#include "app_sensor.h"
#include "app_config.h"
#include "app_log.h"
#include "modbus_master.h"
#include "global.h"
#include "usart.h"
#include "ct1820.h"
#include "FreeRTOS.h"
#include "task.h"
#include <string.h>

/*============================================================================*/
/*                           私有宏定义                                        */
/*============================================================================*/

/* 传感器配置 */
#define SENSOR_SLAVE_ID     SENSOR_ADDR_1     /* 从机地址 */
#define SENSOR_START_ADDR   SENSOR_REG_DISTANCE /* 距离寄存器地址 */
#define SENSOR_QUANTITY     SENSOR_REG_QUANTITY /* 轮询寄存器数量 */

/* 数据更新间隔 (ms) */
#define SENSOR_UPDATE_INTERVAL_MS    1000

/* 温度测量间隔 (ms) */
#define TEMP_UPDATE_INTERVAL_MS      10000

/* CT1820 转换等待时间 (ms) */
#define TEMP_CONVERT_WAIT_MS         800

/*============================================================================*/
/*                           私有变量                                          */
/*============================================================================*/

/**
 * @brief 传感器数据实例
 */
static SensorData_t g_sensor_data;

/**
 * @brief CT1820 温度轮询状态机
 */
static struct {
    uint8_t converting;         /**< 是否正在转换中 */
    uint32_t convert_start;     /**< 发起转换的时间戳 */
    uint32_t last_update;       /**< 上次完成测量的时间戳 */
} g_temp_state;

static uint8_t sensor_prev_online = 0;  /**< 上次传感器在线状态 */
static uint8_t sensor_first_sync_done = 0;  /**< 首次上线同步标志 */

/*============================================================================*/
/*                           私有函数声明                                      */
/*============================================================================*/

static void on_config_change_to_sensor(config_id_t id);
static void sync_all_params_to_sensor(void);

/*============================================================================*/
/*                           公共函数实现                                      */
/*============================================================================*/

/**
 * @brief  初始化传感器模块
 * @note   初始化Modbus主机并添加传感器设备
 */
void app_sensor_init(void)
{
    /* 清零传感器数据 */
    memset(&g_sensor_data, 0, sizeof(SensorData_t));

    /* 初始化CT1820温度传感器 */
    CT1820_Init();
    memset(&g_temp_state, 0, sizeof(g_temp_state));
    g_temp_state.last_update = HAL_GetTick() - TEMP_UPDATE_INTERVAL_MS - 1;  /* 确保首次poll立即启动转换 */

    /* 初始化Modbus主机 */
    modbus_master_init(&sensor_master, &huart1);

    /* 添加传感器设备到轮询列表 */
    modbus_master_add_sensor(&sensor_master,
                              SENSOR_SLAVE_ID,
                              SENSOR_START_ADDR,
                              SENSOR_QUANTITY);

    /* 注册参数变更同步回调 */
    app_sensor_register_config_callback();

    /* 首次同步延迟到传感器上线后再执行 */
}

/**
 * @brief  传感器轮询任务
 * @note   需要在FreeRTOS任务中周期性调用，建议10ms
 *
 *         工作流程：
 *         1. 调用Modbus状态机处理通信
 *         2. 每1秒更新一次本地数据缓存
 */
void app_sensor_poll(void)
{
    static uint32_t last_update_time = 0;

    /* 调用Modbus主机轮询状态机 */
    modbus_master_poll(&sensor_master);

    /* 每1秒更新一次数据缓存 */
    if (HAL_GetTick() - last_update_time >= SENSOR_UPDATE_INTERVAL_MS)
    {
        last_update_time = HAL_GetTick();

        uint8_t online = modbus_master_is_sensor_online(0);

        /* 检测在线状态变化，记录系统日志 */
        if (online != sensor_prev_online)
        {
            app_log_send(LOG_TYPE_SYSTEM,
                         online ? "SENSOR ONLINE" : "SENSOR OFFLINE");
            sensor_prev_online = online;

            /* 传感器首次上线时，同步所有配置参数 */
            if (online && !sensor_first_sync_done)
            {
                sensor_first_sync_done = 1;
                sync_all_params_to_sensor();
            }
        }

        if (online)
        {
            /* 先在局部变量准备数据 */
            uint16_t distance_mm = modbus_master_get_register_value(0, 0);
            float dist = distance_mm / 1000.0f;
            float level = 0.0f;
            uint32_t now = HAL_GetTick();

            if (distance_mm > 0)
            {
                float install_height_m = app_config_get_height() / 1000.0f;
                level = install_height_m - dist;
                if (level < 0.0f) level = 0.0f;
            }

            /* 临界区内一次性写入所有字段 */
            taskENTER_CRITICAL();
            g_sensor_data.distance_m = dist;
            g_sensor_data.water_level_m = level;
            g_sensor_data.last_update_time = now;
            g_sensor_data.is_online = 1;
            taskEXIT_CRITICAL();
        }
        else
        {
            taskENTER_CRITICAL();
            g_sensor_data.is_online = 0;
            taskEXIT_CRITICAL();
        }
    }

    /* CT1820 温度测量状态机 (每5秒一次) */
    if (g_temp_state.converting)
    {
        if (HAL_GetTick() - g_temp_state.convert_start >= TEMP_CONVERT_WAIT_MS)
        {
            int16_t temp;
            taskENTER_CRITICAL();
            temp = CT1820_GetTemp();
            taskEXIT_CRITICAL();
            if (temp != INT16_MIN)
            {
                taskENTER_CRITICAL();
                g_sensor_data.temperature_x10 = temp;
                g_sensor_data.temp_valid = 1;
                taskEXIT_CRITICAL();
            }
            else
            {
                taskENTER_CRITICAL();
                g_sensor_data.temp_valid = 0;
                taskEXIT_CRITICAL();
            }
            g_temp_state.converting = 0;
            g_temp_state.last_update = HAL_GetTick();
        }
    }
    else
    {
        if (HAL_GetTick() - g_temp_state.last_update >= TEMP_UPDATE_INTERVAL_MS)
        {
            taskENTER_CRITICAL();
            CT1820_StartConvert();
            taskEXIT_CRITICAL();
            g_temp_state.converting = 1;
            g_temp_state.convert_start = HAL_GetTick();
        }
    }
}

/**
 * @brief  获取距离值
 * @retval 距离值 (m)，传感器离线时返回0
 */
float app_sensor_get_distance(void)
{
    if (g_sensor_data.is_online)
    {
        return g_sensor_data.distance_m;
    }
    return 0.0f;
}

/**
 * @brief  获取温度值
 * @retval 温度值 x10 (如256=25.6°C), 0=传感器断线
 */
int16_t app_sensor_get_temperature(void)
{
    return g_sensor_data.temperature_x10;
}

/**
 * @brief  检查传感器是否在线
 * @retval 1: 在线
 * @retval 0: 离线
 */
uint8_t app_sensor_is_online(void)
{
    return g_sensor_data.is_online;
}

/**
 * @brief  获取传感器数据结构指针
 * @retval 传感器数据指针
 * @note   用于UI绑定显示
 */
SensorData_t* app_sensor_get_data(void)
{
    return &g_sensor_data;
}
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

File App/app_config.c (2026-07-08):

/**
 * @file app_config.c
 * @brief 系统配置管理源文件
 */

#include "app_config.h"
#include "app_flow_calc.h"
#include "at24c02.h"
#include "FreeRTOS.h"
#include "task.h"
#include "cmsis_os2.h"
#include "iwdg.h"
#include <string.h>

/* 全局配置实例 */
static SystemConfig_t g_config;

/*============================================================================*/
/*                           延迟保存机制                                       */
/*============================================================================*/

static volatile uint8_t config_dirty = 0;
static volatile uint8_t s_eeprom_busy = 0;  /* EEPROM操作互锁 (config/flow_calc共用) */
static uint32_t last_write_tick = 0;
#define CONFIG_SAVE_DELAY_MS   3000
#define CONFIG_LOAD_RETRY      5     /* 开机加载配置失败重试次数 */
#define CONFIG_SAVE_RETRY      3     /* 配置保存失败重试次数 */
#define CONFIG_LOAD_RETRY_MS   10    /* 读写重试间隔 */

/* 参数变更回调 (支持多个监听者) */
#define CONFIG_MAX_CHANGE_CB  4
typedef void (*config_change_cb_t)(config_id_t id);
static config_change_cb_t g_config_change_cbs[CONFIG_MAX_CHANGE_CB] = {NULL, NULL, NULL, NULL};

static void notify_config_change(config_id_t id)
{
    for (uint8_t i = 0; i < CONFIG_MAX_CHANGE_CB; i++)
    {
        if (g_config_change_cbs[i])
        {
            g_config_change_cbs[i](id);
        }
    }
}

/**
 * @brief 处理延迟保存请求
 * @note 需要在主循环中周期性调用
 *       当有脏数据且超过延迟时间后，执行EEPROM写入
 */
void app_config_process(void)
{
    if (!config_dirty)
    {
        return;
    }

    if (HAL_GetTick() - last_write_tick >= CONFIG_SAVE_DELAY_MS)
    {
        if (app_config_save()) {
            config_dirty = 0;
        }
    }
}

/*============================================================================*/
/*                           EEPROM互锁 (多模块共用)                            */
/*============================================================================*/

static uint32_t eeprom_lock_irq_save(void)
{
    uint32_t primask = __get_PRIMASK();
    __disable_irq();
    return primask;
}

static void eeprom_lock_irq_restore(uint32_t primask)
{
    if ((primask & 0x1U) == 0U) {
        __enable_irq();
    }
}

uint8_t app_config_eeprom_lock(void)
{
    uint32_t primask = eeprom_lock_irq_save();

    if (s_eeprom_busy) {
        eeprom_lock_irq_restore(primask);
        return 0;
    }

    s_eeprom_busy = 1;
    eeprom_lock_irq_restore(primask);
    return 1;
}

void app_config_eeprom_unlock(void)
{
    uint32_t primask = eeprom_lock_irq_save();
    s_eeprom_busy = 0;
    eeprom_lock_irq_restore(primask);
}

/*============================================================================*/
/*                           系统配置管理                                       */
/*============================================================================*/

/**
 * @brief 使用默认值初始化配置
 * @retval None
 */
void app_config_set_default(void)
{
    /* 保留工厂校准值（仅在已有有效配置时） */
    uint32_t saved_cal_4ma  = DEFAULT_CALIBRATION_4MA;
    uint32_t saved_cal_20ma = DEFAULT_CALIBRATION_20MA;
    if (g_config.magic_number == CONFIG_MAGIC_NUMBER) {
        saved_cal_4ma  = g_config.calibration_4ma;
        saved_cal_20ma = g_config.calibration_20ma;
    }

    memset(&g_config, 0, sizeof(SystemConfig_t));

    g_config.magic_number = CONFIG_MAGIC_NUMBER;

    // 基本参数
    g_config.range_max         = DEFAULT_RANGE_MAX;
    g_config.height            = DEFAULT_HEIGHT;
    g_config.calibration_4ma   = saved_cal_4ma;
    g_config.calibration_20ma  = saved_cal_20ma;
    g_config.range_4ma         = DEFAULT_RANGE_4MA;
    g_config.range_20ma        = DEFAULT_RANGE_20MA;
    g_config.point_num         = DEFAULT_POINT_NUM;

    // 测量参数
    g_config.window_width      = DEFAULT_WINDOW_WIDTH;
    g_config.filter_count      = DEFAULT_FILTER_COUNT;
    g_config.delay_time        = DEFAULT_DELAY_TIME;
    g_config.antenna_type      = DEFAULT_ANTENNA_TYPE;
    g_config.blind_area        = DEFAULT_BLIND_AREA;
    g_config.w_coeff           = DEFAULT_W_COEFF;
    g_config.m_coeff           = DEFAULT_M_COEFF;

    // Modbus从机参数
    g_config.modbusAddr        = DEFAULT_MODBUS_ADDR;
    g_config.modbusBaudRate    = DEFAULT_MODBUS_BAUD;
    g_config.modbusStopBits    = DEFAULT_MODBUS_STOP;

    // 报警参数
    g_config.alarm_ah          = DEFAULT_ALARM_AH;
    g_config.alarm_al          = DEFAULT_ALARM_AL;
    g_config.alarm_dh          = DEFAULT_ALARM_DH;
    g_config.alarm_dl          = DEFAULT_ALARM_DL;
    g_config.alarm_aah         = DEFAULT_ALARM_AAH;
    g_config.alarm_aal         = DEFAULT_ALARM_AAL;
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

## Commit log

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2026-03-06 feat(lvgl): 添加ST7789驱动并启用LVGL显示支持
    - 添加fsmc_st7789驱动文件，实现LCD初始化和绘图功能
    - 修改FSMC时序参数优化显示性能
    - 启用LVGL配置文件和显示端口文件
    - 更新Keil项目配置以包含新文件
    - 修改LVGL显示缓冲区大小为40行以提高性能
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2026-03-07 feat(modbus): 实现Modbus主站协议栈 1. 新增modbus.h/modbus.c提供基础协议功能 2. 实现modbus_master.h/modbus_master.c主站功能 3. 支持多从机轮询和自动重试机制 4. 提供完整的寄存器读写API 5. 实现CRC校验和帧处理功能 6. 支持RS485收发控制
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2026-03-12 feat: 更新LVGL配置
    更新LVGL配置文件，启用更多功能如日志、性能监控和内存监控。修复ST7789显示初始化参数和测试图案高度计算错误。移除不必要的编译中间文件。启用FreeRTOS支持并调整显示刷新逻辑。
    主要修改包括：
    - 调整LVGL颜色深度和内存配置
    - 启用系统监控和性能统计
    - 修复显示驱动初始化参数
    - 清理项目文件结构
    - 优化显示刷新性能
2026-03-12 feat: 完成LVGL和freeRTOS的结合 - 调整LVGL显示缓冲区大小和内存对齐配置 - 添加FreeRTOS任务切换跟踪功能 - 修改ST7789初始化命令关闭显示测试模式 - 优化LVGL刷新周期和内存配置 - 在主任务中初始化LVGL并运行基准测试
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2026-03-17 feat: 增加RTC时间模块集成并优化任务栈大小
    refactor(data_recorder): 使用RTC模块获取实时时间戳
    refactor(log_manager): 集成RTC时间模块替代硬编码时间
    fix(freertos): 调整测试任务栈大小至512*4字节
    chore: 更新MDK-ARM工程调试断点配置
    [app_log.c, global.h]
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2026-03-17 feat(ui): 添加UI模块基础框架和设置页面 实现UI模块的基础框架，包括： 1. 添加UI管理结构体和相关配置 2. 实现主页面和设置页面的基本布局 3. 集成LVGL图形库并启用48号字体 4. 在FreeRTOS任务中初始化UI系统 5. 添加UI模块到项目构建系统
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2026-03-18 feat(app_model): 实现应用数据模型和MVVM架构
    添加应用数据模型模块，支持MVVM架构：
    1. 新增app_model.c/h实现数据模型核心功能
    2. 在ui_conf.h中添加LVGL Subject定义
    3. 实现数据绑定和自动更新机制
    4. 添加UI_DATA_ARCHITECTURE.md文档说明架构设计
    5. 更新项目文档和构建配置
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2026-03-23 feat(传感器): 添加Modbus主机通信功能及传感器应用层
    实现Modbus RTU主机功能，支持通过RS485轮询外部传感器
    - 新增app_sensor应用层，封装传感器数据读取逻辑
    - 修改USART1波特率为9600以适应传感器
    - 添加modbus任务到FreeRTOS调度
    - 优化CRC16计算算法为标准位运算法
2026-03-24 fix(modbus): 优化DMA接收缓冲区处理逻辑
    减少DMA接收缓冲区大小至128字节，足够容纳Modbus RTU帧
    在发送请求前重置DMA接收状态，避免旧数据残留
    增加DMA缓冲区清除操作，确保每次接收前为干净状态
    [modbus_master.c]
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2026-03-25 feat: 添加流量计算模块并集成到系统
    - 新增app_flow_calc模块实现巴歇尔槽流量计算
    - 在FreeRTOS中添加流量刷新定时器
    - 更新数据模型包含瞬时和累计流量
    - 修改UI显示流量数据
    - 修复默认枚举值从0改为1的问题
    - 更新项目配置文件和文档
    [OCFM_V2.ioc, app_flow_calc.c, global.h]
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2026-03-27 feat(流量计算): 增加累计时长功能并重构相关模块
    重构流量计算模块，增加累计时长功能：
    1. 在流量计算模块中添加累计时长统计
    2. 修改备份寄存器和EEPROM存储结构以支持累计时长
    3. 更新数据模型和应用层接口
    4. 调整UI相关变量命名和显示逻辑
    5. 优化Modbus主站重试次数配置
    6. 修复文件结尾缺少换行符问题
    [app_flow_calc.c]
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2026-03-30 feat(modbus): 新增Modbus从机功能实现
    - 实现Modbus从机功能，支持UART2通信
    - 新增app_modbus_slave模块处理寄存器与业务数据映射
    - 优化寄存器存储结构，使用紧凑数组和地址映射表
    - 增加DMA+空闲中断接收模式，提高通信效率
    - 支持32位/浮点/双精度数据类型寄存器操作
    - 添加配置参数延迟保存机制
    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
2026-03-31 feat(ui): 重构设置页面为动态创建模式
    - 将设置页面从静态初始化改为动态创建
    - 新增设置页面入口和退出函数
    - 实现设置页面按钮事件处理逻辑
    - 更新UI管理器初始化代码
    - 添加设置页面头文件和函数声明
2026-03-31 docs: 添加超声波流量计原理图和液晶屏铁框技术文档
    [485.SchDoc, 4~20ma.SchDoc, MCU(ZC-ST4X-A005A).PcbDoc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]
2026-03-31 feat(ui): 添加参数编辑页面的步进调整和高亮显示功能
    在参数编辑页面中：
    1. 添加步进值列表和索引管理，支持1/10/100/1000/10000步进调整
    2. 使用LVGL recolor功能高亮显示当前步进对应的数字位
    3. 修改SHIFT键功能为步进切换而非取消编辑
    4. 更新底部提示文字和编辑值显示逻辑
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2026-04-01 fix(ui): 修复数值显示时步进高亮位计算错误并添加前导零
    优化数值显示逻辑，确保不同步进值时显示宽度一致。主要修改包括：
    1. 根据最大步进值计算位数并添加前导零
    2. 修正步进高亮位计算逻辑
2026-04-01 feat(ui): 为设置页面添加值格式化回调功能
    - 在set_item_t结构中新增format回调函数，支持自定义值显示格式
    - 为语言选项添加format_language回调，显示"English/Chinese"而非数字
    - 根据format回调自动调整编辑页面的字体大小
    - 修复页面初始化时选中项高亮显示的问题
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2026-04-01 fix: 交换OK和SHIFT按钮的长按功能
    将BUTTON_ID_OK和BUTTON_ID_SHIFT的长按事件处理逻辑互换，以修正按钮功能分配错误
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2026-04-01 feat(modbus): 添加RTC时间设置功能
    在Modbus从机协议中增加RTC时间设置寄存器(0x0200-0x0206)，支持通过Modbus协议设置和读取RTC时间。同时在UI设置页面添加时间设置菜单，允许用户通过界面修改时间参数。
    修改内容包括：
    1. 在global.h中定义RTC时间寄存器地址
    2. 在modbus_slave.c中扩展寄存器映射表
    3. 在app_modbus_slave.c中添加RTC时间处理逻辑
    4. 在ui_set_page.c中添加时间设置菜单项
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2026-04-02 feat(Modbus): 添加清除累计流量寄存器功能
    在Modbus从机中新增REG_CLEAR_TOTAL寄存器(0x1007)，用于通过写1触发清除累计流量和时间。同时在设置页面添加"Clear Total"选项，允许用户通过UI执行清零操作。
    修改包括：
    1. 在global.h添加寄存器定义
    2. 在app_modbus_slave.c处理写操作
    3. 在modbus_slave.c更新寄存器映射表
    4. 在ui_set_page.c添加设置项界面
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2026-04-02 fix(app_flow_calc): 仅在传感器在线时累计时长
    调整累计时长增加的逻辑，确保仅在传感器在线时增加s_total_time_sec
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2026-04-03 feat(配置/UI): 将4mA和20mA量程类型从uint32改为float
    修改配置参数和UI界面以支持浮点数量程，包括：
    - 修改全局配置结构和默认值
    - 更新配置获取/设置函数接口
    - 添加Modbus浮点数寄存器支持
    - 扩展UI设置项结构支持浮点数路径
    - 实现浮点数编辑和显示逻辑
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2026-04-04 refactor(app_config): 重构配置管理系统，统一参数访问接口
    - 移除旧的寄存器映射表(SET_TABLE)和相关函数
    - 新增config_id_t枚举定义所有配置参数ID
    - 实现统一的配置参数访问API(app_config_set/get/getf)
    - 整合延迟保存机制到app_config_process()
    - 修改UI和Modbus模块使用新API访问配置
    - 优化EEPROM写入防止并发冲突
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2026-04-07 feat(电流输出): 实现4-20mA电流输出功能
    重构电流输出模块，使用TIM3 PWM驱动外部V/I电路
    - 修改TIM3配置为ARR=1999, OCPOLARITY_LOW
    - 增加app_current_init初始化函数
    - 实现app_current_update更新PWM输出
    - 在main_task和flow_refresh_fun中集成电流输出
    - 更新温度采样间隔为10秒
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2026-04-07 feat(ui): 添加水位标签离线状态显示功能
    当传感器离线时，水位标签显示红色并显示"error"文本，在线时恢复青绿色。添加状态追踪变量以检测在线状态变化。
2026-04-07 feat(alarm): 新增流量报警模块实现四路继电器控制
    实现基于瞬时流量的四路继电器报警控制功能，包括：
    - 上限/下限报警（带回差逻辑）
    - 上上限/下下限报警
    - 报警状态管理及继电器控制
    - 提供Modbus接口获取继电器状态
    - 支持手动控制继电器用于测试
2026-04-08 feat(报警模块): 添加流量报警功能及4-20mA输出支持
    - 新增 app_alarm 模块实现4级流量报警控制
    - 在UI设置页面添加报警阈值配置项
    - 更新文档说明报警模块和4-20mA输出功能
    - 调整项目文件配置包含新增模块
2026-04-08 feat(ui): 添加线程安全的异步UI操作接口
    实现通过FreeRTOS队列传递异步请求，解决按键任务直接调用LVGL异步函数导致的线程安全问题。新增ui_async模块提供安全接口替代lv_async_call，修改所有相关调用点使用新接口。同时初始化时确保温度传感器首次轮询立即启动转换。
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2026-04-09 fix: 修复数据清理日期下溢问题并增强输入校验
    修复data_cleanup函数中日期下溢问题，当keep_days大于当前日期时保留当月数据
    修正水位计算逻辑，避免负值传入流量计算
    增强RTC时间校验，增加月份天数合法性检查
    修正流量单位转换错误，补充G_H单位计算系数
    添加channel_id范围校验，防止越界访问
    优化EEPROM写入策略，改为延迟写入避免阻塞
    [app_flow_calc.c, app_modbus_slave.c, app_sensor.c]
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2026-04-09 fix(global): 修正默认量程和报警参数值
    style(ui): 为流量容器添加左侧边框样式
    [global.h]
2026-04-09 feat(ui): 添加底栏报警指示功能并优化界面布局
    - 在ui_conf.h中添加底栏报警相关控件定义
    - 实现报警状态检测与显示逻辑，支持HH/H/L/LL四级报警
    - 重构底部栏为三栏布局（电流|报警|温度），无报警时自动隐藏中间栏
    - 优化流量显示区域的样式和布局
    - 调整顶部栏和底部栏的边距与对齐方式
2026-04-09 fix(ui): 修改底栏背景色为深灰色
    style: 更新单位显示为m³/h
    refactor: 禁用性能监控和内存监控
    style: 调整编辑界面字体设置
    chore: 更新IDE窗口布局配置
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2026-04-13 feat(ui): 添加多语言支持功能
    实现设置菜单的中英文双语支持，包括：
    1. 新增ui_lang模块管理翻译字符串和字体选择
    2. 添加Noto Sans SC中文字体文件
    3. 重构设置菜单使用lang_id_t枚举获取翻译文本
    4. 更新文档说明多语言配置方法
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2026-04-13 fix(ui): 为format类型添加循环设置功能
    当编辑值达到最大值时循环到最小值，反之亦然，确保format类型的值可以循环设置
2026-04-13 fix(ui): 修正串口停止位校验选项的显示文本
    将串口配置中停止位和校验位的选项显示从简写改为完整描述，提高可读性
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2026-04-14 fix: 修复流量计算和EEPROM锁问题
    - 在freertos.c中统一使用flow_m3h变量确保单位一致
    - 在app_config.c中改进EEPROM锁机制，添加中断保护
    - 更新.gitignore移除不必要的中间件目录
    - IDE窗口位置配置变更
    [app_config.c]
2026-04-14 feat(ui): 添加密码验证界面功能
    实现进入设置菜单前的密码验证界面，包含以下功能：
    - 4位数字密码输入，支持UP/DOWN调整数字，SHIFT切换位数
    - 密码正确进入设置菜单，错误显示提示
    - 15秒无操作自动返回主屏幕
    - 长按SHIFT可取消验证返回主屏幕
    - 集成到现有按键处理系统中
    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
2026-04-15 fix(报警模块): 修复传感器离线时的报警处理逻辑
    修改报警模块处理逻辑，当传感器离线时解除所有报警状态
    调整报警触发条件为包含等于阈值的情况
    新增传感器在线状态参数，离线时不触发新报警
    [app_alarm.c, app_config.c, modbus_master.c]
2026-04-15 feat(电流控制): 添加PWM校准模式功能
    实现电流输出的校准模式，允许在设置界面直接编辑PWM的CCR值
    - 新增 app_current_set_calibration() 和 app_current_exit_calibration() 接口
    - 在校准模式下跳过正常的PWM更新逻辑
    - 在UI设置页面中处理校准参数的编辑状态
2026-04-15 fix: 调整TIM3定时器参数和校准值
    更新TIM3定时器的预分频值和周期值，从41/1999调整为10/7999
    修改4mA和20mA的默认校准值为1150和4355
    [OCFM_V2.ioc, app_current.c, global.h]
2026-04-16 fix(电流校准): 增加校准模式超时检测功能并修复UART发送问题
    增加校准模式10秒无操作自动退出功能
    修复UART发送尾部字节可能被截断的问题
    限制4mA和20mA校准值的输入范围
    [app_current.c, app_modbus_slave.c, modbus_master.c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]
2026-04-16 fix(电流校准): 修复Modbus路径校准模式超时问题
    feat(传感器): 添加首次上线同步配置参数功能
    refactor(UI): 重构趋势图显示逻辑和布局
    style(全局): 调整20mA量程默认值精度
    [app_current.c, app_modbus_slave.c, app_sensor.c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]
2026-04-17 feat(ui): 为趋势图添加Y轴刻度标签并优化系列绘制顺序
    refactor: 移除未使用的变量并修正累计流量计算变量名
    fix(global): 将密码锁默认状态改为禁用
    docs: 精简并优化项目文档结构
    chore: 清理调试断点配置
    [app_flow_calc.c, global.h]
2026-04-17 fix(报警逻辑): 修复报警恢复条件并添加关联校验
    修改上上限和下下限报警的恢复条件，使其使用各自的回差值
    在配置设置中添加报警阈值之间的关联校验
    更新UI配置变更回调以包含恢复出厂设置事件
    [app_alarm.c, app_config.c]
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2026-04-17 feat: 添加瞬时流量格式化函数以限制小数位数
    添加新的格式化函数用于处理瞬时流量显示，当整数位数较多时自动减少小数位数以保持显示清晰。主要包含以下功能：
    1. 新增 count_integer_digits_from_string 函数用于计算字符串中的整数位数
    2. 新增 limit_instant_flow_decimals 函数根据整数位数限制小数位数
    3. 新增 format_instant_flow 函数替代原有简单格式化逻辑
2026-04-20 fix(modbus): 修复UART重配置和从机地址更新问题
    添加轻量级UART接收重启函数，优化通信参数更新处理流程
    增加配置变更回调重复注册检查，支持最多4个监听者
    修复寄存器写入范围检查逻辑，确保参数更新安全应用
    [app_config.c, app_modbus_slave.c, modbus_slave.c]
2026-04-20 fix(app_config): 设置CANALS_TYPE时自动设置channel_id为1
    refactor: 清理.claude/worktrees下的过期工作树
    chore: 更新.claude/settings.local.json的配置
    style: 调整MDK-ARM工程窗口位置参数
    [app_config.c]
2026-04-20 fix(配置): 修复通道编号范围限制问题并更新流量单位
    修改通道编号的最大值限制逻辑，使其根据水渠类型动态调整：
    - 巴歇尔槽保持16个通道
    - 三角堰限制为5个通道
    - 矩形堰限制为4个通道
    同时将默认瞬时流量单位从L/s改为m³/h
    [app_config.c, global.h]
2026-04-21 feat(ui): 添加累计流量设置功能并优化UI显示
    在系统设置中添加累计流量参数项，支持通过Modbus设置累计流量值
    - 在ui_lang.h和ui_lang.c中添加累计流量多语言文本
    - 在app_flow_calc.h/c中新增flow_calc_set_total函数
    - 在app_modbus_slave.c中处理Modbus写入累计流量寄存器
    - 在ui_set_page.c中实现累计流量编辑界面，支持大数值显示和步进调整
    - 优化字体配置，禁用部分不常用的大字体以节省资源
2026-04-21 fix(ui): 修正通道ID格式化函数显示问题
    docs: 更新文档说明新增字体合并脚本和多语言系统
2026-04-22 fix(modbus): 修复DMA接收缓冲区溢出问题并添加UART错误自动恢复机制 feat(ui): 调整4mA和20mA校准参数范围及修改屏幕加载动画 chore: 更新MDK-ARM工程配置文件
    [modbus_master.c]
2026-04-22 feat(ui): 新增历史记录查询界面功能
    - 添加ui_history模块实现历史记录查询界面
    - 增加历史记录相关多语言支持
    - 修改log_task栈大小以支持历史查询功能
    - 优化文件读取和CSV解析逻辑
    - 增加历史记录测试数据文件
    - 修改主界面长按SHIFT键触发历史界面
    [22.CSV]
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2026-04-23 fix(ui): 修复历史记录查询中的竞态条件并优化流程显示
    重构历史记录查询处理逻辑，引入查询序列号防止竞态条件
    将流量单位字符串改为固定值"m³/h"显示
    优化查询处理为单遍扫描同时计数和收集数据
    添加定时器管理和控件引用清理的辅助函数
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2026-04-27 fix(flow_calc): 修正流量单位转换公式错误 refactor(button): 简化长按释放时的状态处理 chore: 更新IDE窗口位置配置
    [app_flow_calc.c, button_driver.c]
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2026-05-06 fix: 调整EEPROM存储地址并优化传感器数据显示逻辑
    调整累计流量的EEPROM存储地址以避免与配置区冲突，确保数据对齐。优化传感器数据显示逻辑，将水位和温度字符串格式化移至传感器在线判断内，减少冗余代码。
2026-05-06 fix(flow_calc): 修复流量计算中的无效数据检查逻辑
    refactor(ui): 更新界面参数名称以更准确描述功能
    [app_flow_calc.c]
2026-05-06 feat(flow_calc): 更新明渠流量计算公式文档并调整字体字符集
    docs: 添加明渠流量计算公式手册文档
    refactor(app_flow_calc): 优化三角堰和矩形堰计算逻辑，增加Kh修正参数
    style(ui/font): 更新字体字符集，新增"频率加权平均阻尼"等字符
    [app_flow_calc.c]
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2026-05-08 fix(ui): 更新字体文件添加"距"字符并调整UI设置页面
    更新chars.txt和字体文件添加"距"字符支持
    删除不再使用的check_chars.py脚本
    调整ui_set_page.c中通道ID和小数点设置的格式函数参数
    更新IDE窗口位置和文件状态记录
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2026-05-09 fix(modbus): 调整从机寄存器更新频率为200ms避免重复读取
    将modbus从机任务的寄存器更新频率从1秒调整为200ms，避免与flow_calc_update(1s)同频导致读取重复值的问题
2026-05-11 fix: 优化modbus校准配置处理与默认配置保留逻辑
    1. 合并4mA和20mA校准配置的校验逻辑
    2. 新增一次性动作寄存器清零处理
    3. 恢复默认配置时保留工厂校准值
    4. 移除配置参数的范围校验限制
    [app_config.c, app_modbus_slave.c]
2026-05-13 fix: 修复高度配置同步与流量计算逻辑问题
    1. 配置高度时限制其不超过量程最大值
    2. 量程变更时同步更新高度值
    3. 修复设置页面高度项的最大取值逻辑
    4. 改用实际水位值计算理论最大流量而非预存范围值
    [app_config.c, app_flow_calc.c]
2026-05-14 fix(app_modbus_slave): 优化水位值转换精度，添加四舍五入处理
    将水位值从米转换为毫米时，通过+0.5f实现四舍五入，避免直接截断导致的精度丢失
2026-05-18 fix: 修正RTC星期显示和设置的偏移问题，调整4/20mA校准范围
    1. 修复modbus从机和UI中的RTC星期数值偏移错误，统一星期的1-7对应格式
    2. 调整4mA和20mA校准的参数范围为0-7999
    3. 附带Keil工程窗口布局的自动更新变动
    [app_modbus_slave.c]
2026-05-21 fix: 调整定时器参数、串口字长及校准默认值
    1. 调整TIM3预分频器和重载值以修改定时器周期
    2. 根据串口奇偶性动态配置UART2字长
    3. 更新ADC校准默认参数值
    4. 更新MDK工程UI布局配置
    [app_modbus_slave.c, global.h]
2026-05-26 feat: add channel width and weir height config support
    添加渠宽和堰高的配置项，包含UI多语言显示、系统配置参数、Modbus寄存器映射，以及流量计算中加入渠宽修正逻辑，设置默认值为0表示未配置状态
    [app_config.c, app_flow_calc.c, app_log.c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]
2026-05-26 fix(file driver): add sd card presence check for all file operations
    新增文件驱动的SD卡在位检测逻辑，在各文件操作接口中先检查SD卡状态，当SD卡拔出时重置挂载和打开标志并返回对应错误，避免无效的文件系统操作
2026-05-26 fix: 修复SD卡插拔检测时的资源清理逻辑
    新增SD_FlushQueue函数清空SD消息队列，重构file_unmount函数统一处理资源卸载，替换原有的简单置零操作，确保SD卡异常时正确关闭文件、卸载挂载并重置SD外设
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2026-06-04 fix(tim): 调整TIM3预分频器数值以修正计时精度
    将TIM3预分频器从2修改为29，优化定时器计数匹配的实际效果
2026-06-04 fix(app_flow_calc): adjust flow max margin from 110% to 120%
    - 更新了流量最大值裕量系数，从1.1倍改为1.2倍
    - 同步更新了文档注释中的说明内容
    [app_flow_calc.c]
2026-06-04 chore: 更新项目文档与配置，清理冗余代码
    1. 移除app_config.h中CONFIG_ERR_READONLY宏定义
    2. 移除global.h中冗余的传感器地址、寄存器宏定义与注释
    3. 更新app_current.c中的TIM3配置参数与删除私有宏定义
    4. 更新README.md：修正功能特性、任务栈、寄存器映射等文档内容
    5. 补充未实现功能标注与菜单交互细节
    [app_current.c, global.h]
2026-06-09 docs: 修正报警回差描述、水位下限寄存器地址，补充矩形堰侧收缩修正文档
    - AAH/AAL 恢复条件从'无回差'改为'与AH/AL共用DH/DL'（注释/文档修正）
    - REG_WATER_LEVEL_DOWN 地址 0x010C → 0x010D（上限占两个寄存器）
    - Modbus寄存器表补充渠宽/堰高/水位上下限寄存器说明
    - flow_calc_formulas.md 新增水位上下限来源说明和矩形堰侧收缩修正公式
    - 校准默认值更新为 1006/3811
    [app_alarm.c, global.h]
2026-06-09 fix: 修复浮点精度导致的水位下限误判问题
    给水位下限判断增加0.1mm浮点容差，避免浮点运算后略低于阈值却被误判为低于下限的情况，同时更新了相关注释说明。
2026-06-09 fix(app_config): 修正4-20mA量程校验逻辑与注释
    更新了量程校验的注释描述，将校验范围扩展到4mA和20mA两个配置项，调整了裕量计算说明
2026-06-10 fix(flow calc): 修正流量计算的水位钳位逻辑和参数匹配
    1. 调整parshall_flow_Ls、triangular_weir_flow_Ls、rectangular_weir_flow_Ls三个函数的水位判断逻辑，将水位高于上限的情况提前处理并钳位到上限计算
    2. 修正矩形堰流量计算中有效宽度的参数使用，匹配当前水位而非上限值
    3. 更新注释说明，修正示例数值并完善边界处理的说明
    [app_flow_calc.c]
2026-06-14 fix: 修复传感器误判离线及恢复默认配置的校准值保护
    modbus_master: PROCESSING状态传感器轮询响应无效(CRC错/异常码/帧过短)分支补上last_poll_time更新，与超时/成功路径对齐。原遗漏导致poll_interval节流失效，在线时退化为~60ms高频重试，retry_count不到1秒即达MODBUS_MAX_RETRY(10)，485线路抖动时秒级误判传感器离线并显示error。修复后恢复1秒轮询节奏，约10秒持续异常才判离线。
    app_config: set_default仅在配置有效(magic_number匹配)时保留工厂校准值，否则使用DEFAULT_CALIBRATION_4MA/20MA，避免配置区为垃圾数据时读到无效校准值。
    [app_config.c, modbus_master.c]
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2026-06-14 docs: update flow calculation docs and fix triangular weir Kh value
    1. 修正三角堰水头修正Kh的单位混淆错误，更新为ISO 1438标准值
    2. 补充流量公式的标准出处与合规验证文档
    3. 更新巴歇尔槽参数表的标准依据为CJ/T 3008.3-1993
    4. 新增完整的流量计算公式说明文档
    [app_flow_calc.c]
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2026-06-16 fix: 修正多个配置和硬件相关问题
    1. 调整USART1 GPIO上拉设置
    2. 增加通道编号上限注释并调整至25
    [app_config.c, app_modbus_slave.c]
2026-06-18 docs: 更新项目文档与修复多处隐患
    1. 扩容data_recorder.c的临时缓冲区避免越界
    2. 给modbus主机发送流程添加超时防止卡死
    3. 给modbus从机0x10功能添加帧完整性校验
    4. 补全README与流量计算文档的标准说明
    5. 新增CSV数据记录与报警标志文档
    [modbus_master.c, modbus_slave.c]
2026-06-22 feat(flow-calc): 实现矩形堰Kindsvater-Carter高精度计算方法
    1. 新增矩形堰Ce流量系数与Kb宽度修正查表插值实现
    2. 重构矩形堰流量计算逻辑，支持ISO 1438-1标准KC算法与Francis回退
    3. 更新巴歇尔槽参数表，补充24/25号大型槽注释与50ft标注
    4. 完善流量计算公式文档，新增计算逻辑、精度说明与合规对应内容
    [app_flow_calc.c]
2026-06-23 feat: 完善Modbus从机协议实现与文档
    1. 新增寄存器可写性检查接口并实现协议层拦截
    2. 重构Modbus写入回调逻辑，支持整组RTC写入校验
    3. 拆分寄存器映射表，优化寄存器读写权限管理
    4. 修复矩形堰系数计算的数组作用域问题
    5. 新增完整Modbus通信协议文档
    [app_flow_calc.c, app_modbus_slave.c, modbus_slave.c]
2026-06-29 docs: add multiple project documents and optimize UI screen transition
    1. 新增多个项目文档，包括明渠流量计算手册、4G模块相关文件、Modbus协议说明、PCB工程文件等
    2. 优化参数页面切换动画，将淡入动画改为右滑平移以降低STM32F407上的性能开销
    3. 更新MDK-ARM工程配置文件的窗口布局和文件索引信息
    [485.SchDoc, 4g.PrjPcb, 4g.SchDoc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]
2026-07-01 fix(ui): 编辑页返回参数列表改用瞬切消除横向撕裂
    编辑页(详情页)按OK/长按SHIFT/SD清除完成返回参数列表时,原 MOVE_RIGHT 横向平移
    会让无 TE 帧同步的逐 chunk 刷屏相位错位被肉眼捕捉为撕裂带。改为按来源层级区分:
    从编辑页返回用 LV_SCREEN_LOAD_ANIM_NONE 瞬切(无横向运动,静态画面相位错位不可察觉),
    从分类列表进入仍维持 MOVE_RIGHT。
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2026-07-03 docs: 更新4-20mA校准值的默认参数
    更新了Modbus示例文档、寄存器表、硬件说明文档和用户手册中的4mA和20mA校准默认值，从1006/3811改为1063/5556，同步修正了对应的CRC校验值和有效步数计算。
2026-07-08 fix(config): EEPROM配置读写增加重试与看门狗保护
    - 开机加载: 读失败或magic无效时重试5次，每次读前喂狗
    - 保存配置: 写失败重试3次，每次写前喂狗，持锁重试防止flow_calc抢总线
    - magic校验移入加载重试循环，应对I2C瞬态读到脏数据
    [app_config.c]
2026-07-08 docs: 将项目中的AT24C02替换为M24C02
    更新了README、文档、驱动代码和配置文件中的EEPROM型号描述，修正了所有相关的注释和说明文本，统一项目中EEPROM的型号命名。

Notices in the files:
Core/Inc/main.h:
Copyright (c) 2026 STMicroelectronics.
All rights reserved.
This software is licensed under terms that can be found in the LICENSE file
